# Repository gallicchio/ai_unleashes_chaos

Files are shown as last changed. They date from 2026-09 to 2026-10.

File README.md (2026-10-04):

# AI UNLEASHES CHAOS

[Lorenz Attractor Circuit](https://seti.harvard.edu/unusual_stuff/misc/lorenz.htm) by Paul Horowitz in KiCAD

"Claude, I want you to build a nice little present for Paul Horowitz, which could also live on as an open source project and a kit that people could build. Make a KiCAD 10 project, schematic, and PCB to implement [Paul's Lorenz Attractor Circuit](https://seti.harvard.edu/unusual_stuff/misc/lorenz.htm)."

<!-- GitHub strips <iframe> from READMEs, so a video cannot play in place;
     this is the thumbnail with a play button, linked to YouTube. -->
<p align="center">
  <a href="https://youtu.be/pzk5cd-qo5U" title="Watch on YouTube">
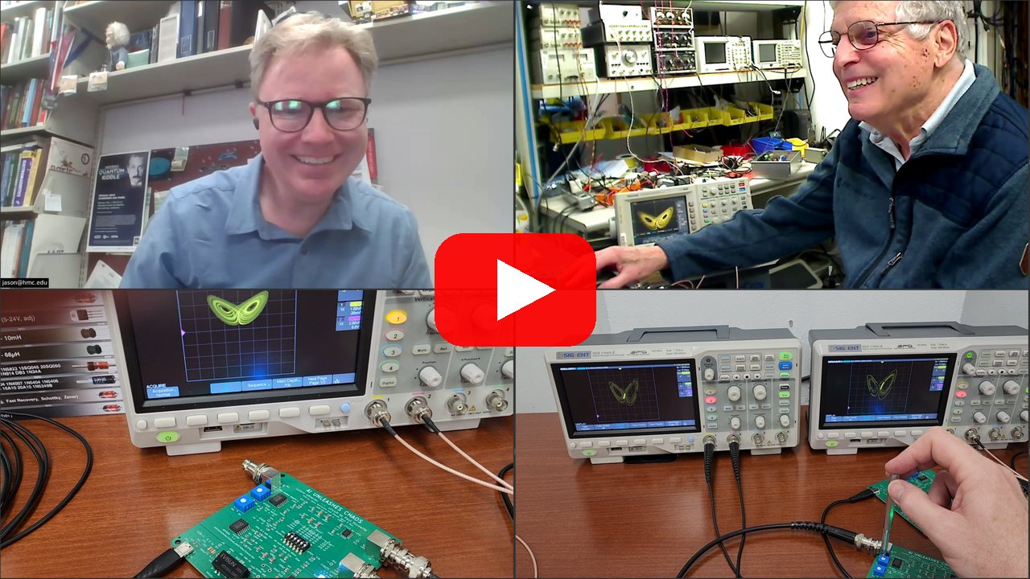
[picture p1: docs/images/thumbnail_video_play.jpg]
Watch the video on YouTube
    
  </a>
  <br>
  <a href="https://youtu.be/pzk5cd-qo5U"><b>&#9654; Watch on YouTube</b></a>
</p>

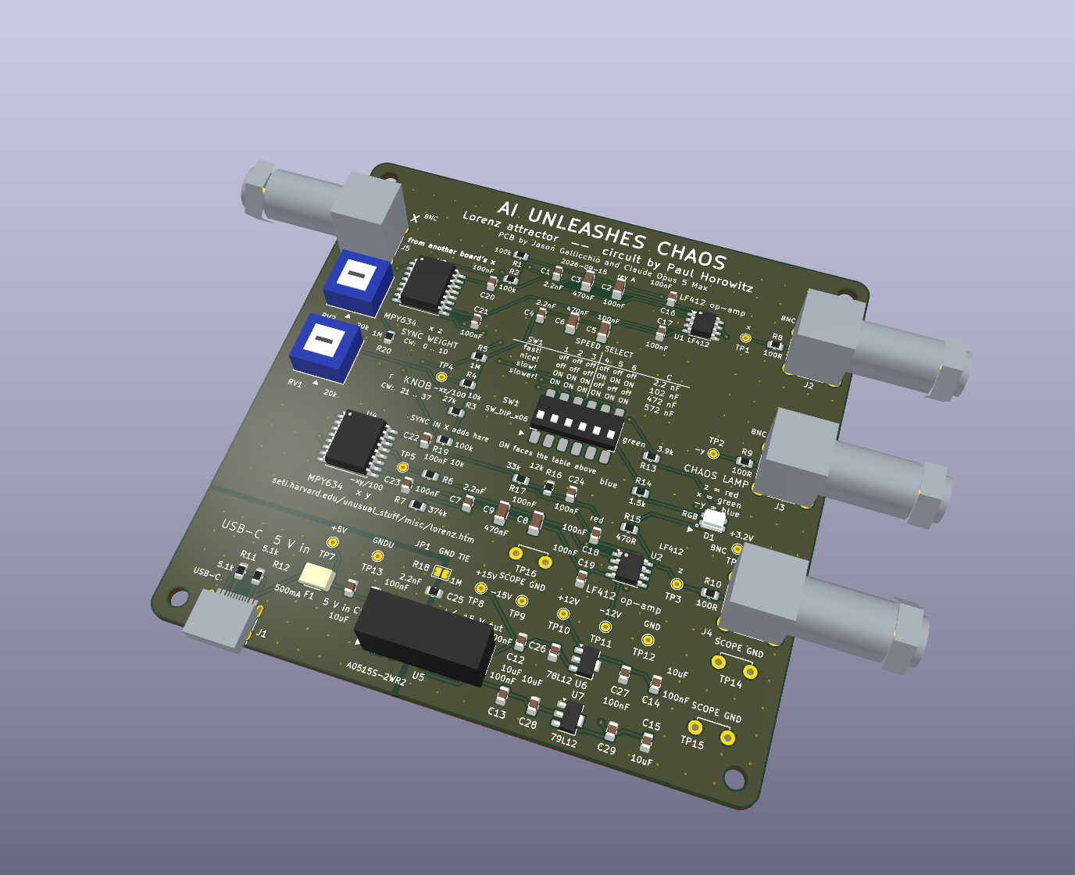
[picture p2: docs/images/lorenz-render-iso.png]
The board


In graduate school I worked with Paul Horowitz, of [Art of Electronics](https://artofelectronics.net/) fame. I even contributed a few bits and pieces to the 3rd edition. (I am thanked in the footnotes, one of which simply says, "Jason, again.") This project started by [asking Claude](CLAUDE_CODE_CHAT.md) the above question. Watch his reaction above. Also watch Paul's [Interview with Ladyada](https://www.youtube.com/watch?v=iCI3B5eT9NA) to get a sense for the guy.

**Only Prompts:**
As an experiment, the entire PCB, along with additions to Paul's original circuit were designed in a few
hours of [prompts to Claude Opus 5 Max](CLAUDE_CODE_CHAT.md). I only typed prompts.
I only used KiCAD to look at the output of Claude's [python scripts](scripts/), which generated everything else.

## What it is

A 100 x 100 mm, two-layer, USB-C-powered analog computer that solves

    dx/dt = s (y - x)          s = 10
    dy/dt = r x - y - x z      r = 21.3 .. 37.0, on a knob
    dz/dt = x y - b z          b = 8/3

in real time, continuously, with three op-amp integrators and two **MPY634**
analog multipliers — Paul's exact parts, in hand-solderable packages, so the
circuit stays literally his. Hang a scope on `x` and `z` in X-Y and the
attractor's "owl's face" appears within a second of power-up.

**Fun additions to Paul's original circuit:**

* **Four speeds on a DIP switch** — `fast!` (τ = 2.2 ms) through `slower!`
  (572 ms), the six sliders reading left to right as a two-digit binary
  number. At `slower!` you can follow the dot around a wing by eye.
* **An r knob.** 21.3 to 37.0 on a single-turn trimmer, which takes you from
  "the trace spirals into one wing and stops" through the bistable window at
  r ≈ 24.1–24.7 and Lorenz's own 28, to a tight fast orbit at 37. Its wiper is
  tied to one end of the track on purpose: grit under a wiper then means
  *maximum resistance*, never an open circuit.
* **A chaos lamp.** One RGB LED whose colour is the state vector. Red
  follows −y, green x and blue z, and two more resistors pull red's and
  blue's thresholds apart so the dies take turns instead of mixing to
  white: it is vivid nine-tenths of the time and visits every hue about
  equally. Rev A's lamp was picked from [660 rendered wirings](docs/lamp/)
  with an LED model the boards then proved wrong — it came out mostly blue —
  so rev B's was chosen again with a corrected model, from 6.7 million
  wirings; [the ten finalists play in real time](docs/lamp2/).
* **A real isolated ground split.** The DC/DC converter's isolation is
  actually used: analog ground and USB ground are separate pours with a 1 mm
  gap, bridged only by 1 M, 2.2 nF and a solder jumper, so no mains-referenced
  loop runs through a signal whose full scale is 2 V.
* **`SYNC IN X`.** A fourth BNC and a weight knob: feed it another board's `x`
  output and the two boards synchronise — chaotic synchronisation on the
  bench. Pull
  the cable and they diverge again from states that agreed to a few
  millivolts. The knob is linear in coupling strength from 0 to 10, with the
  locking threshold at about 70 % of rotation.
**Everything here is generated.** There is no hand-edited schematic or board:
`./make.py` writes the symbols, footprints, 3D models, schematic, placement,
routing, silkscreen, gerbers, BOM and CPL from Python, and then checks them.
147 circuit assertions read the exported netlist back and re-derive the
equations from the resistors that are really attached, and simulate the lamp
the netlist really builds; the QR codes on the
back are decoded out of the gerbers they were plotted into; and a clean clone
rebuilds every deliverable byte-identically.

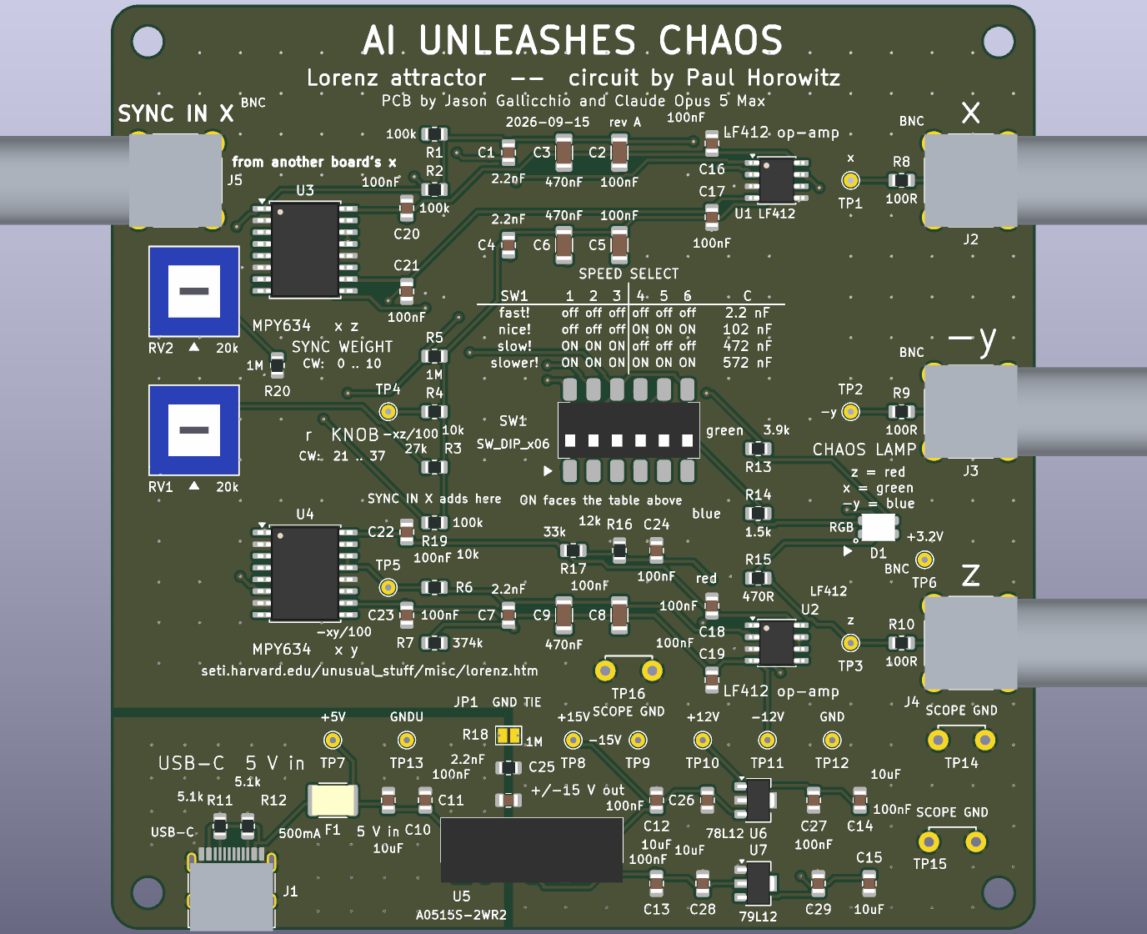
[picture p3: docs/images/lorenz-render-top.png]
Front

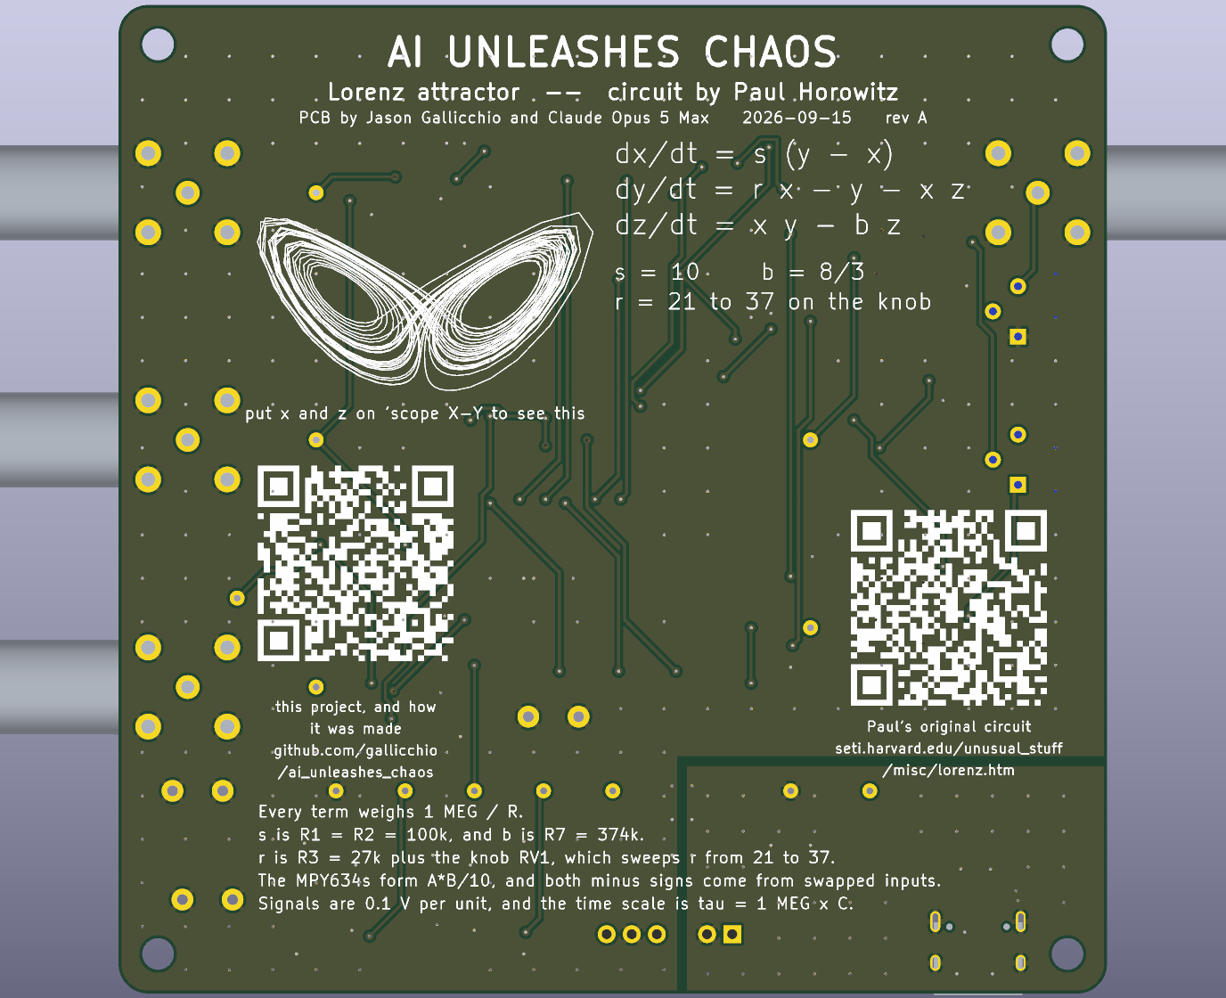
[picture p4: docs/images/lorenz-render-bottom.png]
Back


The back carries the equations, the owl's face drawn from a real integration
of them, and QR codes to Paul's page and to this repository.

## Building it

Needs KiCad 10, and Python 3 with `numpy` and `Pillow`; `pdftoppm`
(poppler-utils) for the preview images.

```bash
git clone https://github.com/gallicchio/ai_unleashes_chaos.git

cd ai_unleashes_chaos

# Nothing to configure if kicad-cli is on your PATH, or if a KiCad 10
# AppImage is in ~/.local/bin, ~/Downloads, ~/Applications, ~/bin or /opt:
# the build finds it and mounts it for as long as it runs.  Otherwise:
export KICAD_APPIMAGE=$HOME/.local/bin/kicad-10.0.6-x86_64.AppImage
# ...or, for an AppImage you have already extracted:
# export KICAD_APPRUN=$HOME/.local/kicad10/AppDir/AppRun

./make.py                # build and check everything  (~40 s)
./make.py --clean        # delete everything it generates
```

Upload `out/lorenz/lorenz-gerbers.zip` and `-bom.csv` to a fab, with
`-cpl_jlc_corrected.csv` for the placements if that fab is JLCPCB and
`-cpl.csv` if it is anyone else — JLCPCB turns six of the parts differently
from KiCad, and the corrected file is the same placements with those angles
applied. Read **[docs/MANUFACTURING.md](docs/MANUFACTURING.md)** first: it
lists what to check in the fab's preview before you pay.

## More

* **[docs/DESIGN_NOTES.md](docs/DESIGN_NOTES.md)** — the circuit, every
  changed value and why, and how the lamp was chosen.
* **[docs/DESIGN_REVIEW.md](docs/DESIGN_REVIEW.md)** — the design reviews,
  including the bugs the checks caught.
* **[CLAUDE_CODE_CHAT.md](CLAUDE_CODE_CHAT.md)** — the entire conversation
  that produced this board, prompt by prompt.

Circuit by Paul Horowitz. Board by Jason Gallicchio and Claude Opus 5 Max.

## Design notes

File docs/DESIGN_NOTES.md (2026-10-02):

# Lorenz Attractor — Design Notes

Reference: Paul Horowitz, <https://seti.harvard.edu/unusual_stuff/misc/lorenz.htm>

## The equations and how the circuit implements them

    dx/dt = s(y - x)          s = 10
    dy/dt = r*x - y - x*z     r = 21.3 .. 37.0, set by the knob (28 at 56 %)
    dz/dt = x*y - b*z         b = 8/3

Every coefficient is `1 MEG / R`.  Time is scaled by `tau0 = 1M * C`.
Circuit voltages represent the dimensionless variables at **0.1 V per unit**
(`V = 0.1 * var`), which is why the multiplier terms carry a factor of 100.

| Integrator | Op-amp | Feedback | Summing inputs | Yields |
|---|---|---|---|---|
| x  | U1A | C_x | R1 100k from `-y`, R2 100k from `x` | dx/dt = 10(y - x) |
| -y | U1B | C_y | R3 27k + RV1 0..20k from `x`, R4 10k from `-xz/100`, R5 1M from `-y` | dy/dt = r x - y - xz |
| z  | U2A | C_z | R6 10k from `-xy/100`, R7 374k from `z` | dz/dt = xy - 2.674 z |

Coefficient check: 1M/100k = **10** = s; 1M/(27k..47k) = **37.0..21.3** = r;
1M/374k = **2.674** = b (8/3 = 2.6667, 0.3 % high); 1M/1M = 1; 1M/10k = 100
cancels the multipliers' /100.

All three are *lossy* integrators — R2, R5 and R7 are local feedback around
their own op-amp, which is what produces the `-x`, `-y` and `-bz` damping terms.

### Multipliers (MPY634, Vout = A*B/10)
* **U3**: X1 = `x`, X2 = GND, Y1 = GND, Y2 = `z`  ->  (x)(-z)/10 = **-xz/100** (normalised)
* **U4**: X1 = `-y`, X2 = GND, Y1 = `x`, Y2 = GND ->  (-y)(x)/10 = **-xy/100** (normalised)

The sign inversions come free by swapping the differential inputs — no extra
op-amps.  Z1 ties to the output, Z2 to ground, SF (pin 3) left open for the
standard 10 V scale factor.

### Signal levels (k = 0.1 V/unit)
`x` = +/-2.0 V, `y` = +/-2.7 V, `z` = 0..4.8 V, multiplier outputs <= 1.0 V.
Comfortable inside +/-12 V rails.

## Changes from Paul's original, and why

1. **USB-C power instead of a bench +/-15 V supply.**
   5 V in -> `A0515S-2WR2` isolated 2 W module -> +/-15 V -> `78L12`/`79L12`
   -> **+/-12 V**.  The module alone is unregulated and rises toward +/-18 V at
   light load, which is uncomfortably close to the MPY634's +/-18 V absolute
   maximum; the two linear regulators pin the rails at +/-12 V and also strip
   the module's switching ripple.  MPY634 is specified from +/-8 V, so +/-12 V
   is well inside its range and leaves >2x headroom on every signal.

2. **100 ohm series resistors on the three BNC outputs.**  Isolates the
   LF412 outputs from coax capacitance (a JFET-input op-amp driving a metre of
   RG-58 will otherwise ring) and survives a shorted output.  Error into a
   1 Mohm scope input is 0.01 %.  They sit *outside* the feedback/summing
   network, so the equations are untouched.

3. **Speed switching.**  No 3-pole 3-position switch is stocked anywhere, so
   the three values are built up in parallel per integrator:
   `C_fast` 2.2 nF C0G is always fitted; a 6-way DIP switch adds 100 nF (bank A,
   poles 1-3) or 470 nF (bank B, poles 4-6) to all three integrators at once.

   Poles 1-3 carry the 470 nF and poles 4-6 the 100 nF, so the six sliders
   read left to right as a two-digit binary number:

   | setting | poles 1-3 (470 nF) | poles 4-6 (100 nF) | C      | Paul's value |
   |---------|--------------------|--------------------|--------|--------------|
   | fast!   | off                | off                | 2.2 nF | 2000 pF      |
   | nice!   | off                | **on**             | 102 nF | 0.1 uF       |
   | slow!   | **on**             | off                | 472 nF | 0.47 uF      |
   | slower! | **on**             | **on**             | 572 nF | —            |

   `slower!` is the fourth speed both banks on give you for nothing: tau =
   572 ms, a fifth slower again than `slow!`.  It is printed on the silkscreen
   table with the other three.  Contact resistance is
   ~100 mohm in series with C; against a 100 kohm..1 Mohm integrating resistor
   that is a 1-ppm effect.

4. **The isolation is used.**  The converter's output common is *not* tied to
   the USB ground.  The board has two grounds: `GND` downstream of the
   converter (op-amps, multipliers, BNC shells, everything a scope touches) and
   `GNDU` upstream of it (the USB connector and its shell, the CC pull-downs,
   the input bulk).  They are separate copper pours with a 1 mm
   gap, and the converter straddles it.

   The reason is specific to this board: its whole purpose is to be watched on
   an oscilloscope, whose ground clip is bonded to mains earth.  Tie the
   grounds and the loop runs scope earth -> BNC shell -> board ground -> USB
   cable -> laptop -> earth, and whatever that loop picks up lands on signals
   whose full scale is 2 V.  Isolated, the scope clip is the only thing that
   decides where analog ground sits.

   Three parts bridge the barrier, all of them already in the BOM:

   | part | value | what it does |
   |---|---|---|
   | R18 | 1 M | drains static, so the analog side cannot float up on charge |
   | C25 | 2.2 nF | 720 ohm at the converter's 100 kHz, 1.2 Gohm at 60 Hz |
   | JP1 | solder jumper, open | bridge it to give the isolation up |

5. **U2B drives the chaos lamp's reference.**  Paul also used only 1.5 of his
   two LF412s; this board spends the spare half on something useful.  A 15k /
   33k divider from +12 V makes **+3.75 V**, U2B buffers it, and that becomes
   the common *anode* of one RGB lamp.  Holding the anode above the signals is
   what lets signals that swing either side of zero drive an LED at all: a die
   conducts when the voltage at its cathode falls a forward drop below the
   anode.

   In rev B each cathode sees a small resistor network rather than one
   resistor:

   | die | fed from | through | what it is for |
   |---|---|---|---|
   | red | -y | R15 = 1.5k | the main feed: 73 % of what the cathode sees |
   | | x | R22 = 8.2k | blends in about a fifth as much x, which shifts where in each orbit red peaks |
   | | +12 V | R23 = 8.2k | lifts red's cathode 1.6 V, so red lights over the +x wing and fades on the -x wing |
   | green | x | R13 = 24k | lights over most of the orbit, brightest on the -x wing; 24k because green is the most efficient die per milliamp |
   | blue | z | R14 = 2.2k | the bottom of every loop, either wing |
   | | -12 V | R24 = 36k | lowers blue's cathode 0.7 V, which moves its threshold up the z swing |

   R23 and R24 are what make rev B saturated: they move red's and blue's
   thresholds independently of the shared anode, so the dies take turns
   instead of all being on at once.  Simulated with the corrected LED model,
   red is lit 75 % of the time (peak 1.8 mA), green 91 % (peak 0.13 mA) and
   blue 41 % (peak 0.7 mA).  Weighted for how bright each colour looks, the
   three peaks come out within a factor of two of each other.  U2B sources 1.9 mA at the
   peak and 0.6 mA on average, and R23 draws at most 1.5 mA from +12 V.

   What you see at `slow!`: on the +x wing the colour runs violet through
   magenta to red, on the -x wing green through cyan to azure, and through
   the crossings blue to orange.  It is vivid -- neither near white nor near
   black -- about 90 % of the time, and its vivid moments fill 11 of the 12
   30-degree hue sectors about equally.  At `fast!` the eye sees only the
   average, a steady violet.

   **Rev A's lamp was different, and duller than predicted.**  It was option
   038 of `docs/lamp/` -- 12k/33k for +3.20 V, z to red through 470 ohm, x to
   green through 3.9k, -y to blue through 1.5k -- chosen with an LED model the
   boards proved wrong: it came out mostly blue with some green.  See "What the
   rev A boards showed" and "The rev B search" below; rev B is candidate 1 of
   that search.

   The part is **MHPA3528CRGBCT** (LCSC C2962095), common anode: pin 1 is the
   anode, pin 2 blue, pin 3 green, pin 4 red, numbered clockwise from the
   bottom left in the top view.  Its common-*cathode* twin MHPC3528CRGBCT is
   the same dies in the same package with pins 1 and 4 swapped, so the two
   are not interchangeable on this board.  D1's footprint, position and
   rotation are exactly rev A's, which rev A's boards proved right.

   The lamp taps the op-amp outputs *before* the 100 ohm series resistors, so
   none of its current flows in the BNC output impedance.

6. **An r knob.**  R3 is split into a fixed 27k and RV1, a Bourns 3386P 20k
   single-turn cermet trimmer, which sweeps `r = 1M / (27k + RV1)` from 21.3
   to 37.0.  That covers the whole interesting range: r = 24.06 where the
   wings stop being an attractor, r = 24.74 where the two fixed points let go,
   Lorenz's 28 at 56 % of rotation, and up to 37 where the orbit tightens and
   speeds up.  About 0.05 in r per degree of screw at r = 28, so a setting can
   be found again by hand.

   RV1 is wired as a rheostat -- terminal 3 and the wiper -- with **terminal 1
   tied to the wiper**.  That short is deliberate: it takes the unused section
   of track out of circuit, and if grit ever lifts the wiper the full 20k
   track still bridges the branch, so r falls to its minimum instead of the
   `r x` term vanishing altogether.  A worn wiper fails open; this wiring does
   not let it.

7. **A synchronisation input, on its own BNC.**  `SYNC IN X` is a fourth BNC
   on the left edge of the board, in line with the x output on the right,
   because another board's x output is what you plug into it.  From there:
   RV2 as a plain voltage divider across the incoming signal, then R19 = 100k
   into the dy/dt summing junction, where it meets the x branch before the
   two of them reach the summing node.  R20 = 1M holds the wiper node at
   ground if the wiper ever lifts.

   It has to be that junction and it has to be x.  The junction inverts, so
   an injected voltage always arrives with a minus sign, and diffusive
   coupling `g(x1 - x2)` is only available where the local term already
   carries a plus -- which is the `+ r x` term of dy/dt and, through R1, the
   `+ s y` term of dx/dt.  dz/dt has no such term: an injected z arrives as
   `-g z1`, which is anti-diffusive, and simulated, the error grows with g
   rather than shrinking.  Sign-correct coupling on z *does* lock, so this is
   not a conditional-Lyapunov obstruction -- it just needs a `-z` output this
   circuit does not make.

   **The weight knob.**  RV2 is a divider, not a rheostat in series with R19,
   and that is the whole trick: the weight is then

       g  =  1M / 100k  x  (fraction turned)  =  0 .. 10

   which is *linear* in the knob, within 5 % -- the wiper's own source
   impedance peaks at a quarter of the 20k track against R19's 100k.  A
   rheostat would have made g go as 1/R and crammed everything interesting
   into the first tenth of the rotation.  At the counter-clockwise stop the
   wiper sits on ground and the branch contributes exactly nothing, which is
   the same thing as unplugging the cable; at the clockwise stop it is the
   g = 10 the board was already sized for.

   Simulated (two boards, b = 1M/374k, 20 mV of initial mismatch, the
   receiver's r knob turned down by g so both solve the same equations):

   | knob | g | what happens |
   |---|---|---|
   | 0 %   | 0    | nothing at all; the two boards ignore each other |
   | 20 %  | 2    | no lock, ever |
   | 50 %  | 5    | still no lock: close approaches, then bursts apart |
   | ~70 % | ~7   | threshold, measured at r = 32 |
   | 80 %  | 8    | locks in about 5 time units -- 2.2 s at `slow!` |
   | 100 % | 10   | locks in about 3 time units -- 1.5 s at `slow!` |

   So the bottom seven tenths of the knob is "influence you can see but
   never enough", and the top three tenths is "locked", which is the range
   the demonstration wants.

   Because the coupling lands on the `r x` term it also adds g to the
   receiving board's own r.  Drive at r = 32 and the receiver's r knob then
   reads 32 down to 22 as the sync knob goes 0 to full -- the two knobs track
   each other one for one across their whole travel, which is why the r knob
   was sized to sweep more than 10.

   Both boards float on purpose, so they also need a ground in common before
   any of this works: a coax from a BNC splitter carries board 1's ground on
   its screen and does both jobs at once, or run a second wire between a
   SCOPE GND loop on each board.  The 20k divider loads an output that drives
   through 100 ohm by 0.5 %, so the scope on the other leg of the splitter
   sees no difference.

## Choosing the chaos lamp

The RGB lamp is the one part of this board that is not Paul's.  It is also the
only part whose value could not be derived from the equations, so it was
chosen by building a model of the lamp and looking at every wiring of it.

### Why it is not obvious

An LED is a threshold device and the three signals swing either side of zero,
so "drive the LED from x" has no obvious meaning.  Four things have to be
decided together, and they interact:

1. **common anode or common cathode** -- which end of the dies the reference
   holds, and therefore whether a die lights when its signal goes *up* or
   *down*;
2. **which signal drives which die** -- six permutations of x, -y, z onto red,
   green, blue;
3. **the reference voltage** -- where the threshold sits inside each signal's
   swing;
4. **the three series resistors** -- which set both the peak brightness and,
   because luminous efficiency is nonlinear in current, the *shape* of each
   die's response.

Get these wrong and the lamp is a two-colour lamp with a third die soldered on
for decoration, or a white blur, or dark.

### The model:  `scripts/lamp_model.py`

Rather than guess, the board's colour is computed from the data sheet:

* **I-V per die**, as an ideal diode with a series resistance, back-solved so
  that each die passes exactly its data-sheet 20 mA at its data-sheet forward
  voltage:  `i_s = 0.020 exp(-(Vf20 - 0.020 Rs) / (n VT))`.
* **Luminous intensity**, `mcd = Iv20 (i / 20 mA)^gamma`, with gamma = 1.05
  for red and 1.15 for green and blue.  *(Corrected after the boards came
  back: this section said gamma came from the data sheet's own
  relative-intensity curve.  It did not.  That curve is a straight line,
  gamma = 1, and it stops at 1 mA.  Worse, gamma > 1 for green and blue is
  the wrong direction for InGaN.  See "What the rev A boards showed".)*
* **Spectrum**, a Gaussian from each die's peak wavelength and FWHM.
* **Colour**, by integrating that spectrum against the **CIE 1931 2-degree
  observer** (the real table, embedded at 5 nm) to get XYZ, then the D65 sRGB
  matrix to get a screen colour.
* **Adaptation**, a luminance compression before the sRGB gamma, because a
  dark-adapted eye looking at a small lamp does the same thing.  Without it
  the picture is a hard on/off and every shade in between is lost.

The model is self-checked, 13 assertions, run by `./make.py` before anything
else: equal-energy white must land on x = y = 1/3; the luminosity function
must peak at 555 nm; four published monochromatic chromaticities must come
back right; each die's computed dominant wavelength must be within 5 nm of the
data sheet's; the I-V must return 20 mA at the quoted Vf; and D65 must map to
neutral sRGB.  A colour model that cannot reproduce those is not worth
pointing at a circuit.

### The search:  `scripts/lamp_gallery.py`

The Lorenz system is integrated for real -- the same RK4 trajectory that draws
the owl on the back of the board -- and the three node voltages are fed into
the model sample by sample.  The result is rendered as a strip of time: left
to right, wrapping at the end of each row, about four minutes of the lamp at
the `slow!` setting in one picture.

**660 wirings** were rendered: 2 lamp parts x 6 permutations x 11 reference
voltages x 5 resistor rules.  Options that came out black, white or one flat
colour were dropped, and the rest thinned by a greedy max-min pass to the
**100 most different from each other**, written to `docs/lamp/` with an index
page to flip through.

### The pick, and what it has in common

Option **038** was chosen by eye from that gallery.  Measuring the nine
favourites against the other ninety-one afterwards showed what the eye had
been doing:

| | the nine | the other 91 |
|---|---|---|
| hue coverage (of a 24-segment wheel) | **0.71** | 0.42 |
| brightness balance (dimmest peak / brightest) | **0.375** | 0.056 |
| mean saturation | **0.269** | 0.347 |
| fraction of the time the lamp is lit | **1.00** | 0.91 |
| fraction of the time the *dimmest* die is lit | **0.19** | 0.00 |

The last row is the whole story: in **47 of the 100**, one of the three dies
never comes on at all.  None of the nine favourites was one of those.  The two
resistor rules that aim for equal *perceived* brightness rather than equal
current are 26 of the 100 options but 7 of the 9 favourites.  Ranked by
`hue coverage x sqrt(balance) x lit`, the nine come in at 1, 4, 5, 7, 11, 16,
22, 25 and 42 out of 100 -- and 038 comes first.

### What that settled, for rev A

* **Common anode**, MHPA3528CRGBCT, held at **+3.20 V** by the spare half of
  U2 -- so each die lights on the way *down*, and the lamp is never dark.
* **z to red through 470 ohm, x to green through 3.9k, -y to blue through
  1.5k.**
* Peak brightnesses of 38.1, 36.3 and 38.9 mcd -- within 8 % of each other,
  which is what makes the colour a mix rather than one die with hints of the
  others.

What the model said you would see: mostly deep blue, with a fast swirl
through the colour wheel every time the trajectory changes wings, and a red
flash at the bottom of each z excursion.  Turning the r knob changes it -- at
the counter-clockwise stop the lamp stops changing colour altogether, because
the attractor has collapsed to a fixed point.

### What the rev A boards showed

The rev A boards were built exactly as option 038 -- netlist, part and orientation all
check out, and a lamp fitted any other way could not show blue and green at
all.  But the lamp is mostly blue with some green, and anything else is rare.
The model was wrong at two links of the chain, and `scripts/lamp_model.py`
now carries both the model rev A was chosen with (`REVA`) and a corrected one
(`MHPA3528`):

| | rev A's model | corrected |
|---|---|---|
| red at 0.1 mA | 1.36 V | 1.64 V |
| green at 0.1 mA | 2.02 V | 2.40 V |
| blue at 0.1 mA | 2.07 V | 2.52 V |
| red light per mA at 1 mA, against 20 mA | 0.86x | 0.71x |
| green, the same | 0.64x | 1.52x |
| blue, the same | 0.64x | 1.28x |

* **Voltage to current.**  Ideality factors of 3.2 and 5 had every die
  conducting 0.3-0.45 V too early.  The corrected curves are typical of the
  two materials at 0.1 mA, and still land each die's 20 mA voltage inside
  the datasheet's min-max column.
* **Current to light.**  InGaN (green, blue) peaks in efficiency at a few
  A/cm^2 -- about a milliamp for a die this size -- and droops above it, so
  at the lamp's currents it is *more* efficient than at 20 mA.  AlGaInP
  (red) is still gaining efficiency at 20 mA and loses it below a few mA.
  The corrected model uses the ABC model for InGaN and SRH-plus-radiative for
  AlGaInP.  Of all the corrections this one matters most: on its own it
  takes red from 10 % of rev A's light to 4 %.
* **Light to brightness.**  A saturated blue looks about 1.7 times brighter
  than its luminance says, red 1.5, green 1.2 (the Helmholtz-Kohlrausch
  effect, Ware and Cowan's formula).  The judge now uses that.
* **Brightness in time.**  The eye averages colour over a few tens of
  milliseconds.  The corrected red flashes last about 20 ms, so they are
  averaged away; the rev A pictures, which drew every 4.7 ms sample as a
  pixel, showed them all.

Together: red went from 9.7 % of rev A's light to 2.7 %, and its warm flashes
from 38 a minute at about 50 ms each to 9 a minute at about 20 ms.  Under
the corrected model rev A's lamp spends its vivid moments 43 % azure, 23 %
blue, 33 % green-to-cyan and 1 % anything else -- which is what the boards
do.

The colour science itself held up: each die's computed dominant wavelength
is within 3 nm of its datasheet.  What also has to change is the goal.  The
rule that chose rev A rewarded all three dies contributing, which is the
recipe for mixtures -- cyan and white -- and not for saturated hues.

### The rev B search

`scripts/lamp_search.py`, `lamp_search_mix.py` and `lamp_search_reva.py`
search again under the corrected model, and `scripts/lamp_gallery2.py`
writes the finalists to `docs/lamp2/index.html`.  Each wiring is judged on:

* **vivid**: the fraction of the time the lamp is neither near black
  (perceived brightness under a sixth of its own bright end) nor near white
  (under three quarters of the way to the most saturated colour the dies
  can make in that hue, a limit reached exactly when no more than two dies
  are lit);
* **hues**: how evenly those vivid moments spread over the twelve 30-degree
  sectors of the OKLab hue circle, as exp(entropy) / 12;
* **score** = vivid x hues, after the eye's 20 ms two-stage filter at
  `slow!`.

About 6.7 million wirings were judged: every rev-A-style wiring
(3.3 million, exhaustively, on E6 resistors, then polished on E12), rev A
plus one resistor (1.7 million, a grid), and dies with thresholds of their
own or blends of two signals (1.8 million, by evolutionary search).  Every
finalist was then re-judged against 24 LEDs drawn from what the datasheet
allows -- brightness bins, forward voltage, and the uncertainty in the
efficiency curves -- at r = 26, 28 and 31, and ranked on the median.
Designs that stand more than 2 mA in an offset resistor or run a die above
5 mA were set aside.

Rev A scores 0.33 on that test.  The best rev B candidates score 0.77-0.78,
and one of them is rev A's own wiring with one more resistor.  See
`docs/lamp2/` for all ten finalists, playing in real time.

Rev B is built with **candidate 1**, the top scorer.  Re-judged against 96
fresh LEDs at five settings of the r knob it scores 0.805 (90 % interval
0.801-0.809), statistically tied with candidate 2 at 0.804 and clear of the
rest.  `check_circuit.py` now reads the lamp back out of the netlist, checks
it is that wiring, and simulates it -- the build fails if the board's own
lamp scores below 0.70.

## Part selection (JLCPCB stock checked 2026-09-15)

| Ref | Part | LCSC | Package | Stock | Unit |
|---|---|---|---|---|---|
| U1,U2 | LF412CDR | C15322 | SOIC-8 | 1037 | $0.91 |
| U3,U4 | MPY634KU/1K | C1523457 | SOIC-16-300mil | 874 | $30.59 |
| U5 | A0515S-2WR2 | C19272710 | SIP-7 THT | 255 | $1.60 |
| U6 | CJ78L12 | C8615 | SOT-89 | 52154 | $0.10 |
| U7 | CJ79L12 | C8626 | SOT-89 | 11413 | $0.12 |
| J1 | TYPE-C-31-M-12 | C165948 | SMD | 230097 | $0.19 |
| J2-J5 | BNC-KYWE-295-W4-N | C41416668 | THT right-angle | 410 | $1.55 |
| SW1 | DSIC06LSGET | C54952 | SMD DIP-6 | 2140 | $0.57 |
| D1 | MHPA3528CRGBCT | C2962095 | PLCC-4 3.5x2.8 | 9796 | $0.07 |
| RV1,RV2 | 3386P-1-203LF | C116287 | 9.5 mm square THT | 767 | $0.45 |

LF412 and MPY634 are Paul's exact parts — both still stocked, both in
hand-solderable wide-body packages, so the circuit stays literally his.

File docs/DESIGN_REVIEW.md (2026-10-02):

# Design review

Written after the board passed everything, going back over it looking for what
is wrong rather than what is finished.  Things I changed are marked **fixed**;
things I decided to live with say why.

## The circuit

**MPY634 is end-of-life at TI.**  The datasheet is stamped OBSOLETE, though the
grey shading shows that applies to the AM/BM/SM grades and not to the KP/KU
commercial parts this board uses.  874 MPY634KU were in stock at JLCPCB on
2026-09-15, which is 437 boards' worth, so this is not a problem today and is
a problem eventually.  The honest successor is the AD633 -- same A*B/10
transfer function, so the resistor values would not change at all -- but every
AD633 variant showed **zero** stock at JLCPCB, which fails the "do not wait for
out-of-stock items" requirement outright.  I chose availability now over
longevity, and documented the swap.

**Running the multipliers at +/-12 V rather than +/-15 V.**  The MPY634's
accuracy is specified at +/-15 V; at +/-12 V it is inside its +/-8 V to +/-18 V
operating range but no longer at its rated operating point.  It does not matter
here -- the largest signal on the board is z at 4.8 V and the largest multiplier
output is about 1 V -- and the alternative is worse: the converter is
unregulated, and at this board's light load its +/-15 V output climbs toward
+/-17 V, which is close enough to the +/-18 V absolute maximum that a different
vendor's module could take the part out.  Regulating down to +/-12 V also
removes the converter's 100 kHz ripple, which the op-amps' PSRR would not.

**The 470 nF "slow" capacitor is X7R, not C0G.**  Nobody makes a 470 nF C0G
part in a package you would put on this board.  X7R has a voltage coefficient,
so at the slow setting the integrator's time constant depends a little on the
signal across it, which is a mild nonlinearity fed straight into a nonlinear
system.  The attractor is structurally stable and this only wobbles the time
scale by a few percent, but it is a real compromise: the "nice!" setting uses a
100 nF **C0G** part precisely because that one can be had, and it is the
setting I would trust for anything quantitative.

**Six switch actuators for three speeds.**  I would rather have fitted one
three-position knob.  No supplier stocks a three-pole three-position switch, and
the three integrators have to change together or the attractor distorts, so the
capacitance is built up in parallel behind two banks of three DIP poles.  The
silkscreen carries the table.  This is the part of the design I like least.

**The regulators cost a quarter of the board's current.**  78L12 and 79L12 draw
about 5 mA each of quiescent current against roughly 25 mA of actual load
(op-amps, multipliers, the lamps and the lamp reference).  That
is the price of clean rails and it fits inside the 2 W converter comfortably;
with the 1 W part it would be tight, which is why the 2 W part is the one in
the BOM.

**Checked and fine:** JFET inputs mean bias current through R5 = 1 M contributes
50 microvolts, not millivolts.  The switch sits between the capacitor and the
op-amp *output*, both low-impedance nodes, so contact resistance and leakage do
nothing.  The circuit self-starts, because at r = 28 the origin is a saddle and
op-amp offset is orders of magnitude more than the push it needs.  The LF412
has 3 MHz of gain-bandwidth against about 700 Hz of circuit bandwidth at the
fastest setting.

## The schematic

**U1 does two rows.**  Paul's sheet reads as three integrators stacked down the
page, and so does this one, but one LF412 carries the x and -y integrators, so
the packages do not line up with the rows.  That is inherent in using Paul's
part; the alternative is three separate packages, which is worse.

**A2 rather than A3.**  Spreading out far enough that no label touches anything
else, with the equations, the parameter table and the attractor all on one
sheet, did not fit on A3.  It prints legibly reduced to A3.

**Labels: one readable name per net, and as many drawn notes as help.**  Paul
draws no labels at all.  This sheet has exactly one KiCad label per net -- `x`,
`-y`, `z`, `xz`, `xy`, `SJ_X`, `SJ_Y`, `SJ_Z` -- so that the netlist, the DRC
report and `check_circuit.py` all talk about the circuit in its own vocabulary
rather than in `Net-(U1A-Pad1)`.  That is a different thing from the *drawn*
annotation: the name `x` also appears beside the bus every time it leaves for a
load, exactly the way Paul does it, because that is a comment and not a
connection.  A KiCad label is a wire; a drawn note is not, and the sheet is
allowed to have plenty of the second kind.

## The PCB

**The BNC footprint is drawn from a vendor drawing, not a part in my hand.**
This is the single biggest risk in the package.  The dimensions come from the
SAMZO drawing's own "PCB LAYOUT" box -- four ground posts on an 8 x 8 mm square,
centre pin in the middle -- and the three listed alternates are all the same
"BNC-KYWE" body, but none of that is the same as offering up a real connector.
`out/lorenz/lorenz-assembly-top.pdf` prints 1:1 for exactly this check.

**The routing wanders.**  A person would have routed this more tidily; the maze
router takes the cheapest path it can find, which is not always the prettiest.
At these frequencies -- the fastest setting puts about 700 Hz through a 1 Mohm
scale of impedances -- trace length and shape are irrelevant, and the ground
plane under every signal matters far more than the route above it, so I left it.

**438 vias, most of them plane stitching.**  More than strictly needed.  They
cost nothing at a standard fab and they are what finally connected the last
island of the front pour, so they stay.  The USB island gets a denser lattice
(3.5 mm rather than 4.5 mm) because it is small enough that a few tracks can
carve it into pieces.

**Thirteen probe pads, and deliberately none on the summing junctions.**  Every
DC rail gets a plated hole with its name beside it -- +5 V, +/-15 V, +/-12 V,
both grounds -- and so do the five interesting signals: the three outputs and
the two multiplier products, `-xz/100` and `-xy/100`.  Three wire loops take a
scope's ground clip.

The summing junctions do not get one, and that is a choice rather than an
oversight.  A summing junction is a virtual earth: its *voltage* is zero by
construction and carries no information, while the quantity the annotation
names -- dx/dt -- exists there only as a current.  Worse, it is the one node on
the board where a scope probe would actually change the answer: 15 pF of probe
capacitance against a 1 Mohm scale of impedances is a 15 microsecond pole
hanging off the integrator's input.  What you can do instead, and what makes
this a good teaching board, is check that each junction really sits at 0 V --
and for that the resistor pads themselves are the right place to put a tip.

**Fixed while reviewing:**

* Four M3 mounting holes.  Three BNCs along one edge means cables lever on the
  board every time they are plugged; it needs standoffs, and there was nowhere
  to put a screw.  D1 and R13 moved to clear the fourth corner.
* The `.gitignore` inherited from the Python template has unanchored `lib/` and
  `parts/` rules.  `hardware/lib/` -- every symbol and footprint this project
  draws itself -- was not in the repository at all.  Anchored them to the root.
* `check_schematic.py` found one note hanging off the left edge of the frame,
  then immediately caught the mounting-hole caption when I dropped it on the
  title block.
* Ground pads were starving the zone's thermal reliefs (an 0805 or SOIC pad is
  too small for two spokes).  Switched to `THT_THERMAL`: solid on SMD, relieved
  on through-hole so the BNCs and the converter stay hand-solderable.

## Four bugs the checks caught that I would not have

Worth recording, because each one produces a board that looks right:

1. **Vias were checked against track clearance, not their own.**  A 0.6 mm via
   needs more room than a 0.3 mm track; the router was dropping them 0.1 mm
   from other nets.
2. **A custom-shaped pad is not centred on its anchor.**  The SOT-89 tab's
   bounding box sits 1.9 mm off its pad position, so the router happily ran the
   -15 V rail straight across U6's ground tab.
3. **A track halo has to include the next track's half width.**  Two 0.3 mm
   tracks were ending up 0.05 mm apart.
4. **A net has to be allowed onto its own copper.**  Clearance does not apply
   between a pad and the track landing on it -- without that rule a 0.3 mm
   USB-C pad, which its neighbours' halos completely cover, is unreachable.

Numbers 1 and 3 are clearance violations DRC would have caught anyway.  Number
2 is a short.  Number 4 just made two nets unroutable.

## Prompt 2: what changed, and what I decided against

**The isolation is now used.**  The A0515S-2WR2 really is isolated -- 1 kV, no
DC path between input and output -- and the board was throwing that away by
tying COM to the USB ground.  It no longer does.  GND (everything downstream of
the converter: both op-amps, both multipliers, the BNC shells) and GNDU (the
USB connector, its shell, the CC pull-downs, the input bulk, the +5 V lamp) are
two separate copper pours with a 1 mm gap, and U5 straddles the gap with its
own 5.08 mm barrier over it.

Why this is worth doing on *this* board in particular: its entire purpose is to
be looked at on an oscilloscope, and an oscilloscope ground clip is bonded to
mains earth.  With the grounds tied, the loop runs scope earth -> BNC shell ->
board ground -> USB cable -> laptop or charger -> back to earth, and whatever
current that loop carries appears as an offset and a 50/60 Hz wobble on signals
whose full scale is 2 V.  Isolate, and the scope clip is the *only* thing that
decides where analog ground sits.

The barrier is not left completely open: R21 = 1 M drains static so the analog
side cannot float up on charge, and C25 = 2.2 nF gives the converter's ~100 kHz
common-mode current a low-impedance way home without doing anything at all at
60 Hz (1.2 Gohm there).  Both were already in the BOM, so the whole
arrangement costs two 0805s.  JP1 is an open solder jumper: bridge it and the
two grounds are hard-tied again, which is the right thing if you ever want to
drive the board from a supply that shares a ground with your signal source.

The argument against, which I do not find convincing here: a floating section
is a section nobody has defined the potential of, and if you touch it while it
is charged you get a small spark.  At +/-12 V into a 1 M bleeder there is
nothing to discharge.

**The chaos lamp, and how the negative-going problem is solved.**
*(Superseded at prompt 4, which flipped the lamp to a common anode at +3.2 V
and rewired the colours; see the prompt 4 section at the foot of this file.
The argument below is unchanged -- only the sign of it is.)*  One
common-cathode RGB LED, red from x, green from -y, blue from z, with the
*cathode* held at -1.5 V by the half of U2 that Paul never needed.  That single
trick is what makes the negative excursions usable: each colour now lights only
when its own signal rises above -1.5 V plus that colour's forward drop, which
works out at x > +0.25 V, y < -1.1 V and z > +1.1 V.

Red therefore marks the +x wing and green the -x wing, so the lamp alternates
red and green as the trajectory switches wings -- which *is* the chaos -- while
blue brightens with z and drops out at the bottom of each excursion.  In
"slow!" (tau = 472 ms) that happens on a timescale you can watch; in "nice!" it
is a flicker; in "fast!" it averages into a colour.

The nonlinearity Paul worried about is real and, for this purpose, a feature:
an LED with a series resistor is a soft threshold, and a threshold is exactly
what turns a continuous variable into "which wing am I on".  A proportional
current drive would give a smooth fade and lose the switching.  The three
resistors are sized for roughly equal *perceived* brightness from the
datasheet's luminous intensities -- 1.5 k for red, 6.8 k for green (green is
about five times brighter per milliamp and sits where the eye is most
sensitive) and 4.7 k for blue -- so the colour you see is a fair mix rather
than green with hints.  Peak current is 2.2 mA for all three together, which
U2B sinks without noticing.

`check_circuit.py` recomputes the reference, every threshold, every peak
current and the worst-case reverse voltage on each junction from the resistors
that are actually fitted, so none of those numbers can drift away from the
board.

**Three rail lamps instead of one "rails OK".**  The old single green LED hung
off +12 V and claimed to mean "rails OK".  It did not: it said nothing about
-12 V and nothing about the USB input, so it could sit there looking healthy
with half the board dead.  Now there is one lamp per rail -- yellow on +5 V
(on the USB side of the barrier, where it belongs), green on +12 V, white on
-12 V -- each with its own name on the silkscreen next to it.  Three different
colours, all three JLCPCB Basic parts, so a dark one names itself without
anybody reading the legend.  Not red: red reads as "fault" when here it would
mean the rail is up, and red, green and blue are already spoken for by the
chaos lamp.

**The four-layer board is gone.**  The measurement that decided it: on the
routed two-layer board, tracks cover **1.2 % of the back copper** and 2.6 % of
the front.  The back is therefore already 98.8 % of an unbroken ground plane,
and a dedicated plane layer recovers that last one per cent.  Against that,
four layers costs roughly four times the bare-board price, doubles the number
of gerber sets somebody can pick the wrong one of, and -- now that the ground
is split for isolation -- the split would have to be drawn on four layers
instead of two.  The fastest thing on the board is a 100 kHz switching
converter and the signals are DC to about 700 Hz.  It bought nothing worth
having, so it is out; `route.py` and `gen_pcb.py` still take a layer count, and
the history is in git.

**QR codes drawn from scratch.**  Nothing in KiCad draws one and the build must
work from a bare clone, so `scripts/qrcode_gen.py` is a QR encoder: byte mode,
versions 1-6, level L or M, Reed-Solomon over GF(256), all eight masks scored.
Two things made this worth the trouble rather than dangerous:

* It is checked three ways.  Its Reed-Solomon, data placement and format
  information match the `qrcode` package module for module; its mask penalty
  scoring matches segno's on 200 random matrices; and the 32 published format
  words come out of its BCH.  Both reference libraries were installed only to
  check against and are not build dependencies.
* The finished board is decoded back.  `check_outputs.py` reads the rectangles
  out of `lorenz.kicad_pcb`, samples them into a matrix and runs the decoder,
  which verifies the BCH, every Reed-Solomon block's syndromes, and the
  payload.  A QR code is the one thing on this board that can be completely
  wrong while still looking right.

Two details that would each have shipped a broken code.  The modules have to
*touch*: a decoder finds the symbol by the 1:1:3:1:1 run lengths across a
finder pattern, and any gap at all breaks that -- I measured it, a 10 % gap is
already fatal.  And the code has to be mirrored in board coordinates, exactly
like back-layer text, or it reads correctly only through the board; I settled
that by plotting a back-layer legend beside it and seeing which way round the
legend read.

**The switch table.**  Rebuilt on both the sheet and the silkscreen.  On the
board it now sits directly over the switch, with each `off`/`ON` cell centred
on the slider it refers to, a silkscreen bar between the two banks of three,
the speed naming the row, and the capacitance and time constant in their own
columns on the right.  The middle capacitor bank moved 4 mm further from its
row to make the band above the switch wide enough -- that asymmetry is there
for the legend, and it is the right trade.

**Cross-probing.**  It was not working because the footprints carried no link
back to their symbols.  Each footprint now stores the symbol's UUID as its
sheet path, plus `sheetname` and `sheetfile`, and the project file carries the
root sheet in its `sheets` list.  Clicking a part in one editor now highlights
it in the other.

**A fifth bug, found by the reproducibility check.**  Splitting the ground
made the build stop being byte-reproducible: four consecutive builds of an
unchanged design produced four different boards.  The router and the placement
were both deterministic; the zone *filler* was not.  Two zones of equal
priority on one layer are filled in whichever order the filler's threads reach
them, and the two orders differ in the last nanometre of every arc -- about
0.01 % of the copper area, scattered as thousands of sub-micron slivers.
Giving GNDU a higher priority than GND ranks them, and eight consecutive fills
then give one answer instead of four.  The outlines do not overlap, so the
ranking changes nothing about the board.

Worth recording because of how it would have shown up: not as a wrong board,
but as a `git diff` of four thousand lines every time anybody rebuilt, which is
exactly the noise that hides a real change.

**Still not right, and I know it:**

* The routing still wanders.  The maze router takes the cheapest path, not the
  prettiest one, and a person would have done better.
* The board is dense.  100 x 100 mm holds 84 footprints, sixteen of which are
  probe pads, and the front silkscreen is close to full.  Anything else would
  need a bigger board.
* `ON` on a DIP switch is marked on the package, and I have not held one.  The
  silkscreen says so rather than guessing a direction.

# Prompt 3: the full review

Worked through item by item.  Where a check could be made to run every build
rather than once, it was; those are named.

## Four bugs, in order of how badly they would have hurt

**1. DRC was not reading this project's design rules at all.**  `pcbnew` writes
a `.kicad_pro` next to any board it saves, with a default set of rules, and
`make.py` only regenerated the real one at the very end -- after DRC.  So every
"DRC: 0 violations" this project has ever printed was measured against KiCad's
defaults, not against the rules in `gen_project.py`.  Regenerating the project
file immediately before DRC turned up **203 violations** that had been there
all along.  The zone filler had the same problem from the other side: it works
from the *board's* settings, and a board made by `CreateEmptyBoard()` carries
defaults, so the pour was backing off 0.25 mm from holes while the rule asked
for 0.3.  Both are fixed; `apply_rules()` now sets them on the board before
anything is filled.

This is the worst kind of bug: a check that reports success while checking
nothing.  Everything below was found only because it started working.

**2. Every via violated the annular-ring rule.**  0.6 mm outside diameter on a
0.3 mm drill is 0.15 mm of annulus, against a rule asking for 0.25.  Vias are
now 0.8/0.3 -- 0.25 mm -- and the rule sits at 0.20, because the binding item
turned out to be the four shell tabs of KiCad's own USB-C footprint, which are
0.20.  0.20 is still well above the 0.13-0.15 mm the three fabs quote; the
board's own vias and pads are all 0.25 or better.

**3. Stitching vias were necking the pour beside through-hole pads.**  A via
placed 1.5 mm from a 2.2 mm ground pad leaves a 0.08 mm isthmus of copper
between them -- legal for clearance, since they are the same net, and caught
only by the minimum-connection-width check.  It is also pointless: a
through-hole pad already connects every layer, so it *is* a stitching via.
The router now refuses to place one within 0.35 mm of a drilled pad and skips
the per-pad via for through-hole pads entirely.

**4. Both multipliers had no designator on the silkscreen.**  The legend
placer avoided pads and other legends but not the package body, so `U3` and
`U4` were printed neatly underneath the chips.  It now treats every
footprint's courtyard as occupied, which is the rule that should always have
applied: silk under a part is silk nobody reads.

## Packages, rotations and pin assignments

Checked mechanically: 82 footprints, none flipped, all on `F.Cu`, every
rotation 0 or 90 degrees, no mirrored text on the front.  (Two *symbols* are
mirrored on the sheet -- U2B and the lamp, because the lamp is fed from the
right -- which has no effect on the board.)

`scripts/check_pinout.py` now runs in every build.  It writes out each IC's pin
table from the datasheet named in the code, compares it with the symbol this
project actually uses, and -- where KiCad ships the same part -- compares it
again with KiCad's library, drawn by other people from the same document:

| part | datasheet | second source |
|---|---|---|
| MPY634 SOIC-16 | TI SBFS017A, "PIN CONFIGURATIONS", 'KU' column | `Analog:MPY634KU` |
| LF412 SOIC-8 | TI SLOS091 | `Amplifier_Operational:LM2904` |
| CJ78L12 SOT-89 | Changjiang outline: 1 OUT, 2 GND, 3 IN | `Regulator_Linear:MC78L05_SOT89` |
| CJ79L12 SOT-89 | Changjiang outline: 1 GND, 2 IN, 3 OUT | `Regulator_Linear:L79L05_SOT89` |
| A0515S-2WR2 | YLPTEC pin table, dual-output column | -- |
| MHPC3528CRGBCT | MEIHUA LPDS-0001482 Rev.1 p.2 | -- |

Two of these are worth calling out.  The SOT-89 tab is pin 2, which is *ground*
on the 78L12 and the **input** on the 79L12 -- so U7's tab sits at -15 V, not
at ground, and a footprint drawn for the positive part would have shorted it.
And the A0515S's pins are 1, 2, 4, 5, 6 with no pin 3; the gap is the module's
own isolation barrier, and this board puts the plane split through it.

## Power, traced from the connector

    J1 VBUS x4 -> F1 500 mA PTC -> +5V -> C10 10uF + C11 100nF -> U5 pin 1
    J1 GND x4 + shell ------------------------------------------> U5 pin 2
    U5 pin 6 +15V -> C12 + C26 -> U6 pin 3 -> U6 pin 1 +12V -> C27 + C14
    U5 pin 4 -15V -> C13 + C28 -> U7 pin 2 -> U7 pin 3 -12V -> C29 + C15
    U5 pin 5 COM  -> GND
    +12V -> U1.8  U2.8  U3.16  U4.16     each with its own 100 nF
    -12V -> U1.4  U2.4  U3.10  U4.10     each with its own 100 nF

| rail | load | headroom |
|---|---|---|
| +12 V | 20.0 mA | 78L12 rated 100 mA |
| -12 V | 19.5 mA | 79L12 rated 100 mA |
| +15 V | 25.0 mA | module rated 67 mA; minimum load 7 mA, so 3.5x over it |
| -15 V | 24.5 mA | as above |
| USB 5 V | 186 mA at 80 % efficiency | 500 mA PTC |

Regulator dissipation is (15 - 12) x 25 mA = 75 mW each in a SOT-89, which is
a seventh of what the package will take.  The converter delivers 743 mW of its
2 W.  Nothing here is close to a limit, and the one number that could have
been -- the module's **minimum** load of 7 mA per rail, below which its output
climbs -- is met 3.5 times over, which is why the rails sit near 15 V and the
regulators keep their dropout margin.

**Decoupling** was the one place the review actually changed the circuit.  The
78L12 and 79L12 datasheets are characterised with 0.33 uF in and 0.1 uF out,
"located as close as possible", and the 10 uF bulk capacitors were 15 mm away.
Four 100 nF parts, C26 to C29, now sit at the regulators' own pins.

## Impedances, and what drives what

| source | impedance | load | error |
|---|---|---|---|
| LF412 output | ~0.01 ohm closed loop | 100 ohm to a 1 Mohm scope | 0.01 % |
| LF412 output | " | summing resistors 10k..1M into a virtual earth | none |
| LF412 output | " | MPY634 X/Y input, 10 Mohm | none |
| MPY634 output | 1 ohm, +/-10 mA | 10k summing resistor | none |
| U2B output | ~0.01 ohm | three LEDs, 2.2 mA peak | none |
| 4.7k/33k divider | 4.1k Thevenin | LF412 JFET input, 50 pA | 0.2 uV |

The one thing to say out loud: the BNC outputs are meant for a **1 Mohm**
scope input.  Into a 50 ohm termination the 100 ohm series resistor divides the
signal by three.  That is the right trade for a circuit whose output is a slow
voltage and whose op-amp does not want a metre of coax hanging directly off it.

## Input ranges against the datasheets

| part | limit | worst case here |
|---|---|---|
| MPY634 X, Y, Z inputs | +/-10 V linear, +/-Vs absolute | 2.6 V |
| MPY634 output | about +/-9 V at +/-12 V rails | 1.2 V |
| LF412 common mode | about +/-8 V at +/-12 V rails | 0 V, and -1.5 V at U2B |
| LED reverse | 5 V | 1.2 V, computed per colour from the netlist |
| converter input | 4.5 - 5.5 V | 5 V USB |
| 78L12 / 79L12 input | 35 V max, ~14.2 V min for 12 V out | 15 - 15.5 V |
| C0G 2.2 nF, 50 V | 50 V | 5 V |

JFET-input op-amps invert their output if the common mode goes below the
negative limit; both inverting inputs are virtual earths at 0 V and U2B's
non-inverting input is at -1.5 V, so nothing goes near it.

## Configuration pins

`SF` on both multipliers is left open, which selects the 10 V scale factor --
the one the whole resistor network is sized for; a resistor to -Vs there would
change it to 3 V and multiply every product by 3.3.  Both multipliers' six NC
pins are unconnected.  On the USB-C receptacle, CC1 and CC2 get **one 5.1k
each, not a shared one**, which is what tells a source to turn 5 V on; D+, D-,
SBU1 and SBU2 are unconnected; all four VBUS and all four GND pins are tied.
The DIP switch has no configuration pins.  `check_circuit.py` asserts all of
this from the netlist.

## The split ground, re-examined

Still the right call, and now checked rather than asserted.  `gen_pcb.py`
refuses to build if any net has pads on both sides of the gap, apart from the
converter and the three bridge parts, and refuses if any track or via strays
across.  The consequences that matter:

* The only analog-side connection to anything mains-referenced is the scope's
  own ground clip, which is the point.
* No return current crosses the split, because no net does.
* The converter's common-mode current has a 2.2 nF path home (720 ohm at
  100 kHz) that does not run through the analog ground plane.
* With nothing plugged in, the analog side sits within a millivolt of USB
  ground through R18 = 1 M rather than floating on accumulated charge.

**Converter noise, with numbers.**  The module's output ripple is of order
100 mVpp at about 100 kHz.  The linear regulators give perhaps 25 dB there and
the op-amps' own supply rejection another 30 dB, which puts roughly 200 uV of
switching residue at an output whose full scale is 2 V.  That is -80 dB, and
it is a hundred times *below* the MPY634's own output feedthrough of around
30 mV.  An RC between the converter and the regulators would buy another 36 dB
for two resistors; it is not worth the dropout margin it costs, because the
multiplier would still be the limit.  Physically the switcher, its input
capacitors and its 6 mm switching loop are all inside the island in the
bottom-left corner, behind a 1 mm gap, as far from the multipliers as the board
allows.

## What I would bet on if these came back not working

In order:

1. **Part rotation in assembly.**  The CPL says which way each part is turned,
   but the fab's library has its own idea of zero degrees, and for polarised
   parts -- D1, the two regulators, the USB-C receptacle, the DIP switch --
   a disagreement fits the part backwards.  This is the one failure I cannot
   check from here, and it is the most common first-article failure there is.
   `docs/MANUFACTURING.md` now carries a table of every polarised part and
   which way it faces, to check against the fab's own rendering before paying.
2. **The BNC footprint**, still drawn from SAMZO's drawing rather than from a
   connector in my hand.  It is through-hole: if it is wrong it will not fit,
   which is at least loud.  `lorenz-assembly-top.pdf` prints 1:1.
3. **A substituted MPY634.**  It is the one part on the board with no real
   second source, and an "equivalent" would not be.
4. Everything else -- values, nets, equations, ranges, decoupling -- is either
   proved from the netlist on every build or checked against a datasheet here.

# Prompt 4: a knob, a second board, and the lamp as it is actually built

## The lamp, settled

Option 038 of the hundred renderings, chosen by the person the board is for.
**MHPA3528CRGBCT**, common *anode*, held at **+3.20 V** by U2B from a 12k/33k
divider off +12 V; **z -> red through 470 ohm, x -> green through 3.9 k, -y ->
blue through 1.5 k**.  Every die now lights on the way *down*: it conducts when
its own signal falls a forward drop below +3.2 V.

| die | from | conducts below | peak | lit |
|---|---|---|---|---|
| red | z | +1.45 V | 2.5 mA, 38.1 mcd | 28 % of the time |
| green | x | +0.60 V | 0.7 mA, 36.3 mcd | 87 % |
| blue | -y | +0.60 V | 2.2 mA, 38.9 mcd | 84 % |

Three peaks within 8 % of one another, so the colour is a mix rather than one
die with hints of the others; the lamp is never fully dark; and U2B sources
3.7 mA at the peak.  Worst-case reverse on any junction is 2.8 V of the 5 V
rating, at the top of z with the knob fully clockwise.

The part matters: MHPC3528CRGBCT is the same dies in the same package with
pins 1 and 4 swapped, and fitting it here would put the red die's cathode on
the anode rail.  `check_pinout.py` transcribes the polarity drawing from the
data sheet (LPDS-0001481 rev 1 p.2) and compares it against the drawn symbol.

## The knob

R3 splits into 27 k fixed plus **RV1**, a Bourns 3386P 20 k single-turn cermet
trimmer, giving `r = 1M/(27k + RV1)` from **21.3 to 37.0**.

The two questions worth answering before fitting a potentiometer to a circuit
whose author dislikes them:

*Is it controllable?*  310 degrees of mechanical travel for 15.8 in r.  The
slope is steepest at the clockwise stop and even there it is 0.088 in r per
degree; at r = 28 it is 0.05.  Seventeen degrees of screw moves r by one.

*Is there anything at the end of it?*  At the counter-clockwise stop the
attractor is gone -- the trace spirals into a fixed point and the lamp stops
changing colour, which is the most visible thing on this board.  27 % of the
way round the wings become an attractor again; 33 % the fixed points lose
stability; 56 % is Lorenz's 28; and from there to the stop the red flashes
thin from two in five to one in seventeen as the orbit tightens.

*What happens when the wiper wears?*  Terminal 1 is tied to the wiper, so the
section in circuit is wiper-to-3 and the unused section is shorted out.  A
speck of grit that lifts the wiper leaves the whole 20 k track bridging
terminal 1 to terminal 3: r goes to its minimum and the attractor collapses,
which is a symptom you can see and recover from, rather than an open circuit
that deletes the `r x` term.  `check_circuit.py` asserts the tie.

The wiper carries no current that matters: it is in series with 27 k into a
virtual earth, so a wiper resistance that ages from 0.1 ohm to 1 kohm changes
r by 0.05 %.

## The synchronisation input

R19, 100 k from a pad marked SYNC IN into the dy/dt summing junction, with
R20 = 1 M holding the pad at ground when nothing is connected.

The junction inverts, so an injected voltage always arrives negative, and
diffusive coupling `g(u1 - u2)` is only available where the local term already
carries a plus.  In these three equations that is `+r x` in dy/dt and `+s y`
in dx/dt -- and no term at all in dz/dt.

Simulated, two boards at b = 1M/374k with 20 mV of initial mismatch, RK4 over
60 time units:

| channel | locks | threshold | what else must change |
|---|---|---|---|
| x into `+r x` | yes | g ~ 7 | nothing: turn the receiver's knob down by g |
| -y into `+s y` | yes | g ~ 4 | R1 -> 1M/(10-g), and g < 10 always |
| z | no | -- | impossible: the sign is wrong and there is no -z |

x gets the pad because the knob absorbs the offset the coupling adds to r.
At g = 1M/100k = 10 the error falls below a millivolt in 5 time units: 2.4 s
at `slow!`.  Drive at r = 32, receive at r = 22.

z is worth stating carefully.  It is *not* a conditional-Lyapunov obstruction:
sign-correct diffusive coupling `+g(z1 - z2)` synchronises in simulation at
quite modest g.  What blocks it here is that the inverting junction turns an
injected z1 into `-g z1`, which is anti-diffusive -- the error grows with g --
and producing `+g z1` would need a -z output this circuit does not have.

## Pin 1, and the rotation problem

Every part that can be fitted turned -- U1 through U7, D1, SW1, RV1 -- carries
a filled triangle on the front silkscreen, outside its outline, pointing at
pin 1.  `add_pin1_marks()` reads the real pad position and the real courtyard
from the placed footprint and picks the edge pad 1 is nearest, so the mark
cannot disagree with the footprint; a mark with nowhere to go is a build
failure, not a silent omission.

## The USB-C setback, which was wrong

The HRO receptacle's mating face is 3.65 mm in front of its footprint origin.
The origin was 6 mm from the board edge, so the opening sat 2.35 mm inside the
laminate -- far enough that a cable with a large moulded body would foul the
edge before the plug seated.  J1 moved to y = 95.85: the body is half a
millimetre inside the edge, and its printed outline lands exactly on the
0.15 mm silk-to-edge rule, which is as far out as the silkscreen allows
without being clipped.

## Rotations, corrected

For a KiCad chip footprint **rot = 0 is horizontal** and rot = 90 is vertical;
this project had it backwards, and had described vertical parts as horizontal.
Series resistors are now rot = 0 and lie along the signal flow -- R1-R7 into
the summing junctions, R8/R9/R10 into the BNCs, R13-R15 into the lamp, F1 in
the +5 V line -- and shunts are rot = 90 and stand across it.  Every one now
matches the way it is drawn on the schematic.

# Prompt 5: the sync input grows up, and two marks become one

## Pin-1 marks, trimmed back

Prompt 4 put a filled triangle beside pin 1 of every part that can be fitted
turned.  Four of them already had a perfectly good mark of their own -- KiCad
prints a pin-1 dot on its SOIC footprints and a notched corner on the SOT-89s
-- so the board ended up carrying two marks per part, which is two marks to
reconcile instead of one to read.  `PIN1_MARKS` is now **D1, SW1, RV1 and
RV2**: the lamp and the DIP switch carry only a 0.2 mm dot inside their own
courtyards, which is there for anyone reusing the footprint but is not legible
on a board, and the trimmers have a square pad 1 and a chamfered corner, which
are shape cues rather than marks.

## The DIP switch, and which side pin 1 is on

On the KingTek DSIC06LSGET drawing the switch positions 1..6 are printed along
one long side of the body and "ON" along the other, so **pin 1 is on the side
away from the ON legend** -- which is where the triangle points.  KiCad's own
generic DIP-switch footprints agree: pads 1..6 on one side, an `on` marker on
the far side.

The reassuring part is what happens if the assembler gets it wrong.  Each pole
connects pin k to pin 13-k, and a 180 degree rotation maps k to 13-k, so every
pole still pairs with itself: a switch fitted backwards is **electrically
identical**.  What it costs is the labelling -- slider 1 ends up where slider 6
should be, so the two banks swap and the printed table reads backwards.  The
board now prints "ON faces the table above" under the switch so that is
visible at a glance.

## The switch, read as a binary number

Poles 1-3 now carry the 470 nF and poles 4-6 the 100 nF, so the six sliders
read left to right as a two-digit binary number:

| setting | poles 1-3 | poles 4-6 | C | tau |
|---|---|---|---|---|
| fast! | off | off | 2.2 nF | 2.2 ms |
| nice! | off | ON  | 102 nF | 102 ms |
| slow! | ON  | off | 472 nF | 472 ms |
| slower! | ON  | ON  | 572 nF | 572 ms |

The capacitors swapped positions on the board to match, so each one still sits
over the pole it belongs to and no two branches cross.  "glacial!" was too
dramatic for a fifth again slower than "slow!"; it is "slower!" now.

## SYNC IN X

A fourth BNC on the left edge, in line with the x output on the right, because
another board's x output is what goes in it.  Then a weight knob, then the
100k into the dy/dt summing junction.

**The knob is a divider, not a rheostat.**  A rheostat in series with R19
would have made the weight go as 1/R: with a 20k pot and 100k fixed, g would
run 10 down to 1.7 with everything interesting -- the locking threshold, which sits
between g = 7 and g = 7.5 -- inside the first tenth of the rotation.  As a divider across the
incoming signal the weight is *linear*:

    g  =  1M / 100k  x  (fraction turned)  =  0 .. 10

within 5 %, because the wiper's own source impedance peaks at a quarter of the
20k track against R19's 100k.  The threshold lands at about 70 % of rotation, so the
bottom seven tenths is "influence, but never enough" and the top three tenths
locks, in about 2 seconds at `slow!`.

It also reaches **zero**, which is what the prompt asked for by a different
route: the user asked for a fixed resistor in series so the weight could not
go all the way to zero, but the danger a rheostat has at zero is infinite
gain, not zero gain.  A divider at zero simply grounds R19's input, which is
exactly what an unplugged cable does.

The failure mode is safe for the same reason.  RV1's wiper is tied to
terminal 1 because an open wiper there would delete the r x term; RV2's wiper
has R20 = 1M to ground, so an open wiper there leaves the sync branch at 0 V.
Different stakes, different wiring.

## Drawing the sum so it reads as a sum

The old drawing brought the sync branch into the summing rail alongside the
-y and x z branches, which said "here is a fourth term" when what is meant is
"here is a perturbation on the x term".  Row 2's branches now run -y, x z, x
down the sheet, and **the x branch and the sync branch join on their own short
rail at x = 157.48 before that rail continues to the summing junction**.  The
board says the same thing: R19 is the next resistor down the column from R3,
with "SYNC IN X adds here" printed beside it, and the signal chain runs jack,
knob, resistor, straight across into the column.

## The left edge is the input edge

Making room meant moving the two multipliers 9 mm right and putting the jack,
both trimmers and the sync resistors down the edge they vacated.  The back
side had to move with it: the three drilled parts down that edge punch through
the equations block, so the equations dropped from 2.4 mm to 2.0 mm and the
constants split over two lines, and neither now reaches past x = 14.

# Prompt 13: rev B, and proving nothing else moved

Rev B changes the lamp to candidate 1 of `docs/lamp2` and trims J1's
silkscreen clear of the edge.  Everything else was meant to stay exactly as
rev A, which came back from JLCPCB working, so the review was mostly a
comparison against rev A's own files.

## What was compared, and what came out

* **Netlist.**  With the lamp's parts taken out, all 204 remaining pins
  connect exactly as in rev A.  The lamp now attaches to +12 V, -12 V, x, -y
  and z through R13-R15 and R22-R24, and to nothing else.
* **Parts.**  Three new resistors (R22, R23, R24), new values on R13-R16 and
  a new name on TP6, all JLCPCB Basic parts; nothing removed.
* **Placement.**  Only the lamp's resistors and C18 moved, C18 by 2 mm to
  clear the lamp's bottom row.  D1's footprint, position and rotation are
  rev A's, which its boards proved JLCPCB fits correctly.
* **Routing.**  The router re-routed the nets the lamp touches.  Of the
  rest, every net is identical to rev A except /SJ_Y, which takes a route
  1.2 mm lower over its last 20 mm into U1 pin 6: same layer, same
  neighbourhood, 0.2 mm longer.
* **Fab files.**  Board outline and non-plated holes byte-identical;
  every plated component hole the same; 8 fewer vias.  BOM and CPL differ
  only in the lamp's lines and C18.
* **The lamp itself.**  `check_circuit.py` now reads the lamp back out of the
  netlist, checks it is the chosen wiring resistor by resistor, and
  simulates it with the corrected LED model: 0.82 at `slow!`, where rev A
  scores 0.33.  Die peaks at most 1.8 mA, no die reverse-biased by more
  than 0.2 V, U2B sourcing at most 1.9 mA.

## Two old faults found on the way

* **The schematic checker could not see a clash on a rotated part.**  KiCad
  draws a field on a 90-degree symbol with its justification reversed.  The
  checker read the justification literally, so the first rev B drawing
  printed six resistors' names on top of their values and passed.  It now
  models the reversal; rev A's sheet still passes under it.
* **Rev A's assembler notes gave D1's pin order the wrong way round:**
  "anticlockwise" where the pads run clockwise.  JLCPCB placed rev A from the
  pin-1 triangle, so no harm came of it, but rev B's notes are corrected.

And one fault of Response 12's: its LED model made the build's colour
self-test import scipy, which the README does not ask anyone to install.
The eye filter is now plain numpy, checked against the recursion it
implements, and the build needs only what it needed before.

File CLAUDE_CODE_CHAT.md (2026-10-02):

# Chat with Claude Opus 5 Max about the AI UNLEASHES CHAOS Circuit and PCB

Lorenz Attractor Circuit by Paul Horowitz in KiCAD

Every prompt is verbatim; every response is what Claude wrote at the time.
Each response opens with the board and schematic **as they stood when that
response was written**, pulled back out of the git history -- because what
the next prompt asks for only makes sense against what was on the screen
when it was typed.  The board as it stands now is in [README.md](README.md).

## Prompt 1

In graduate school I worked with Paul Horowitz, of [Art of Electronics](https://artofelectronics.net/) fame. I even contributed a few bits and pieces to the 3rd edition. (I am thanked in the footnotes, one of which simply says, "Jason, again.) I want you to build a nice little present for Paul, which could also live on as an open source project and a kit that people could build.

Make a KiCAD 10 project, schematic, and PCB to implement [Paul's Lorenz Attractor Circuit](https://seti.harvard.edu/unusual_stuff/misc/lorenz.htm).
* It should take power in through a simple USB-C connector. This means that you'll either need to make a negative voltage or change the circuit to power the op amps from only +5V. 
* You may need to make other changes to the circuit. Do it in a way that maintains is simple elegance and educational value.
* Its outputs ()"x", "-y", and "z") should each come out on a BNC connector.
* It would be good to be able to switch the capacitor "C" to the three different values shown: "slow!", "nice!", and "fast!". However, if this explodes the complexity, just pick "nice!".
* Feel free to use modern components if necessary, but try to keep packages as large as is reasonable. SMT is ok, but I want people to be able to hand solder and rework as much as possible (0805 R's and C's, for example).  I want you to take it all the way to gerbers, a BOM, and a CPL file that I can simply upload to a place like JLCPCB, NextPCB Rev 0, or CircuitHub.
* Select components that these places have plenty of in stock, such that that I can order in only one step. I do not want to consign any parts. I do not want to wait for out of stock items.
* Make 2-layer and also a 4-layer version. Do all of the placement and routing yourself.
* You should have a shell script or python file that just "makes" everything on the command line: the schematic, PCB, manufacturing files, and a document with a cost estimate and other manufacturing instructions for me. Your scripts should run as many checks as necessary to ensure that I can just upload the files, "click go", and have working boards show up at Paul's house.
* Make the design rule checks at least as strict as the cheap option's design rules at JLCPCB, NextPCB Rev 0, and CircuitHub.
* Lay out the schematic and the PCB as Paul does in his hand-drawn schematic. The schematic should be a single page. The PCB should fit within the fab and assembly house's discounted small size, but otherwise should be legible and logically arranged.
* The schematic should be in the beautiful "Art of Electronics style" --- the circuit is drawn, and things are labeled in such a way as to immediately answer typical questions that might arise in a reader's mind:
 - I don't want to see labels that disappear and magically reappear elsewhere (except maybe power and ground).
 - If a note belongs with a node or IC, write it right next to the node, not somewhere off to the side.
 - No labels should overlap components or other labels. You can spread things out a bit on the page to allow this to happen, but keep everything within the borders of the page. Really check that this is the case.
* The PCB's silkscreen should make it clear what the inputs and outputs are. 
 - Nothing on the silkscreen should overlap other silkscreen or components. Really check this. Make it beautiful.
 - The silkscreen should have the following on it: "AI Unleashes Chaos", "Circuit by Paul Horowitz", "PCB by Jason Gallicchio and Claude", today's date, and "rev A" in case we need to re-spin.
 - Component values and IC names should also be on the silkscreen (in addition to the reference designators) for educational purposes.
 - Write the equations and "suggested parameters" on the silkscreen. Check that the circuit actually implements them.
 - Include a little drawing of the "owl's face" on the PCB like Paul does in his schematic.
* Do a self-critical design review of the circuit, the way the schematic is drawn, the way the PCB is laid out, and the component and manufacturing selections. Make any changes. Iterate until satisfied.
* I will open the schematic and PCB in KiCAD and give you feedback after you've worked on it for many hours.

Record your response below in this document. Do this regularly, and check things into git as you go.

## Response 1

*The board and schematic as they stood when this was written — four layers, three rail lamps, and the owl on the back.  The schematic links to its PDF.*

| front | | back |
|---|---|---|
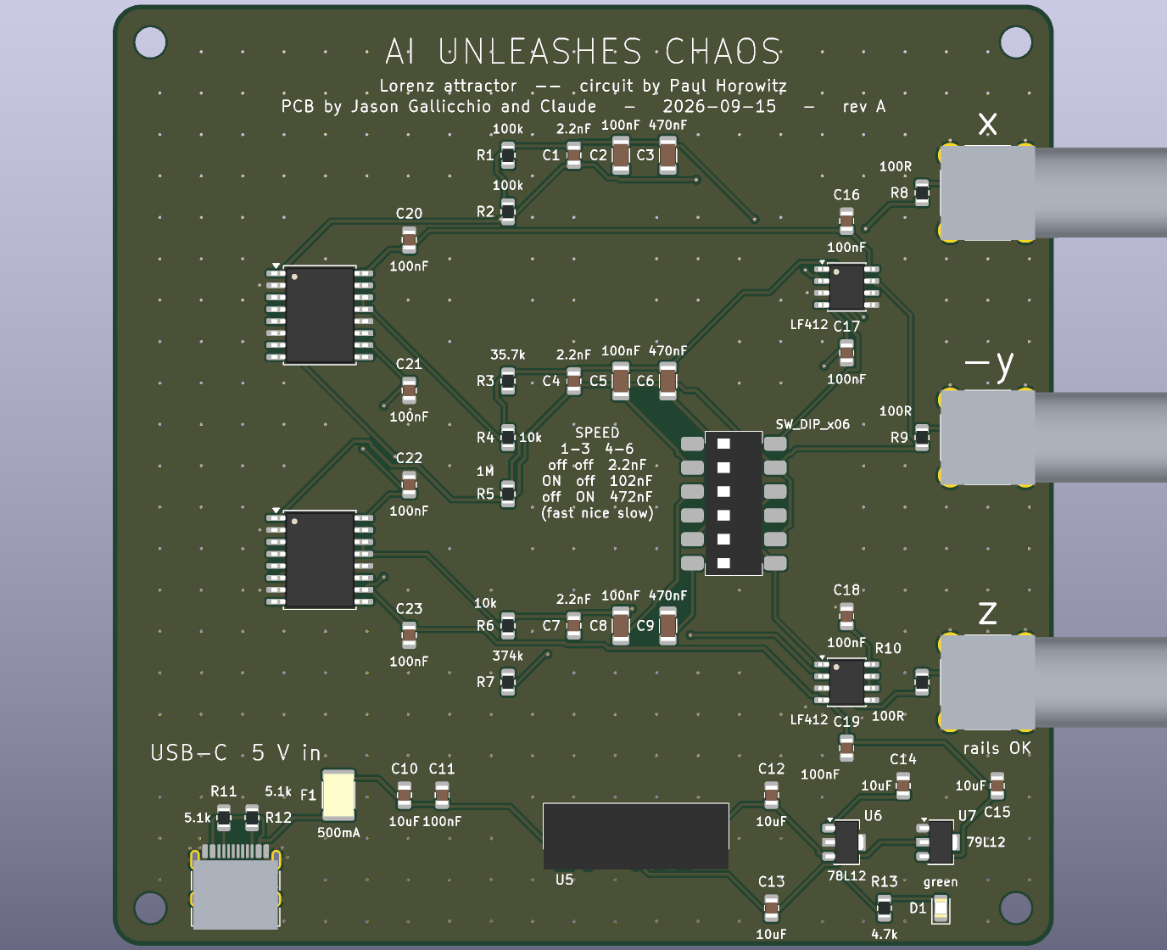
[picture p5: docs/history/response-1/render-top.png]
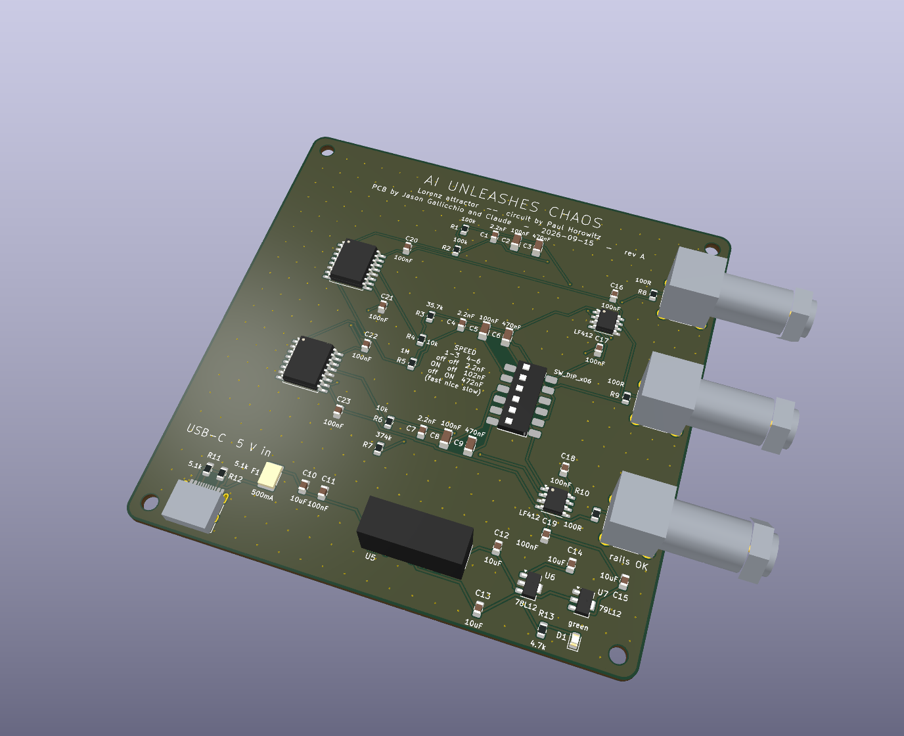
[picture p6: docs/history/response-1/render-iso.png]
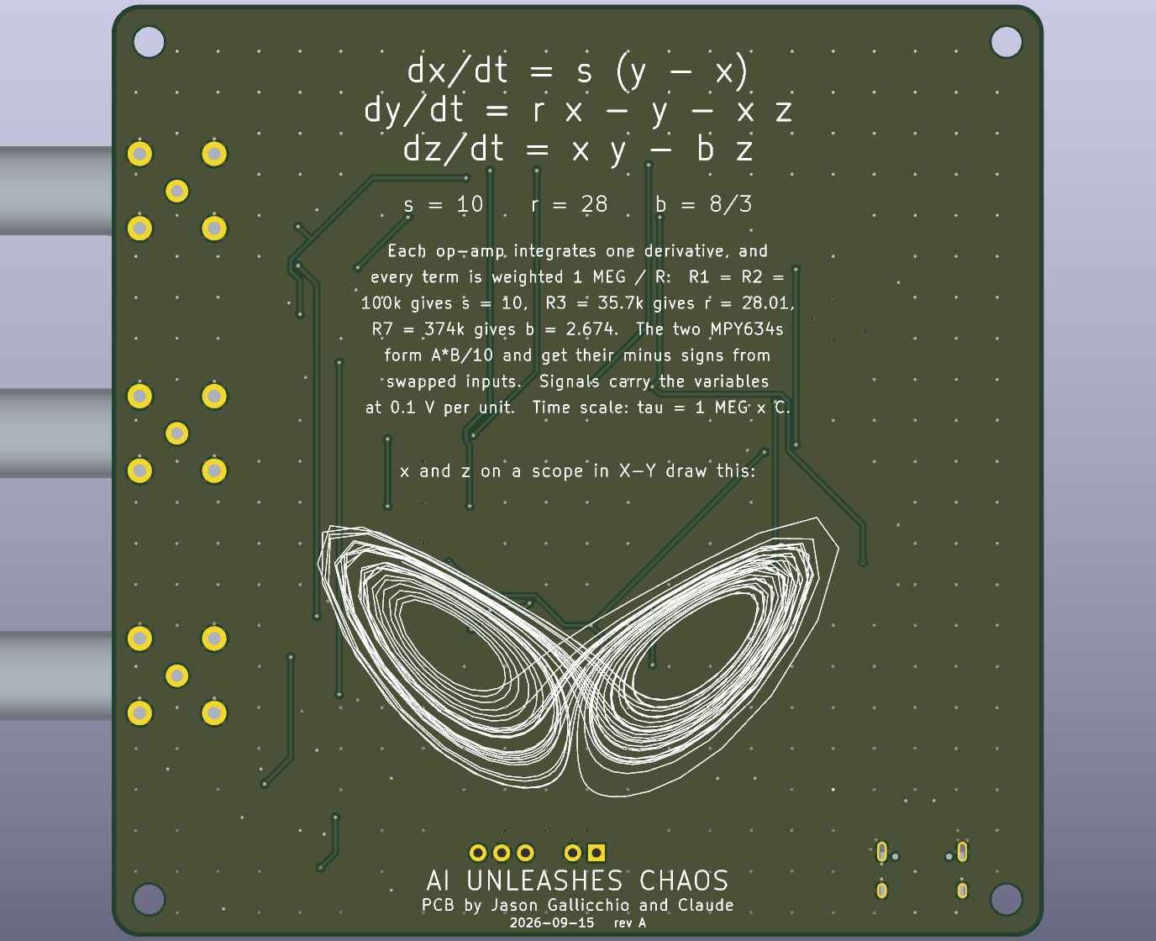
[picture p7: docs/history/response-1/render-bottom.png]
|  |  |  |

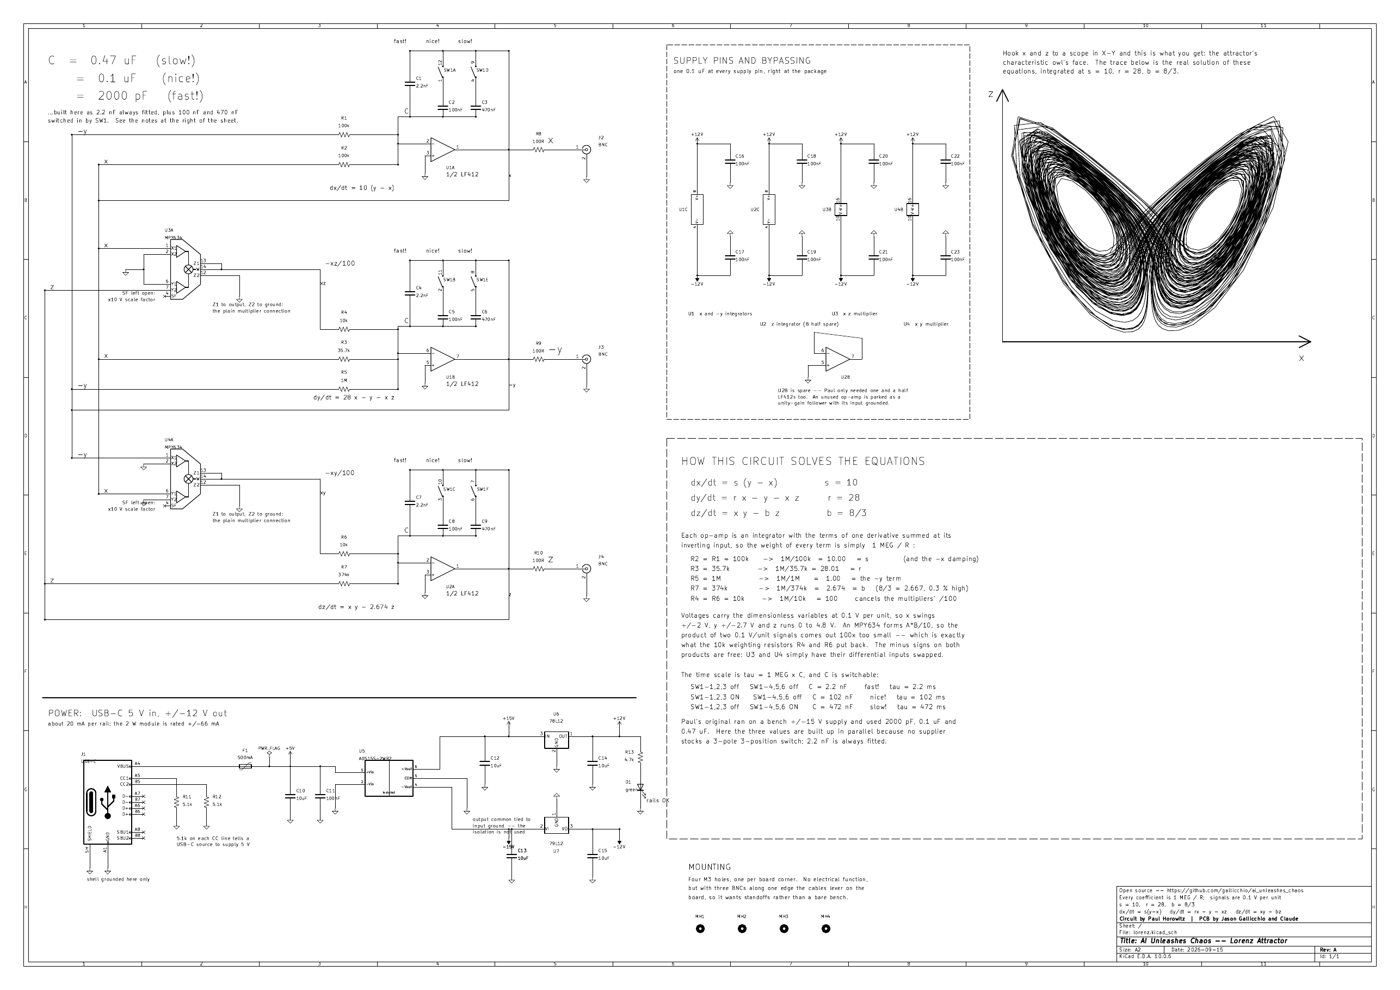
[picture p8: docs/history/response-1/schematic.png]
schematic


*(This section is the reply as it was written. Response 2 below changed some of
it — most visibly, there is no longer a four-layer board.)*

Built. `./make.py` regenerates everything from scratch in about 40 seconds and
refuses to finish unless every check passes. Current state:

| check | result |
|---|---|
| ERC | 0 violations |
| DRC + schematic parity, 2-layer | 0 violations |
| DRC + schematic parity, 4-layer | 0 violations |
| circuit checker (reads the netlist, not the drawing) | 75 checks pass |
| schematic layout (205 text items) | no overlaps, nothing outside the frame |
| fab package | all checks pass |

Open `hardware/lorenz.kicad_pro`. The 4-layer variant is `lorenz-4layer.kicad_pro`
and shares the schematic.

### What it is

Your circuit, unchanged: three lossy integrators built from **LF412s** and two
**MPY634s**, with the resistor values exactly as you drew them — 100k, 100k,
35.7k, 10k, 1M, 10k, 374k. The sign inversions still come free from swapping the
multipliers' differential inputs. `scripts/check_circuit.py` walks the exported
netlist, works out what each integrator actually computes from the resistors
really attached to it, and recovers **s = 10, r = 28.01, b = 2.6738** — 8/3 plus
0.27%, which is the 374k. It also checks the virtual earths, the multiplier
hookup, the matched capacitors, the outputs and every supply pin.

Both of your parts are still stocked at JLCPCB: LF412CDR (1037) and MPY634KU
(874). Being able to keep them is why the schematic looks like yours.

### The three things that had to change

**USB-C power.** 5 V in → `A0515S-2WR2` isolated module → ±15 V → 78L12/79L12 →
**±12 V**. The module alone is unregulated and climbs toward ±17 V at this
board's light load, which is too close to the MPY634's ±18 V absolute maximum
to trust across vendors; the regulators pin the rails and strip the converter's
100 kHz ripple. MPY634 is specified from ±8 V, and the largest signal on the
board is z at 4.8 V, so ±12 V is not tight.

**Speed switching.** No supplier stocks a 3-pole 3-position switch, and the three
integrators have to change together. So 2.2 nF C0G is always fitted and a 6-way
DIP switch adds 100 nF (poles 1–3) or 470 nF (poles 4–6) to all three at once:
2.2 nF fast, 102 nF nice, 472 nF slow. The table is on the silkscreen next to
the switch. This is the part of the design I like least — see the review.

**100 Ω in series with each BNC.** A JFET-input op-amp driving a metre of RG-58
will ring. They sit outside the summing network, so the equations are untouched,
and the error into a 1 MΩ scope input is 0.01%.

### What to look at when you open it

- **Schematic** (A2, one page): three integrator rows the way you stack them,
  multipliers on the left, your `C = 0.47 µF (slow!)…` note in the top-left
  corner, and the owl's face top-right — that trace is the real solution,
  integrated by `scripts/lorenz_curve.py`, not clip art. Supply pins and
  bypassing are grouped in their own dashed box, which is the job your "IC
  Pinouts (DIP)" box was doing.
- **PCB**: 100 × 100 mm, inside the discounted size everywhere. Front silkscreen
  is legends, port labels and the speed table; **turn it over** — the back
  carries the equations, your suggested parameters and a large owl.
- **`docs/DESIGN_REVIEW.md`** — what I think is wrong with it, including four
  router bugs the checks caught that each produce a board that *looks* right.
- **`docs/MANUFACTURING.md`** — what to upload, what to select, what it costs.

### Cost

Parts are **$71.69/board**, of which $61.17 is the pair of MPY634s. Two boards
fully assembled, two layers, including through-hole assembly and DHL: about
**$231**, so roughly $115 each. Five is about $74 each. Four layers adds $23 to
the order. `docs/MANUFACTURING.md` breaks it down and is regenerated from the
same parts table the BOM comes from, so it cannot drift.
*(Response 2 added twenty more components — three rail lamps, the chaos lamp
and its drive, the barrier parts — for **$0.17** a board. The current number is
in `docs/MANUFACTURING.md`.)*

### Biggest risk

The BNC footprint is drawn from SAMZO's drawing, not from a connector in my
hand. `out/lorenz/lorenz-assembly-top.pdf` prints 1:1 — please check it against
a real BNC-KYWE before ordering. Everything else on the board is a stock KiCad
footprint or dimensioned from a datasheet I read.

### Pictures

`./make.py` now writes these into `docs/images/` every build, so they cannot
drift from the design.

The back carries the equations, your suggested parameters and the attractor
itself — the trace is the real solution, integrated by `scripts/lorenz_curve.py`:

(NOTE that these links point to the current revision, not what resulted 
only from Prompt 1, which is why I included those as images at the start of each response.)

* [The schematic](docs/images/schematic.png)
* [front silkscreen](docs/images/lorenz-silk-top.png)
* [back silkscreen](docs/images/lorenz-silk-bottom.png)
* [front copper](docs/images/lorenz-top.png)
* [back copper](docs/images/lorenz-bottom.png)

*(Response 1 also built a four-layer board and pictured its two inner planes.
Response 2 dropped it — see below for the measurement that decided it.)*

Every one of these is byte-reproducible except `lorenz-render-iso.png`: KiCad's
renderer jitters a rotated camera, so that one image differs slightly from build
to build even though the board has not changed. Everything a fab reads —
gerbers, drill files, BOM, CPL — is reproducible, with timestamps pinned to the
board date.

Each board also gets a `.step` model (not tracked; it churns) and a
`-stats.txt` in its `out/` folder,
and PDFs of the schematic and both assembly drawings — the top one prints 1:1
for checking footprints against real parts.

### Answering `next_prompt.md`

**Do the schematics differ between 2-layer and 4-layer? Why are there two?**

They do not differ — `lorenz-4layer.kicad_sch` is a byte-for-byte copy that
`make.py` writes from `lorenz.kicad_sch` on every build, so the two cannot
drift apart. It is purely a KiCad requirement: a project is one `.kicad_pro`,
one `.kicad_sch` and one `.kicad_pcb` sharing a basename, and
`kicad-cli pcb drc --schematic-parity` finds the schematic by that basename. No
basename, no parity check — and the parity check is what guarantees the board
you send to the fab really is the circuit that was verified. I kept the copy
tracked rather than generated-only so that either project opens straight from a
clone without running anything first.

The only real differences between the two boards are the stackup and what is
poured on it: two layers puts ground on both sides, four puts signals outside,
a solid ground plane on In1 and a +12 V plane on In2. Same placement, same
schematic, same BOM, same pick-and-place.

## Prompt 2

Build process:

* On a different computer (my laptop), when I run make.py after setting `KICAD_APPRUN`, I get the following, which may indicate that not everything in this git repo is self contained. This should be reproducible by someone who just clones it off of github and types `./make.py`.
```
$ ./make.py 
KiCad 10.0.6

=== self-tests ======================================================
Cannot locate KiCad shared data (symbols/footprints).

BUILD FAILED: selftest_rotation.py failed
```
* Add a `make.py --clean` to remove everything that is generated by make.py. In addition to being good practice, this is useful so that people can know what is generated and what needs to live in git.

Schematics:

* I made a datasheets directory and download some datasheets there. You should make sure they are all downloaded: all parts and connectors and anything else that would be useful. I can get you any that you need. Do not check this into git for copyright reasons.
* Do the schematics differ at all between 2-layer and 4? If not, why are there two different schematics? Is this just a KiCAD requirement? When I have both the schematic and PCB open, I can't seem to click on one to highlight that spot in the other. Do they need to get linked in some way for that to work?
* Two web pages URLs along with QR codes for them should go on the back of the PCB:
 - <https://seti.harvard.edu/unusual_stuff/misc/lorenz.htm>
 - <https://github.com/gallicchio/ai_unleashes_chaos>
* The little table that explains the switch settings could be more clear
* You might have misinterpreted my request which came up in your "One label per signal net" section of your DESIGN_REVIEW.md document. I meant one human-readable comment-type label. The internal KiCAD labels can be whatever they need to be for the best error checking.
* There should be places to attach the ground clips of oscilloscope leads and marked (labeled) test points (places to probe) for all of the DC voltages and the other interesting places to probe in the circuit that you marked in the schematic, like "dx/dt = 10 (y - x)", "-xz/100", and "dy/dt = 28 x - y - x z".
* There should be at least 3 "rails OK" LEDs, one for USB and one for each of the regulated rails. They can be different colors so that one can know at a glance which one is not working. Or they could be all dim white LEDs if you do the following:
* Does it make sense to put LEDs on the x, -y, and z outputs? Or an RGB LED, where each color is driven by one of the outputs to make a chaotic color in "slow" mode? The advantage is that there would be something to look at even if you didn't plug in the BNCs to a scope. A resistor and LED would have a non-linear response, but I'm not sure if anything would be gained by making a proper proportional current drive, and I'm not sure how I'd deal with negative-going signals.
* I'm not familiar with the A0515S-2WR2. If it's truly isolated, as the schematic symbol suggests, would it be a good idea or a bad idea to keep the USB ground separate from what eventually becomes the oscilloscope ground to avoid ground loops? Or would that introduce more problems than it solves? You do acknowledge that "the isolation is not used," whose text you should keep on the schematic if you decide to continue not isolating it.

PCB:

* Does the 4-layer  board buy you anything useful here? Maybe with my pedagogical silkscreen requests, the board size is already going to be large and identical in size to the 2 layer. Is the 4-layer worth it? If it's not worth it, just drop it from the project.
* Should "rails OK" be right next to the LED? Does it really only light if both rails are, in fact, ok?
* The 3D model is missing some parts, especially the DIP switch and the A0515S device that makes +-15 V.
* The PCB should also include the text "Circuit by Paul Horowitz" and the web page, just like the schematic does, not only "PCB by Jason Gallicchio and Claude". Please, that's what he'll see first!
* The table that explains the switch settings could be more clear. At a minimum, the text should be rotated so that the words "off" and "ON" in each column should actually be under the 3 switches that they refer to. Make a silkscreen bar that is drawn coming perpendicular to the DIP switches, in between the columns. Doing this carefully should also solve my second problem with this, table, which is that the label "1-3" is above both columns of the off's and ON's, whereas "4-6" is above the capacitor values... and "fast", "nice", "slow" should be associated with rows of the table.
* The text "MountingHole" and its reference designator does not need to be on the silkscreen.
* The PCB layers in docs/images/ are mostly whitespace. Why aren't these images only as big as the PCB outline?

Misc:

* As part of the build process, generate PDFs and PNGs and 3D renders of the schematic and PCBs and include them here, as you've started to do.
* Continue calling this "rev A" until I actually pay to fabricate a board.
* As you are working, I might be updating next_prompt.md, but don't look at it until I put its content here and tell you to look at it.

## Response 2

*The board and schematic as they stood when this was written — two layers, the isolated ground split, the chaos lamp and the QR codes.  The schematic links to its PDF.*

| front | | back |
|---|---|---|
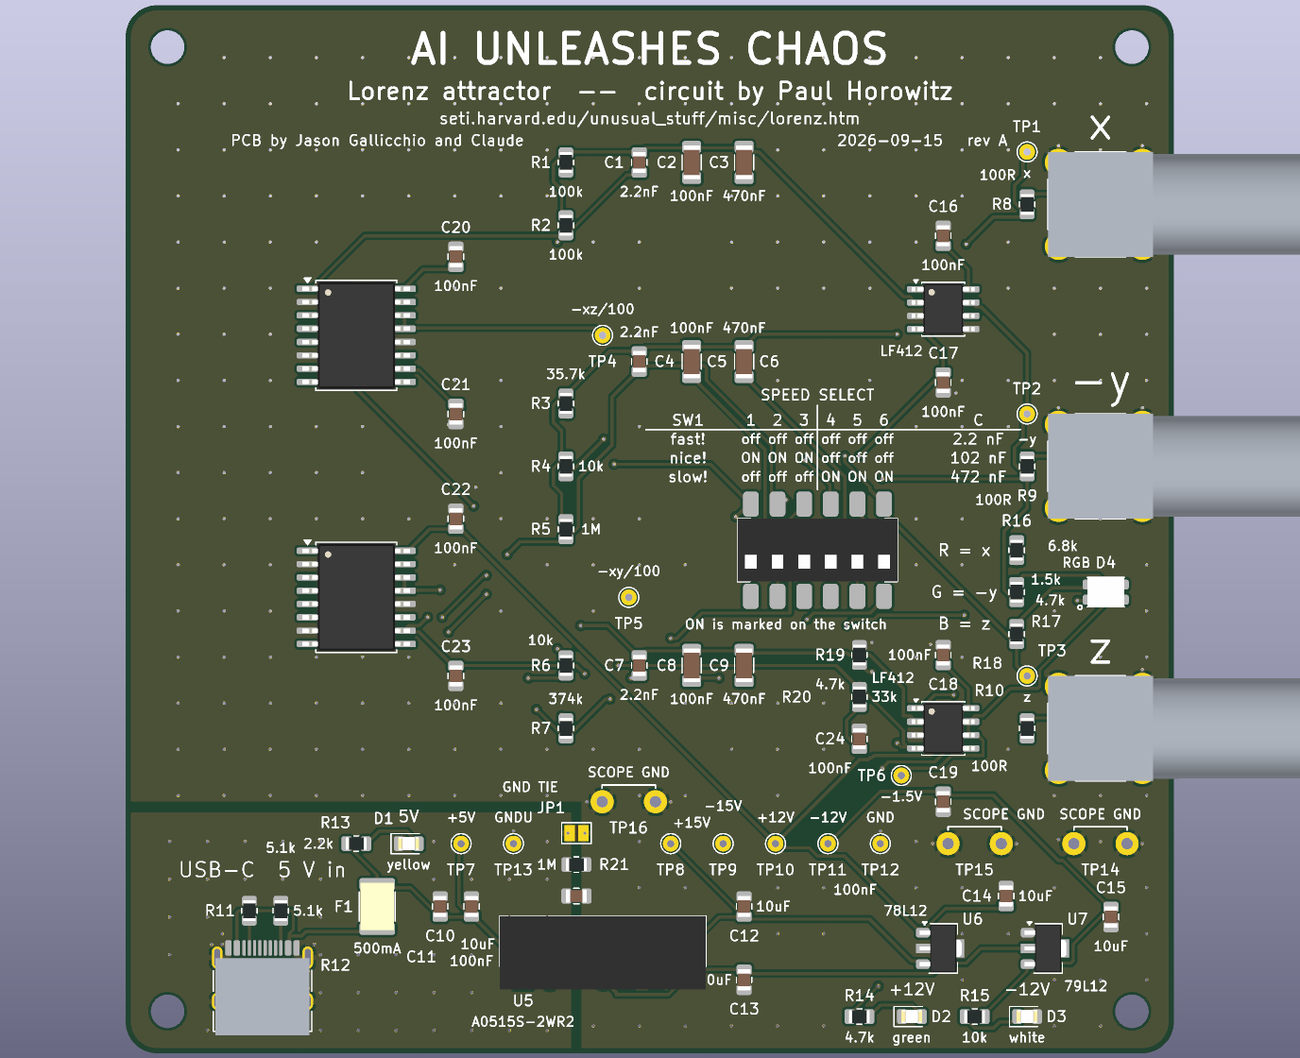
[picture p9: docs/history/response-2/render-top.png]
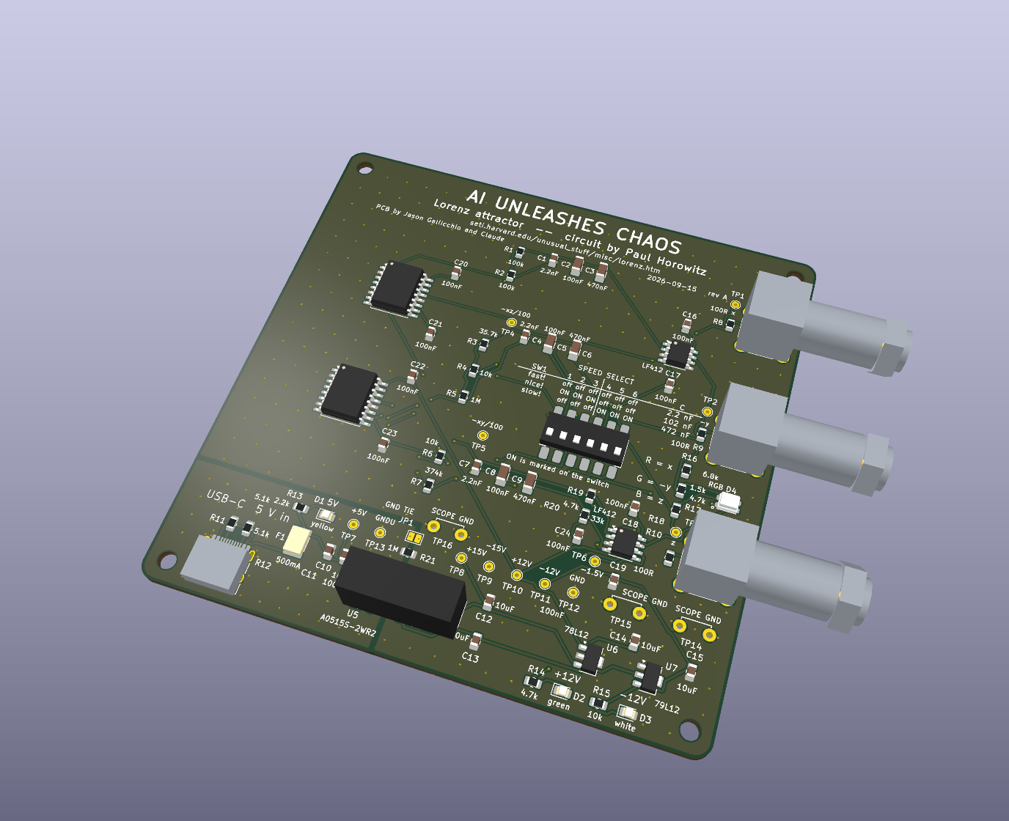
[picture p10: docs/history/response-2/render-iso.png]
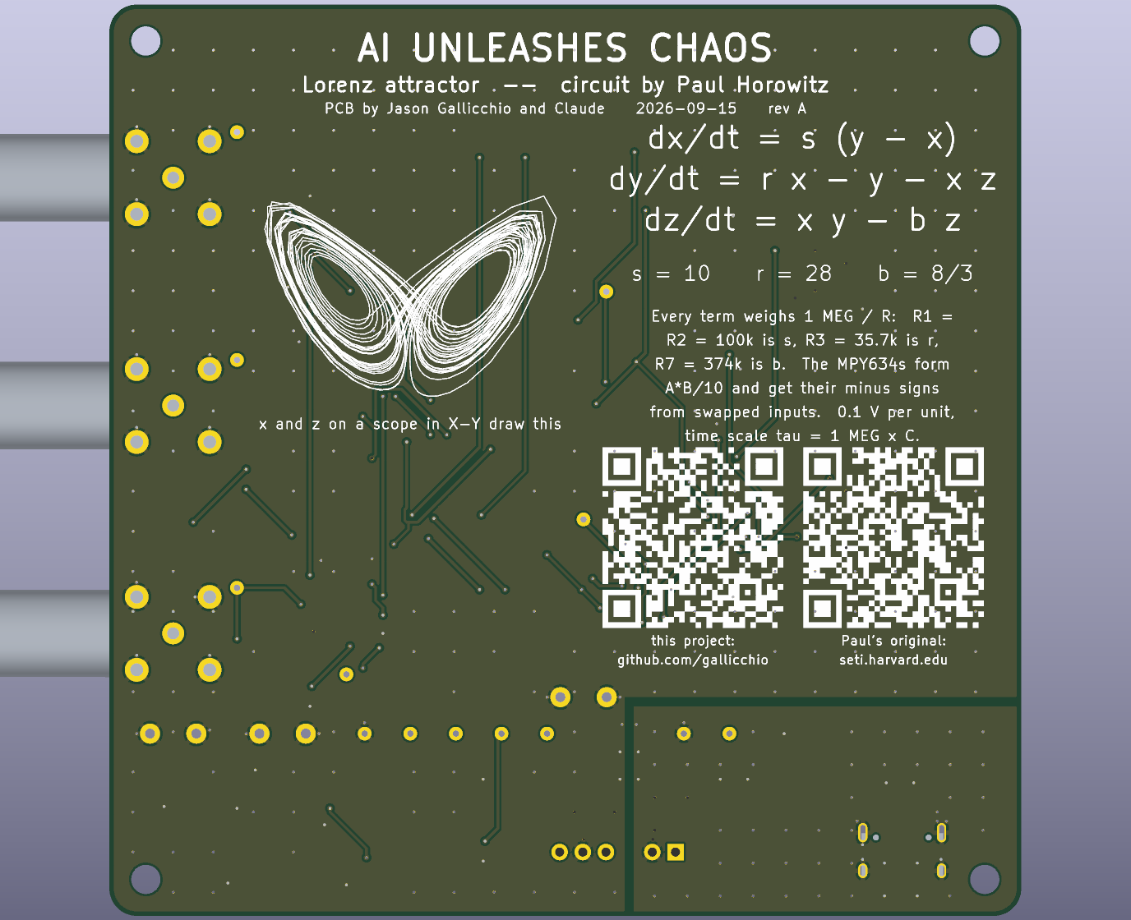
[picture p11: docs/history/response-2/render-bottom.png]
|  |  |  |

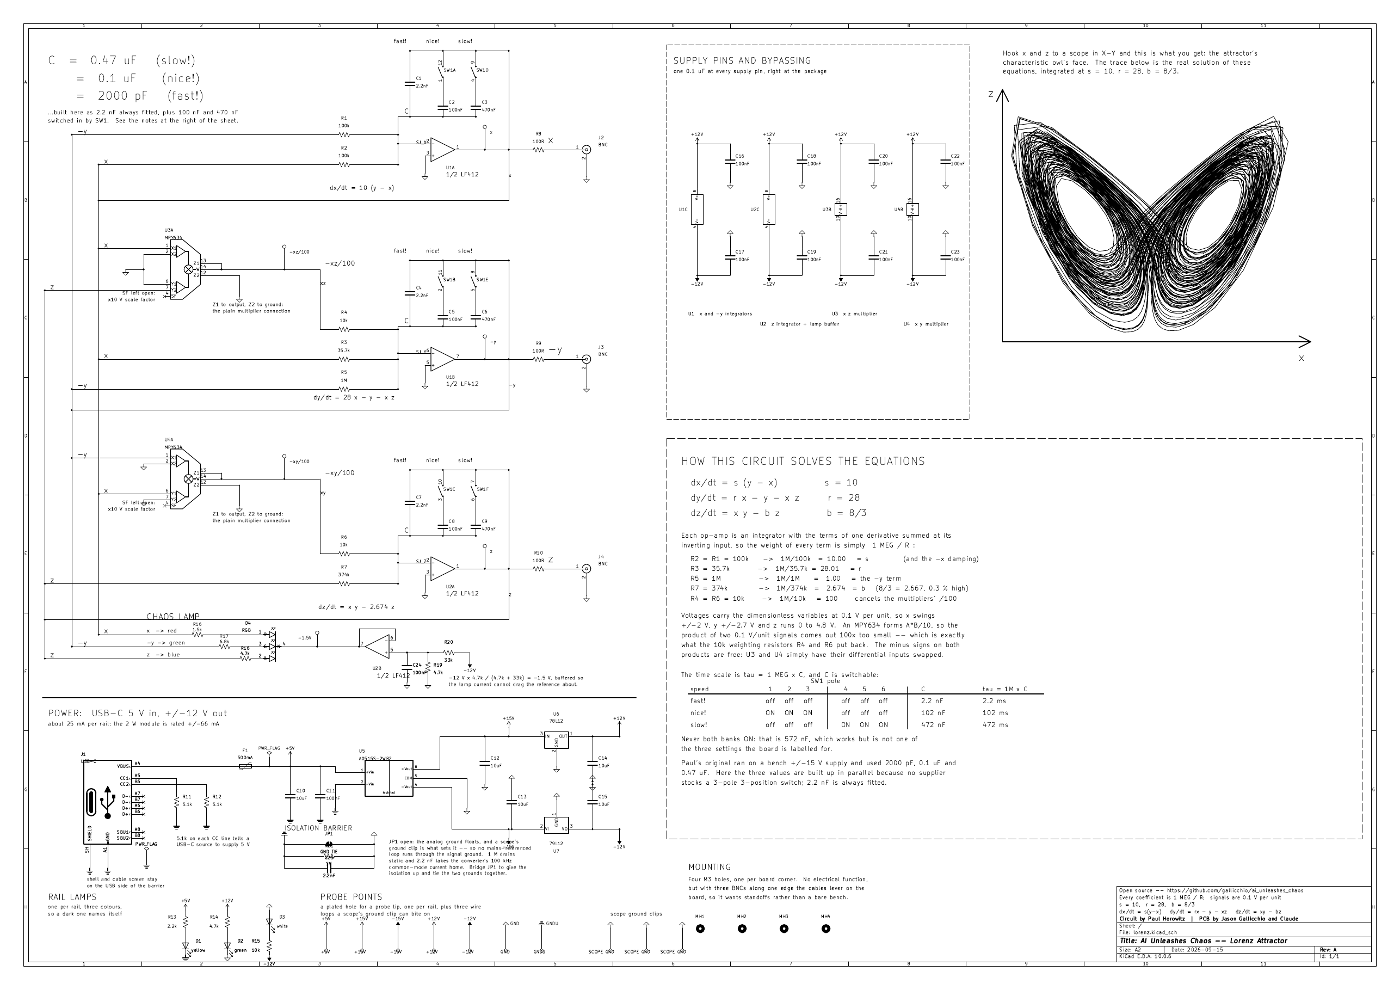
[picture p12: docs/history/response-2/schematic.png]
schematic


*(As written. Response 3 changed two things here: the three rail lamps are
gone, because the chaos lamp cannot light unless every rail is up, and the
lamp is now fed from each integrator's output node rather than from the return
lanes.)*

Everything below is built by `./make.py`, which now ends with **BUILD OK** only
if ERC, DRC with schematic parity, 116 circuit checks, the schematic layout
check, the fab-package checks and — new — a QR decoder all pass.

### The isolation: yes, use it

The A0515S-2WR2 really is isolated — 1 kV, no DC path — and the board was
throwing that away. It doesn't now. There are two grounds:

* **GND**, everything downstream of the converter: both op-amps, both
  multipliers, the BNC shells, the chaos lamp, every probe pad but one.
* **GNDU**, everything upstream: the USB-C connector *and its shell*, the CC
  pull-downs, the input bulk capacitors, the +5 V lamp.

They are two separate copper pours with a 1 mm gap, and U5 sits across the gap
with its own 5.08 mm barrier over it. You can see the island in the
[front copper](docs/images/lorenz-top.png), bottom left.

This is worth doing on *this* board specifically. Its whole purpose is to be
watched on a scope, and a scope ground clip is bonded to mains earth. Tie the
grounds and the loop runs scope earth → BNC shell → board ground → USB cable →
laptop → earth; whatever that loop carries lands on signals whose full scale is
2 V. Isolated, the scope clip is the only thing deciding where analog ground
sits — which is exactly what you want when you are looking at 100 mV of chaos.

It is not left completely adrift, because that would trade one problem for
another. Across the barrier: **R21 = 1 M** drains static, **C25 = 2.2 nF**
gives the converter's ~100 kHz common-mode current a way home (720 Ω there,
1.2 GΩ at 60 Hz), and **JP1** is an open solder jumper marked `GND TIE` —
bridge it and the two grounds are hard-tied again. Both R and C values were
already in the BOM, so the whole thing costs two 0805s and no new order codes.

The "the isolation is not used" note is gone from the sheet, replaced by a
labelled `ISOLATION BARRIER` block that says what JP1 does.

### The chaos lamp, and the negative-going problem

Yes to the RGB LED, and the answer to *"I'm not sure how I'd deal with
negative-going signals"* turns out to be the nicest part of the design: put
the **common cathode below ground** and let each colour threshold itself.

U2B — the half of U2 Paul never needed, previously parked as a grounded
follower — buffers −1.50 V from a 4.7k/33k divider and holds the lamp's
cathode there. Then:

| colour | driven by | lights when | peak current |
|---|---|---|---|
| red | x through 1.5k | x > +0.25 V — the **+x wing** | 1.16 mA |
| green | −y through 6.8k | y < −1.10 V — the **−x wing** | 0.23 mA |
| blue | z through 4.7k | z > +1.10 V, brightness tracking z | 0.79 mA |

So red and green **alternate as the trajectory switches wings** — which is the
chaos itself, visible without a scope — while blue brightens with z and drops
out at the bottom of each excursion. In `slow!` (τ = 472 ms) that happens at a
few hertz; in `nice!` it is a flicker; in `fast!` it averages into a colour.

On the nonlinearity you raised: a resistor and an LED is a soft threshold, and
here that is a *feature*, not a defect. A proportional current drive would give
a smooth fade and lose the wing-switching, which is the thing worth seeing.
What did need care was perceived brightness — green is about five times
brighter per milliamp than red and sits where the eye is most sensitive — so
the three resistors are sized from the datasheet's luminous intensities rather
than for equal current.

The lamp taps the op-amp outputs *before* the 100 Ω series resistors, so none
of its current flows in the BNC output impedance. Total peak draw is 2.2 mA,
which U2B sinks without noticing. `check_circuit.py` recomputes the reference,
all three thresholds, all three peak currents and the worst-case reverse
voltage on each junction from the resistors actually fitted, so those numbers
cannot drift away from the board.

### Three rail lamps, and what "rails OK" was hiding

You were right to ask. The old single green LED hung off +12 V and said
`rails OK`, which was a lie: it knew nothing about −12 V and nothing about the
USB input, so it could sit there looking healthy with half the board dead.

Now there is one lamp per rail, each with its own name on the silkscreen right
beside it:

| lamp | rail | colour | current |
|---|---|---|---|
| D1 | +5 V (USB side of the barrier) | yellow | 1.27 mA |
| D2 | +12 V | green | 2.09 mA |
| D3 | −12 V | white | 0.98 mA |

Three different colours as you suggested, and all three are JLCPCB **Basic**
parts, so the extra colours cost nothing in setup fees. Not red: red reads as
"fault" when here it would mean the rail is *up*, and red/green/blue are
already spoken for by the chaos lamp. D3 runs ground → LED → resistor → −12 V,
so it lights only if the negative rail is genuinely there.

### Probe pads and scope grounds

Thirteen plated holes, each with what it probes written next to it on the
silkscreen (the name is the symbol's value, so the legend cannot disagree with
the netlist):

* **rails:** +5 V, +15 V, −15 V, +12 V, −12 V, GND, GNDU
* **signals:** x, −y, z, −xz/100, −xy/100, and −1.5 V (the lamp reference)

Three **SCOPE GND** anchors: two 1.1 mm holes on 5.08 mm centres. Push a loop
of wire — a resistor lead offcut does — through and solder it, and an alligator
clip has a post to bite. They cost two drill hits each and nothing else. One is
beside the BNC column, one beside the probe row, one in the middle of the
board.

**One deliberate omission.** You listed `dx/dt = 10 (y - x)` among the
interesting places to probe. There is no pad on the summing junctions, and
that is a decision rather than an oversight: a summing junction is a virtual
earth, so its *voltage* is zero by construction and carries no information —
dx/dt exists there only as a **current**. It is also the one node on the board
where a probe changes the answer: 15 pF against a 1 MΩ scale of impedances is a
15 µs pole hanging off the integrator's input. What *is* worth doing is
checking that each junction really sits at 0 V, and for that the summing
resistor pads are the right place to put a tip. The multiplier outputs, which
are real voltages carrying −xz/100 and −xy/100, do get pads.

### The four-layer board: dropped, and here is the number

On the routed two-layer board, tracks cover **1.2 % of the back copper** and
2.6 % of the front. The back is therefore already 98.8 % of an unbroken ground
plane. A dedicated plane layer recovers that last one per cent — against
roughly four times the bare-board price, a second gerber set for somebody to
pick the wrong one of, and (now) an isolation split that would have to be drawn
on four layers instead of two. The fastest thing on this board is a 100 kHz
switching converter and the signals are DC to about 700 Hz.

So it is gone. `route.py` and `gen_pcb.py` still take a layer count and the
four-layer code paths are in git history; nothing in the shipped package
mentions it.

That also answers the older question about two schematics: there is now one
schematic, one board, one project. The duplicate only ever existed because
KiCad binds a project to `<name>.kicad_pro` / `.kicad_sch` / `.kicad_pcb` by
basename, and `kicad-cli pcb drc --schematic-parity` finds the schematic that
way.

### Cross-probing: fixed

It wasn't working because nothing on the board said which symbol each footprint
came from. Each footprint now carries the symbol's UUID as its sheet path plus
`sheetname`/`sheetfile`, and `lorenz.kicad_pro` carries the root sheet in its
`sheets` list. Click a part in either editor and it highlights in the other.
(`make.py` regenerates the project file as its *last* step, because saving a
board through `pcbnew` rewrites `.kicad_pro` and drops that entry.)

### QR codes

Both URLs are on the back, as codes and as text. Nothing in KiCad draws a QR
code and the build has to work from a bare clone, so `scripts/qrcode_gen.py` is
a QR encoder written for this: byte mode, versions 1–6, error correction L or
M, Reed–Solomon over GF(256), all eight masks scored. Both codes are version 4
at level M — 33 × 33 modules, 0.6 mm each, so 19.8 mm square.

Writing your own encoder for something a phone camera has to read is a good way
to ship a beautiful, unreadable rectangle, so it is checked three ways:

1. `python3 scripts/qrcode_gen.py` self-tests: the 32 published format words
   come out of its BCH, 36 symbols round-trip through a decoder written
   alongside it (which verifies every Reed–Solomon block's syndromes), and the
   finder patterns are checked module by module.
2. Against two independent implementations. Its data placement, Reed–Solomon
   and format information match the `qrcode` package **module for module**; its
   mask penalty scoring matches `segno`'s on 200 random matrices. Both were
   installed only as oracles and are not build dependencies. (The two libraries
   disagree with *each other* on mask choice — `qrcode` implements the
   pre-2015 rule 3 and `segno` scores a format region it hasn't written yet —
   so the self-test checks what is actually normative.)
3. `check_outputs.py` reads the rectangles back out of `lorenz.kicad_pcb`,
   samples them into a matrix and decodes it. That check is part of every build.

Two details that would each have shipped a broken code. The modules have to
**touch** — a decoder locates the symbol by the 1:1:3:1:1 run lengths across a
finder pattern, and I measured that even a 10 % gap is fatal — so each run of
dark modules in a row is drawn as one filled rectangle. And the code has to be
**mirrored in board coordinates**, exactly like back-layer text, or it reads
correctly only through the board; I settled that by plotting a mirrored legend
beside it and seeing which way round the legend read. As a final check, OpenCV
read both codes straight out of the plotted `B.Silkscreen` PDF.

### The switch table

Rebuilt in both places.

On the **board** it sits directly over the switch: each `off`/`ON` cell is
centred on the slider it refers to, there is a silkscreen bar between the two
banks of three, the speed names the row, and the capacitance and time constant
are in their own columns on the right with their own header. Getting the six
cells over the six sliders is what fixed the "`1-3` is above both columns"
problem you spotted — the columns *are* the sliders now.

```
                     SPEED SELECT
     SW1    1    2    3  |  4    5    6      C
    -----------------------------------------------
    fast!  off  off  off | off  off  off   2.2 nF
    nice!  ON   ON   ON  | off  off  off   102 nF
    slow!  off  off  off | ON   ON   ON    472 nF
              [ the six sliders ]
           ON is marked on the switch
```

That band had to be made: the middle capacitor bank moved 4 mm further from its
row so the legend has somewhere to go that lines up with the sliders. On the
**schematic** it is now a drawn table with ruled columns rather than three
sentences, plus a line saying what happens if you turn both banks on.

`ON` is printed on the switch body itself, and I have not held one, so the
silkscreen says that rather than guessing which way the sliders push.

### Paul's name and his page, on the front

Front silkscreen, top of the board, in this order and these sizes:

```
             AI UNLEASHES CHAOS                       2.8 mm
    Lorenz attractor  --  circuit by Paul Horowitz    1.6 mm
     seti.harvard.edu/unusual_stuff/misc/lorenz.htm   1.1 mm
 PCB by Jason Gallicchio and Claude   2026-09-15  rev A
```

The back carries the same title block, the equations, the attractor and both QR
codes.

### Labels

Understood — one human-readable *comment* per signal, and the internal KiCad
labels can be whatever gives the best error checking. So the sheet now names
the three summing junctions `SJ_X`, `SJ_Y`, `SJ_Z` (they had auto-generated
names before, which made every check message unreadable), while the drawn `x`
still appears beside the bus every time it leaves for a load, the way Paul does
it. A KiCad label is a connection; a drawn note is not.

### Datasheets

`python3 scripts/get_datasheets.py` pulls one PDF per LCSC code in
`scripts/parts.py` — 30 order codes, connectors included — plus Paul's page, into
`datasheets/`. It skips anything already there, including files you downloaded
by hand under a different name. The directory is in `.gitignore`: not checked
in, for copyright.

### Other items

* **The 3D model was missing parts.** The DIP switch, the A0515S module and now
  the RGB lamp all have hand-written VRML stand-ins in
  `hardware/lib/lorenz.3dshapes/`. The reason they were missing at all is worth
  recording: `gen_models.py` existed but `make.py` never called it, so a fresh
  clone had no models. It is wired in now, and `check_outputs.py` fails the
  build if any footprint names a model that is not on disk. (Mounting holes,
  probe pads and the solder jumper are allowed to have none — nothing is
  fitted there.)
* **`MountingHole` on the silkscreen** — gone, along with its reference
  designator. The hole is self-explanatory.
* **The layer images were mostly whitespace.** They now crop to the ink rather
  than to an assumed corner, which also fixed a bug I had not noticed: the
  back-silkscreen image was **completely blank**, because a mirrored plot lands
  on the other side of the page and the old fixed crop was looking at the wrong
  corner.
* **`make.py --clean`** removes everything the build generates and prints what
  it removed, so the list doubles as the answer to "what is generated and what
  has to live in git". It leaves KiCad's own `.kicad_prl` alone if KiCad has
  the project open.
* **Still rev A**, and it stays rev A until you pay a fab.
* I have not looked at `next_prompt.md`.

### What the build does now

```
$ ./make.py
=== self-tests ======================== rotation mapping vs KiCad's netlister
=== symbol and footprint libraries ==== 6 symbols, 5 footprints, 6 3D models
=== schematic ========================= ERC 0, 116 circuit checks, 316 text
                                        items with no overlaps
=== PCB: lorenz (2 layers) ============ 84 footprints, 581 tracks, 438 vias,
                                        4 zones, DRC 0 with parity
=== manufacturing outputs ============= gerbers, drill, BOM, CPL, PDFs, PNGs,
                                        3D renders, STEP; both QR codes decoded
=== documentation ===================== docs/MANUFACTURING.md
=== project files ===================== .kicad_pro last, so cross-probing works
```
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

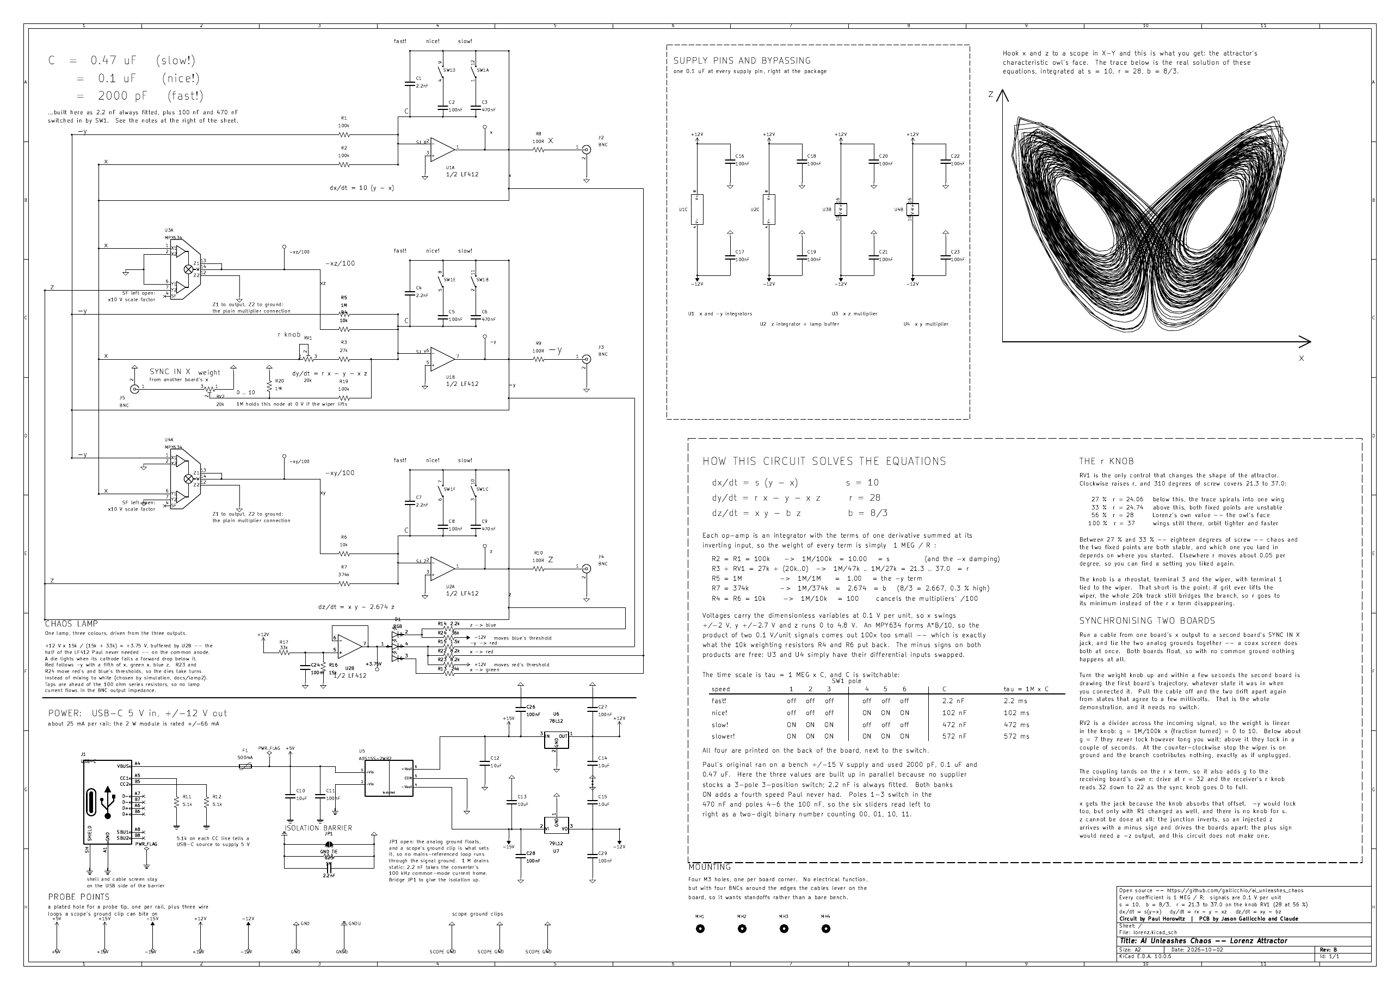
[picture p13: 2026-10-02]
docs/history/response-13/schematic.png

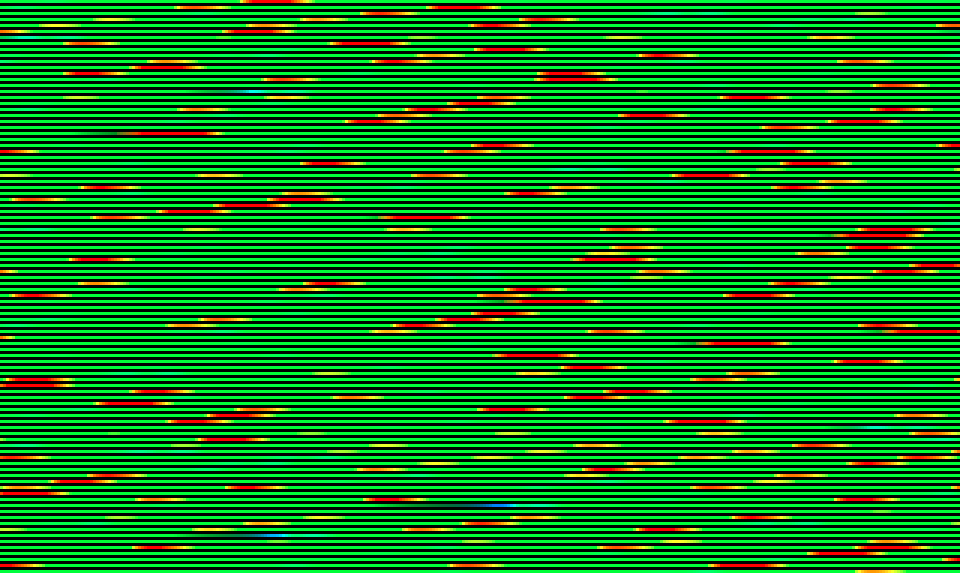
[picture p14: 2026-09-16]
docs/lamp/opt-074.png

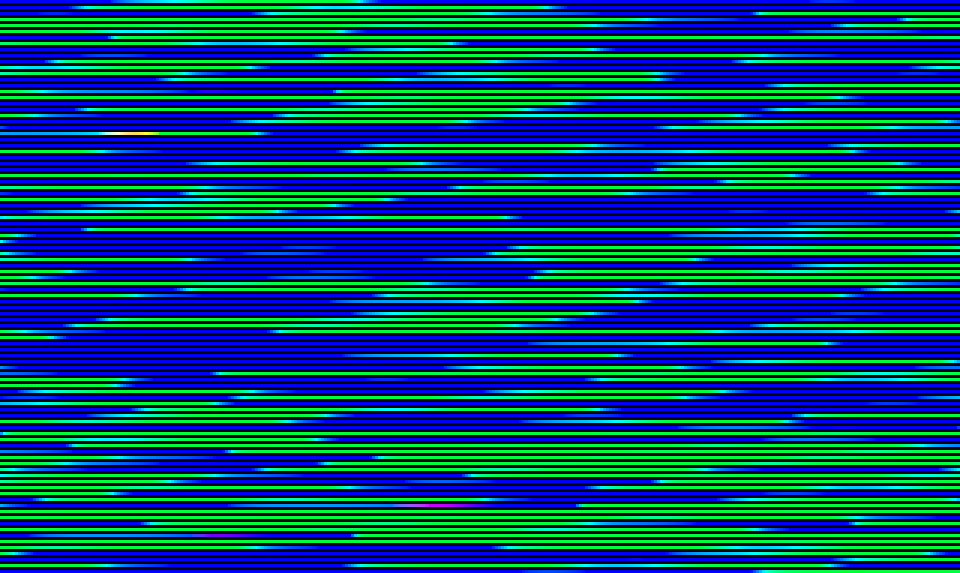
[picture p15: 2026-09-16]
docs/lamp/opt-034.png

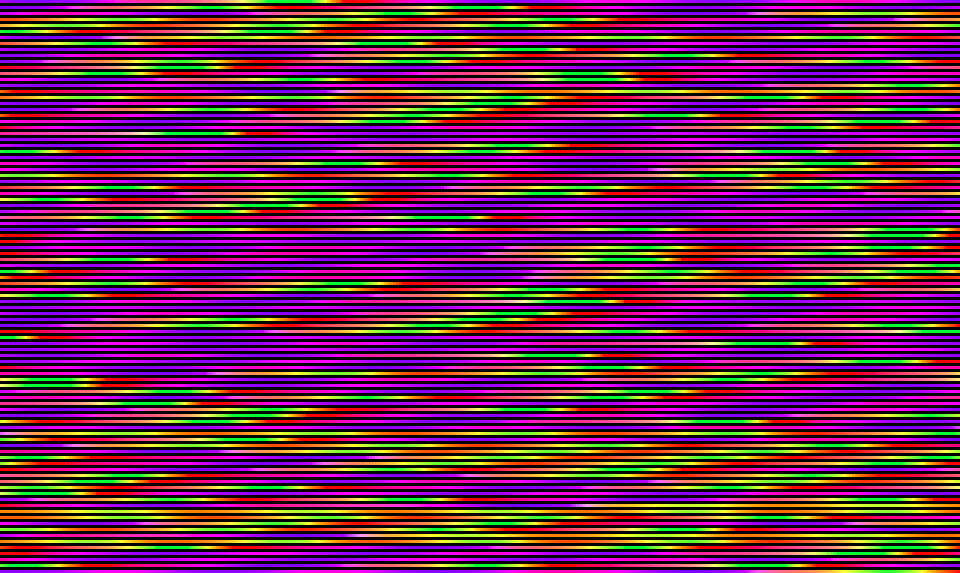
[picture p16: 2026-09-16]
docs/lamp/bestof/opt-085.png

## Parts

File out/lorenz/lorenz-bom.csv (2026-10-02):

Comment | Designator | Footprint | LCSC Part #
100nF | C2,C5,C8 | C_1206_3216Metric | C170182
470nF | C3,C6,C9 | C_1206_3216Metric | C277483
2.2nF | C1,C4,C7,C25 | C_0805_2012Metric | C28260
10uF | C10,C12,C13,C14,C15 | C_0805_2012Metric | C15850
100nF | C11,C16,C17,C18,C19,C20,C21,C22,C23,C24,C26,C27,C28,C29 | C_0805_2012Metric | C49678
RGB | D1 | LED_RGB_PLCC4_3.5x2.8mm | C2962095
500mA | F1 | PTC_1812_4532Metric | C17313
USB-C | J1 | USB_C_Receptacle_HRO_TYPE-C-31-M-12 | C165948
BNC | J2,J3,J4,J5 | BNC_KYWE_RightAngle | C41416668
27k | R3 | R_0805_2012Metric | C17593
374k | R7 | R_0805_2012Metric | C2933427
24k | R13 | R_0805_2012Metric | C17575
2.2k | R14 | R_0805_2012Metric | C17520
1.5k | R15 | R_0805_2012Metric | C4310
15k | R16 | R_0805_2012Metric | C17475
33k | R17 | R_0805_2012Metric | C17633
36k | R24 | R_0805_2012Metric | C4360
10k | R4,R6 | R_0805_2012Metric | C17414
5.1k | R11,R12 | R_0805_2012Metric | C27834
8.2k | R22,R23 | R_0805_2012Metric | C17828
20k | RV1,RV2 | Potentiometer_Bourns_3386P_Vertical | C116287
100k | R1,R2,R19 | R_0805_2012Metric | C149504
100R | R8,R9,R10 | R_0805_2012Metric | C17408
1M | R5,R18,R20 | R_0805_2012Metric | C17514
SW_DIP_x06 | SW1 | SW_DIP_SPSTx06_KingTek_DSIC06_P2.54mm | C54952
A0515S-2WR2 | U5 | DCDC_SIP_A05xxS_1W_2W | C19272710
78L12 | U6 | SOT-89-3 | C8615
79L12 | U7 | SOT-89-3 | C8626
LF412 | U1,U2 | SOIC-8_3.9x4.9mm_P1.27mm | C15322
MPY634 | U3,U4 | SOIC-16W_7.5x10.3mm_P1.27mm | C1523457

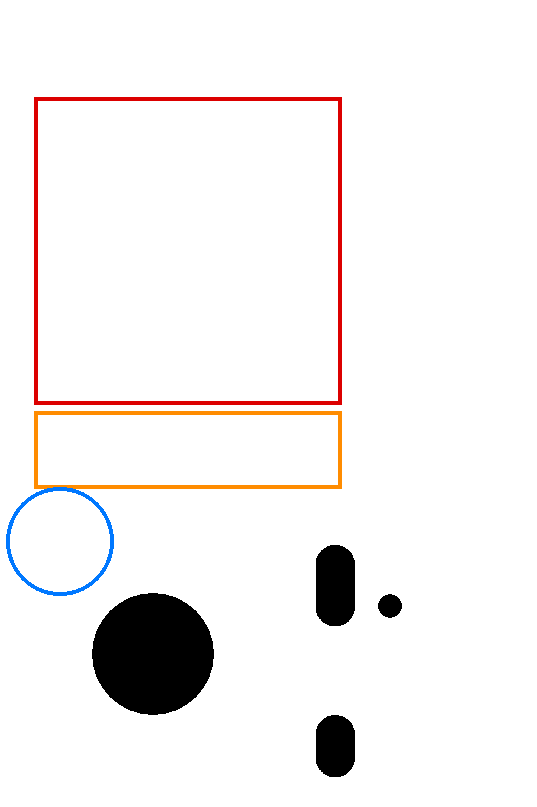
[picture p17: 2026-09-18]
docs/history/response-11/order-code-back.png

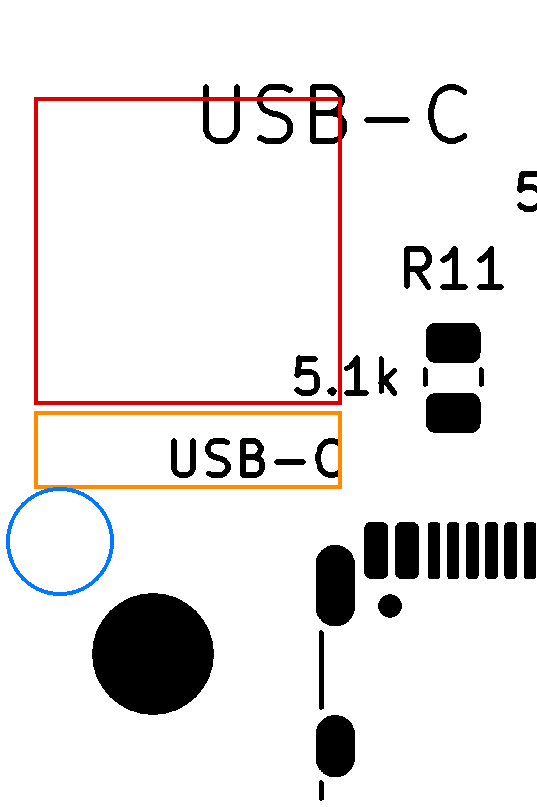
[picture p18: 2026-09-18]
docs/history/response-11/order-code-front.png

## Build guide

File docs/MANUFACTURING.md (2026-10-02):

# Manufacturing

One board, two layers, 100 x 100 mm.  It passes ERC, DRC (with
schematic parity), the circuit checker and the fab-package checks with
zero violations, and `./make.py` rebuilds and rechecks everything from
scratch in about forty seconds.

The copper is split: the USB input has its own ground plane in the
bottom-left corner, isolated from the analog ground by the converter and
bridged only by R18, C25 and JP1.  Do not scratch across the 1 mm gap.

## What to upload

| file | where it goes |
|---|---|
| `out/lorenz/lorenz-gerbers.zip` | the *Add gerber file* box |
| `out/lorenz/lorenz-bom.csv` | the BOM box (JLCPCB column layout) |
| `out/lorenz/lorenz-cpl_jlc_corrected.csv` | the CPL / pick-and-place box, at JLCPCB |
| `out/lorenz/lorenz-cpl.csv` | the CPL / pick-and-place box, anywhere else |

## Board options to pick

| option | value | why |
|---|---|---|
| Layers | 2 | what the gerber set contains |
| Dimensions | 100 x 100 mm | the discounted size at all three houses |
| Thickness | 1.6 mm | the BNC flanges and the USB-C shell expect it |
| Surface finish | HASL or ENIG | either; ENIG is flatter for the 0.5 mm-pitch USB-C |
| Copper weight | 1 oz | the design rules assume it |
| Via covering | Tented | the ground stitching is dense; open vias would ruin the silkscreen |
| Assembly side | Top | every placed part is on the front |
| Parts source | JLCPCB (no consignment) | every line has an LCSC code |

## Cost

The board has **192 SMT joints** and **35 through-hole joints** on
30 BOM lines (16 JLCPCB Basic, 14 Extended).
Parts alone are **$74.32 per board**, of which
$61.17 is the pair of MPY634 multipliers.

**2 boards, two layers, fully assembled including through-hole**

| line | cost |
|---|---|
| bare PCBs | $2.00 |
| parts ($74.32 x 2) | $148.63 |
| assembly: setup $8.00 + stencil $1.50 + 384 SMT joints + 14 extended parts + 70 THT joints | $73.15 |
| shipping (DHL, worldwide) | $22.00 |
| **total** | **$245.79**  ($122.89 each) |

**5 boards, two layers, fully assembled including through-hole**

| line | cost |
|---|---|
| bare PCBs | $2.00 |
| parts ($74.32 x 5) | $371.58 |
| assembly: setup $8.00 + stencil $1.50 + 960 SMT joints + 14 extended parts + 175 THT joints | $105.63 |
| shipping (DHL, worldwide) | $22.00 |
| **total** | **$501.22**  ($100.24 each) |

**10 boards, two layers, fully assembled including through-hole**

| line | cost |
|---|---|
| bare PCBs | $4.00 |
| parts ($74.32 x 10) | $743.17 |
| assembly: setup $8.00 + stencil $1.50 + 1920 SMT joints + 14 extended parts + 350 THT joints | $159.76 |
| shipping (DHL, worldwide) | $22.00 |
| **total** | **$928.93**  ($92.89 each) |

Four layers would cost about $524.22 for five ($104.84 each) -- the only change is the bare-board price --
and buys almost nothing here: tracks cover 1.2 % of the back copper, so
the pour on the two-layer board is already 98.8 % of an unbroken ground
plane.  That is why this project ships one board.

Two boards is the sensible order: one for Paul and one to keep.

## Uploading to JLCPCB

| upload | file |
|---|---|
| gerbers | `lorenz-gerbers.zip` |
| BOM | `lorenz-bom.csv` |
| placements | **`lorenz-cpl_jlc_corrected.csv`** |
| paste into the order notes | `lorenz-assembly-notes.txt` |

Use the *corrected* placement file for JLCPCB, and the plain
`lorenz-cpl.csv` for anyone else.  JLCPCB places from its own model of
each part, and for some parts that model is turned differently from
KiCad's footprint, so a file that is right everywhere else is wrong by
a fixed angle there.  The angle belongs to the part number, not to the
package: it is a property of JLC's drawing of that one LCSC part.

| parts | LCSC | turned by |
|---|---|---|
| U1, U2 | C15322 | 270 deg counter-clockwise |
| U3, U4 | C1523457 | 270 deg counter-clockwise |
| SW1 | C54952 | 270 deg counter-clockwise |
| U6 | C8615 | 180 deg counter-clockwise |
| U7 | C8626 | 180 deg counter-clockwise |
| J2, J3, J4, J5 | C41416668 | 90 deg counter-clockwise |

Everything else -- every resistor, every capacitor -- is symmetric or
already agrees, and is left alone.  `check_outputs.py` proves the two
files differ in nothing but those angles.

### What the preview gets wrong, and why it does not matter

JLCPCB draws each part from its own model, and that model has its own
idea of where the middle of the part is.  For some of ours it does not
agree with the middle of the body, so the preview draws the part beside
its pads however the placement file is written.  There is nothing in a
CPL that can say *use your origin, not mine* -- the only lever is the
coordinate itself, and moving that to flatter a preview would put a
wrong number in the file for everybody else.

Three of the parts that look wrong there cannot go in wrong at all:

| part | holes | fits at |
|---|---|---|
| U5, the DC/DC module | 5, with a gap where pin 3 would be | one orientation |
| RV1, RV2, the trimmers | 3 in an L | one orientation |

A hole pattern that does not map onto itself under a quarter turn is
its own key: there is exactly one way the part goes into the board, and
an operator putting legs through holes cannot do anything else with it.
`check_outputs.py` re-derives that from the board file on every build,
so it stays true rather than merely having been true once.

The BNCs are *not* keyed -- four symmetric ground posts and a centre
pin -- which is why their 90 degree correction is in the table above,
and why the barrel pointing off the board edge is worth a glance.

J1, the USB-C receptacle, sits at the board edge deliberately: its body
is flush with the edge so a cable with a moulded body can seat.  A 3D
preview showing it overhang the edge is showing it correctly.

### Still unverified

One rotation cannot be seen in their preview, because JLCPCB has no
drawing of the part to turn:

* **C2962095** -- D1, the RGB lamp -- JLCPCB has no drawing of this part, so it appears as an unknown-part checkerboard and its rotation cannot be read off the preview at all.

It is left uncorrected, and rev A proved that right: its boards came
back from JLCPCB with D1 fitted correctly from exactly this file, the
same footprint at the same place and angle as on this board.  It still
gets its own paragraph below and its own line in the assembler's
notes, because their preview will still show a checkerboard.

## Check these before you pay

The one thing that cannot be checked from here is how the assembler
turns each part.  Your CPL says which way; their library has its own
idea of zero degrees, and where the two disagree a polarised part goes
in backwards.  JLCPCB renders every part on the board before you
confirm the order.  Compare that rendering with this table and with
`lorenz-assembly-top.pdf`, which prints 1:1.

The lamp, the DIP switch and the two trimmers carry a filled triangle
on the front silkscreen, printed just outside the outline and pointing
at pin 1.  It is drawn from the real pad, so it is right by
construction; use it as the reference when you compare the rendering.
The SOICs and the two SOT-89s are not marked that way because KiCad's
own footprints already print a pin-1 dot or a notched corner on them,
and two marks beside each other are two marks to reconcile.

| part | what to look for | should be |
|---|---|---|
| D1 | the RGB lamp's pin 1, the common anode | bottom left, the corner the triangle points at |
| RV1 | the r trimmer, terminal 1 | the lower pad, the one the triangle points at; the screw is on top |
| RV2 | the sync weight trimmer, terminal 1 | same part, same way up, directly above RV1 |
| J5 | SYNC IN X | barrel pointing off the left edge, in line with the x output on the right |
| U6 | 78L12, SOT-89 | pin 1 (OUT) on the left, tab to ground |
| U7 | 79L12, SOT-89 | pin 1 (GND) on the left; its tab is at -15 V, not ground |
| U1, U2 | LF412 SOIC-8 | pin 1 dot at the top left |
| U3, U4 | MPY634 SOIC-16W | pin 1 dot at the top left |
| J1 | USB-C receptacle | opening facing off the board edge |
| SW1 | 6-way DIP switch | slider 1 at the left, the part's own "ON" printing facing the "ON ->" arrow on the board |
| U5 | the converter, hand-fitted | pin 1 is the square pad, at the left, marked on the silkscreen |
| F1 | PTC fuse | not polarised |

The four BNCs and the converter are through-hole and can be checked
by eye after assembly: the converter's own printed face carries its pin
numbers.

## The through-hole parts

8 parts are through-hole: **J1, J2, J3, J4, J5, RV1, RV2, U5** -- the four BNC jacks, the two trimmers, the DC/DC module and the USB-C shell tabs.
They are included in the BOM and the CPL, so a fab that offers
through-hole assembly will fit them.  If you would rather not pay for
that, deselect them at checkout and solder them yourself: they are the
four largest, easiest joints on the board and take about ten minutes.
Everything else is 0805, 1206, SOIC or SOT-89 and is hand-workable too.

## Check these orientations in the fab's preview

Rotation in a CPL is the one thing a fab's importer cannot verify for
you: a part whose LCSC drawing points a different way than the KiCad
footprint will be fitted turned.  The symmetric parts (every resistor
and capacitor) cannot go wrong.  These can:

| part | what to look for |
|---|---|
| D1 | pin 1, the common anode, at the bottom left -- the die order is red, green, blue anticlockwise from it |
| RV1, RV2 | terminal 1 at the bottom, terminal 3 at the top, wiper to the right |
| J5 | barrel off the left edge, the mirror image of J2, J3 and J4 |
| U1, U2 | pin 1 dot at the top-left, toward C16 / C18 |
| U3, U4 | pin 1 dot at the top-left |
| U5 | pin 1 (+Vin) at the left, printed face up |
| U6, U7 | tab toward the board centre; U6 tab is ground, U7 tab is -15 V |
| SW1 | slider 1 at the left; pin 1 is on the side *away* from the part's "ON" legend, which is where the board's triangle points |
| J1 | opening facing off the bottom edge |

## Parts, stock and alternates

Stock was last checked on 2026-10-02, the date on the silkscreen, at LCSC for every part held in the thousands or fewer; the
plentiful passives were checked when rev A was frozen.  JLCPCB's own
assembly stock is what counts, and their BOM upload shows it per line.

| ref | value | LCSC | JLC | unit | stock then | notes |
|---|---|---|---|---|---|---|
| C1,C4,C7,C25 | 2.2nF | C28260 | basic | $0.0280 | 179,637 | C0G/NP0 50V |
| C10,C12,C13,C14,C15 | 10uF | C15850 | basic | $0.0840 | 6,702,077 | X5R 25V, 0805 - bulk |
| C11,C16,C17,C18,C19,C20,C21,C22,C23,C24,C26,C27,C28,C29 | 100nF | C49678 | basic | $0.0190 | 18,183,154 | X7R 50V, 0805 - bypass |
| C2,C5,C8 | 100nF | C170182 | extended | $0.1870 | 193,311 | C0G/NP0 50V, 1206 |
| C3,C6,C9 | 470nF | C277483 | extended | $0.0320 | 190,079 | X7R 50V, 1206 |
| D1 | RGB | C2962095 | extended | $0.0650 | 9,720 | Common-anode RGB lamp, PLCC-4: red from -y (and x), green from x, blue from z |
| F1 | 500mA | C17313 | extended | $0.0680 | 142,624 | Resettable PTC on the USB input |
| J1 | USB-C | C165948 | extended | $0.1860 | 230,097 | USB-C receptacle, power only (16 pin) |
| J2,J3,J4,J5 | BNC | C41416668 | extended | $1.5490 | 628 | 50 ohm BNC jack, right angle, 4 ground posts on 8x8 mm |
| R1,R2,R19 | 100k | C149504 | basic | $0.0060 | 4,893,299 |  |
| R11,R12 | 5.1k | C27834 | basic | $0.0060 | 3,917,491 |  |
| R13 | 24k | C17575 | basic | $0.0021 | 326,300 |  |
| R14 | 2.2k | C17520 | basic | $0.0021 | 2,963,000 |  |
| R15 | 1.5k | C4310 | basic | $0.0015 | 585,325 |  |
| R16 | 15k | C17475 | basic | $0.0021 | 481,800 |  |
| R17 | 33k | C17633 | basic | $0.0028 | 570,100 |  |
| R22,R23 | 8.2k | C17828 | basic | $0.0021 | 105,200 |  |
| R24 | 36k | C4360 | basic | $0.0029 | 137,500 |  |
| R3 | 27k | C17593 | basic | $0.0013 | 238,446 |  |
| R4,R6 | 10k | C17414 | basic | $0.0040 | 53,835,303 |  |
| R5,R18,R20 | 1M | C17514 | basic | $0.0050 | 2,688,974 |  |
| R7 | 374k | C2933427 | extended | $0.0040 | 18,582 |  |
| R8,R9,R10 | 100R | C17408 | basic | $0.0040 | 10,085,527 |  |
| RV1,RV2 | 20k | C116287 | extended | $0.4458 | 648 | 20k single-turn cermet trimmer, 9.5 mm square, top adjust.  Two are fitted: RV1 sets r, as a rheostat with terminal 1 tied to the wiper so grit means maximum resistance and never an open; RV2 sets the sync weight, as a plain divider across the incoming signal so the weight is linear in the knob and reaches zero |
| SW1 | SW_DIP_x06 | C54952 | extended | $0.5710 | 1,805 | 6-way SMD DIP switch, 2.54 mm pitch - integrator speed select |
| U1,U2 | LF412 | C15322 | extended | $0.9060 | 7,873 | Dual JFET-input op-amp (Paul's original part) |
| U3,U4 | MPY634 | C1523457 | extended | $30.5860 | 848 | Four-quadrant analog multiplier, W=(X1-X2)(Y1-Y2)/10 (Paul's part) |
| U5 | A0515S-2WR2 | C19272710 | extended | $1.5950 | 196 | Isolated 5V -> +/-15V 2W DC/DC module |
| U6 | 78L12 | C8615 | extended | $0.0990 | 52,154 | +12 V linear regulator (SOT-89: 1=OUT 2=GND 3=IN) |
| U7 | 79L12 | C8626 | extended | $0.1180 | 11,413 | -12 V linear regulator (SOT-89: 1=GND 2=IN 3=OUT) |

### If something is out of stock

**LF412CDR** (C15322)
  - TL072CDT / C6961 (JLCPCB Basic, $0.16) - same pinout, slightly higher bias current

**MPY634KU/1K** (C1523457)
  - AD633ARZ / C431243 - identical transfer function but SOIC-8, needs a different footprint; zero stock at JLCPCB 2026-09-15

**BNC-KYWE-295-W4-N** (C41416668)
  - HL2-BNC-KYWE / C48606310 (180 in stock)
  - MLD-BNC-KYWE-L29.5 / C52766468 (67 in stock)

**A0515S-2WR2** (C19272710)
  - A0515S-2WR2L / C20622616 (233 in stock)
  - A0515S-1WR3 / C5369388 (920 in stock, 1W) - same footprint and pinout; 1W is enough for this board's ~20 mA/rail but leaves less margin

**MHPA3528CRGBCT** (C2962095)
  - MHPC3528CRGBCT / C2962096 is the same part with a common *cathode*: same footprint, same dies, but pins 1 and 4 swap roles, so the board would have to change with it

**3386P-1-203LF** (C116287)
  - 3386P-1-103LF / C116281 (10k, 1700 in stock) with R3 raised to 33k gives r = 23 to 30 -- a narrower sweep that never leaves the chaotic region

The thinnest line is the BNC-KYWE-295-W4-N: 628 in stock and 4 per board, so about 157 boards' worth; next is the A0515S-2WR2 at about 196.
All three listed BNC alternates are the same 'BNC-KYWE' body -- a
10 x 10 mm flange, four ground posts on an 8 x 8 mm square and a
centre pin -- so the footprint takes any of them, but measure the
drawing before you substitute.

## Bringing the board up

1. Plug in USB-C.  The chaos lamp should light within a second: it
   hangs on +12 V through U2B and on all three integrator outputs, so
   it only comes on once the whole board works.  A new DIP switch
   usually arrives all off, which is *fast!*: there the lamp can only
   show its average colour, a steady violet.
2. Measure the rails at C14 and C15: +12.0 V and -12.0 V, a few tens of
   millivolts of ripple at most.  The board draws about 20 mA a rail.
3. Set SW1 to *nice!* -- switches 4, 5 and 6 on, 1, 2 and 3 off.
4. Scope on x and z, X-Y mode, about 1 V/div on both.  The owl's face
   should appear within a second or so of power-up; the circuit starts
   itself, because the origin is an unstable fixed point and op-amp
   offset is more than enough to push it off.
5. `-y` is inverted on purpose, exactly as on Paul's original sheet.
6. Try *fast!* (all switches off), *slow!* (1, 2, 3 only) and
   *slower!* (all six on).  Poles 1-3 switch in the 470 nF and poles
   4-6 the 100 nF, so the six sliders read left to right as a
   two-digit binary number: 00, 01, 10, 11.
7. To watch the lamp, use *slow!* or *slower!*.  It visits every hue
   about equally: on one wing violet through magenta to red, on the
   other green through cyan to azure, the colour travelling about twice
   round the wheel a second.  At *nice!* the eye blurs most of that.
8. Turn RV1 clockwise to raise r and anticlockwise to lower it.  About
   a third of the way round from the anticlockwise stop the attractor
   collapses into one wing and the lamp settles on a colour; back the
   other way and it starts wandering again.

If nothing moves, the first thing to check is that both MPY634s are
powered: pin 16 at +12 V and pin 10 at -12 V.

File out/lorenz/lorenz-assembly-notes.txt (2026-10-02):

AI UNLEASHES CHAOS -- notes for the assembler
=============================================

PLACEMENTS
  Use lorenz-cpl_jlc_corrected.csv for JLCPCB.  It is lorenz-cpl.csv with
  JLCPCB's own per-part rotations applied; use the plain file anywhere else.

D1 -- MHPA3528CRGBCT, common-anode RGB LED, PLCC-4.
  Your placement preview may have no drawing for this part.  Pin 1 is the
  ANODE.  On the board it is the corner the filled silkscreen triangle points
  at, at the bottom left of the part in lorenz-assembly-top.pdf, which prints
  1:1.  Clockwise from there, seen from above: 1 anode, 2 blue (top left),
  3 green (top right), 4 red (bottom right).
  If that is not enough to place it with confidence, leave D1 off and we will
  hand-solder it; nothing else on the board depends on it.

U5, RV1, RV2 -- through-hole, and keyed by their own hole patterns.  Each of
  them fits the board in exactly one orientation, so however the preview
  draws them they cannot be fitted turned.
    U5   pin 1 is the left-hand hole of the row of five; the row has a gap
         where pin 3 would be, which is what keys it.
    RV1  terminal 1 is the hole the silkscreen triangle points at.  The
    RV2  adjusting screw is on top.

J2, J3, J4, J5 -- BNC jacks.  The barrel points OFF the board edge: J2, J3 and
  J4 off the right-hand edge, J5 off the left-hand edge.

J1 -- USB-C receptacle.  It sits at the board edge on purpose, with its body
  flush so that a cable with a moulded body can seat.  If a 3D preview shows
  it overhanging the edge, that is correct.

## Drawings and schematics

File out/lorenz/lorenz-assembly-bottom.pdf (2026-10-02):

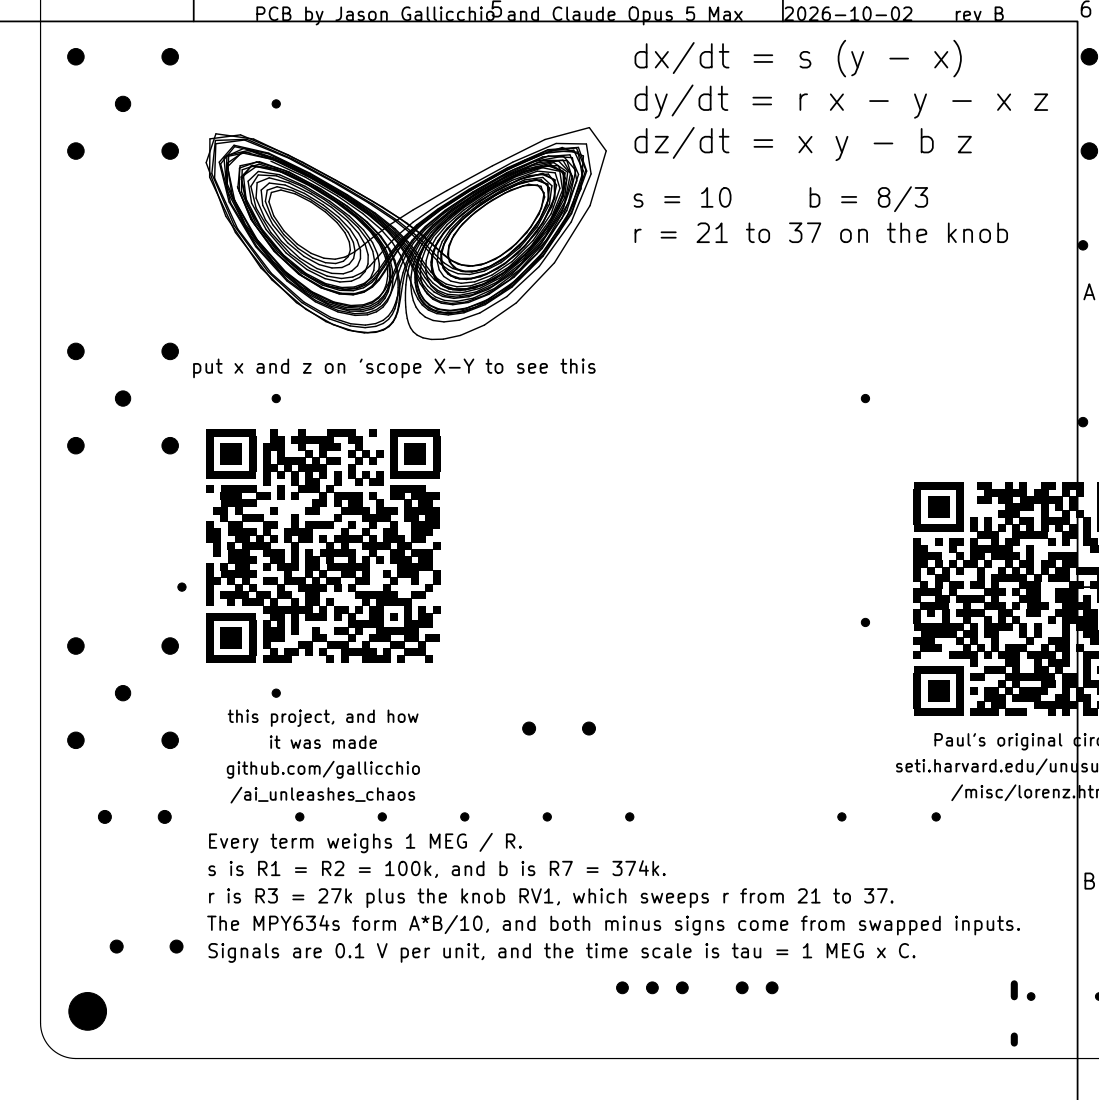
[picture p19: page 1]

dy/dt = r x - y - x z dz/dt = x y - b z AI UNLEASHES CHAOS

Lorenz attractor -- circuit by Paul Horowitz

r = 21 to 37 on the knob

this project, and how

Paul's original circuit seti.harvard.edu/unusual_stuff /misc/lorenz.htm

Every term weighs 1 MEG / R. s is R1 = R2 = 100k, and b is R7 = 374k. r is R3 = 27k plus the knob RV1, which sweeps r from 21 to 37. The MPY634s form A*B/10, and both minus signs come from swapped inputs.

Size: A4 | Rev:
KiCad E.D.A. 10.0.6 | Id: 1/1

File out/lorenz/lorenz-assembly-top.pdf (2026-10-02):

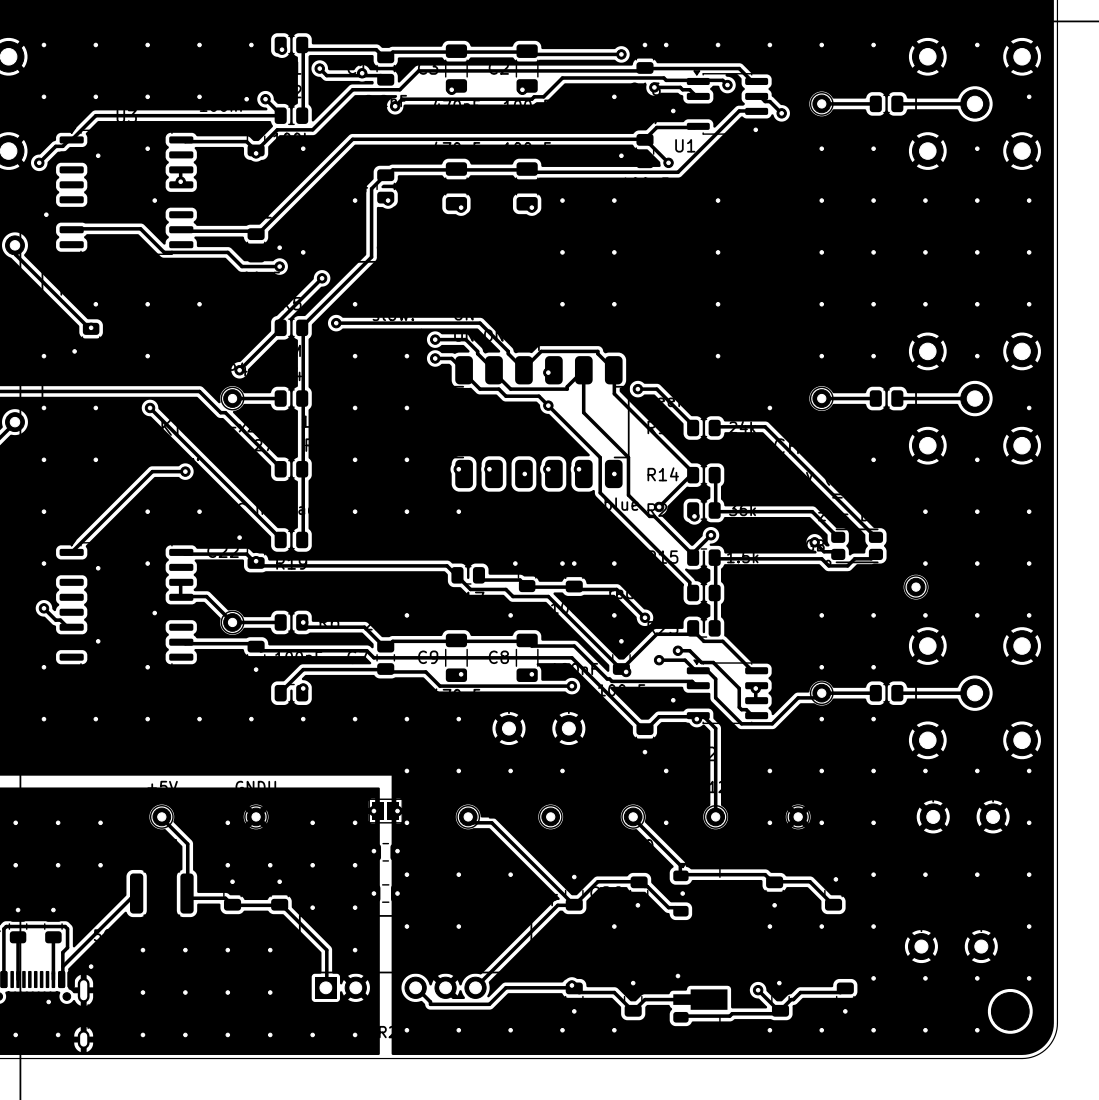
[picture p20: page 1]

seti.harvard.edu/unusual_stuff/misc/lorenz.htm

Size: A4 | Rev:
KiCad E.D.A. 10.0.6 | Id: 1/1

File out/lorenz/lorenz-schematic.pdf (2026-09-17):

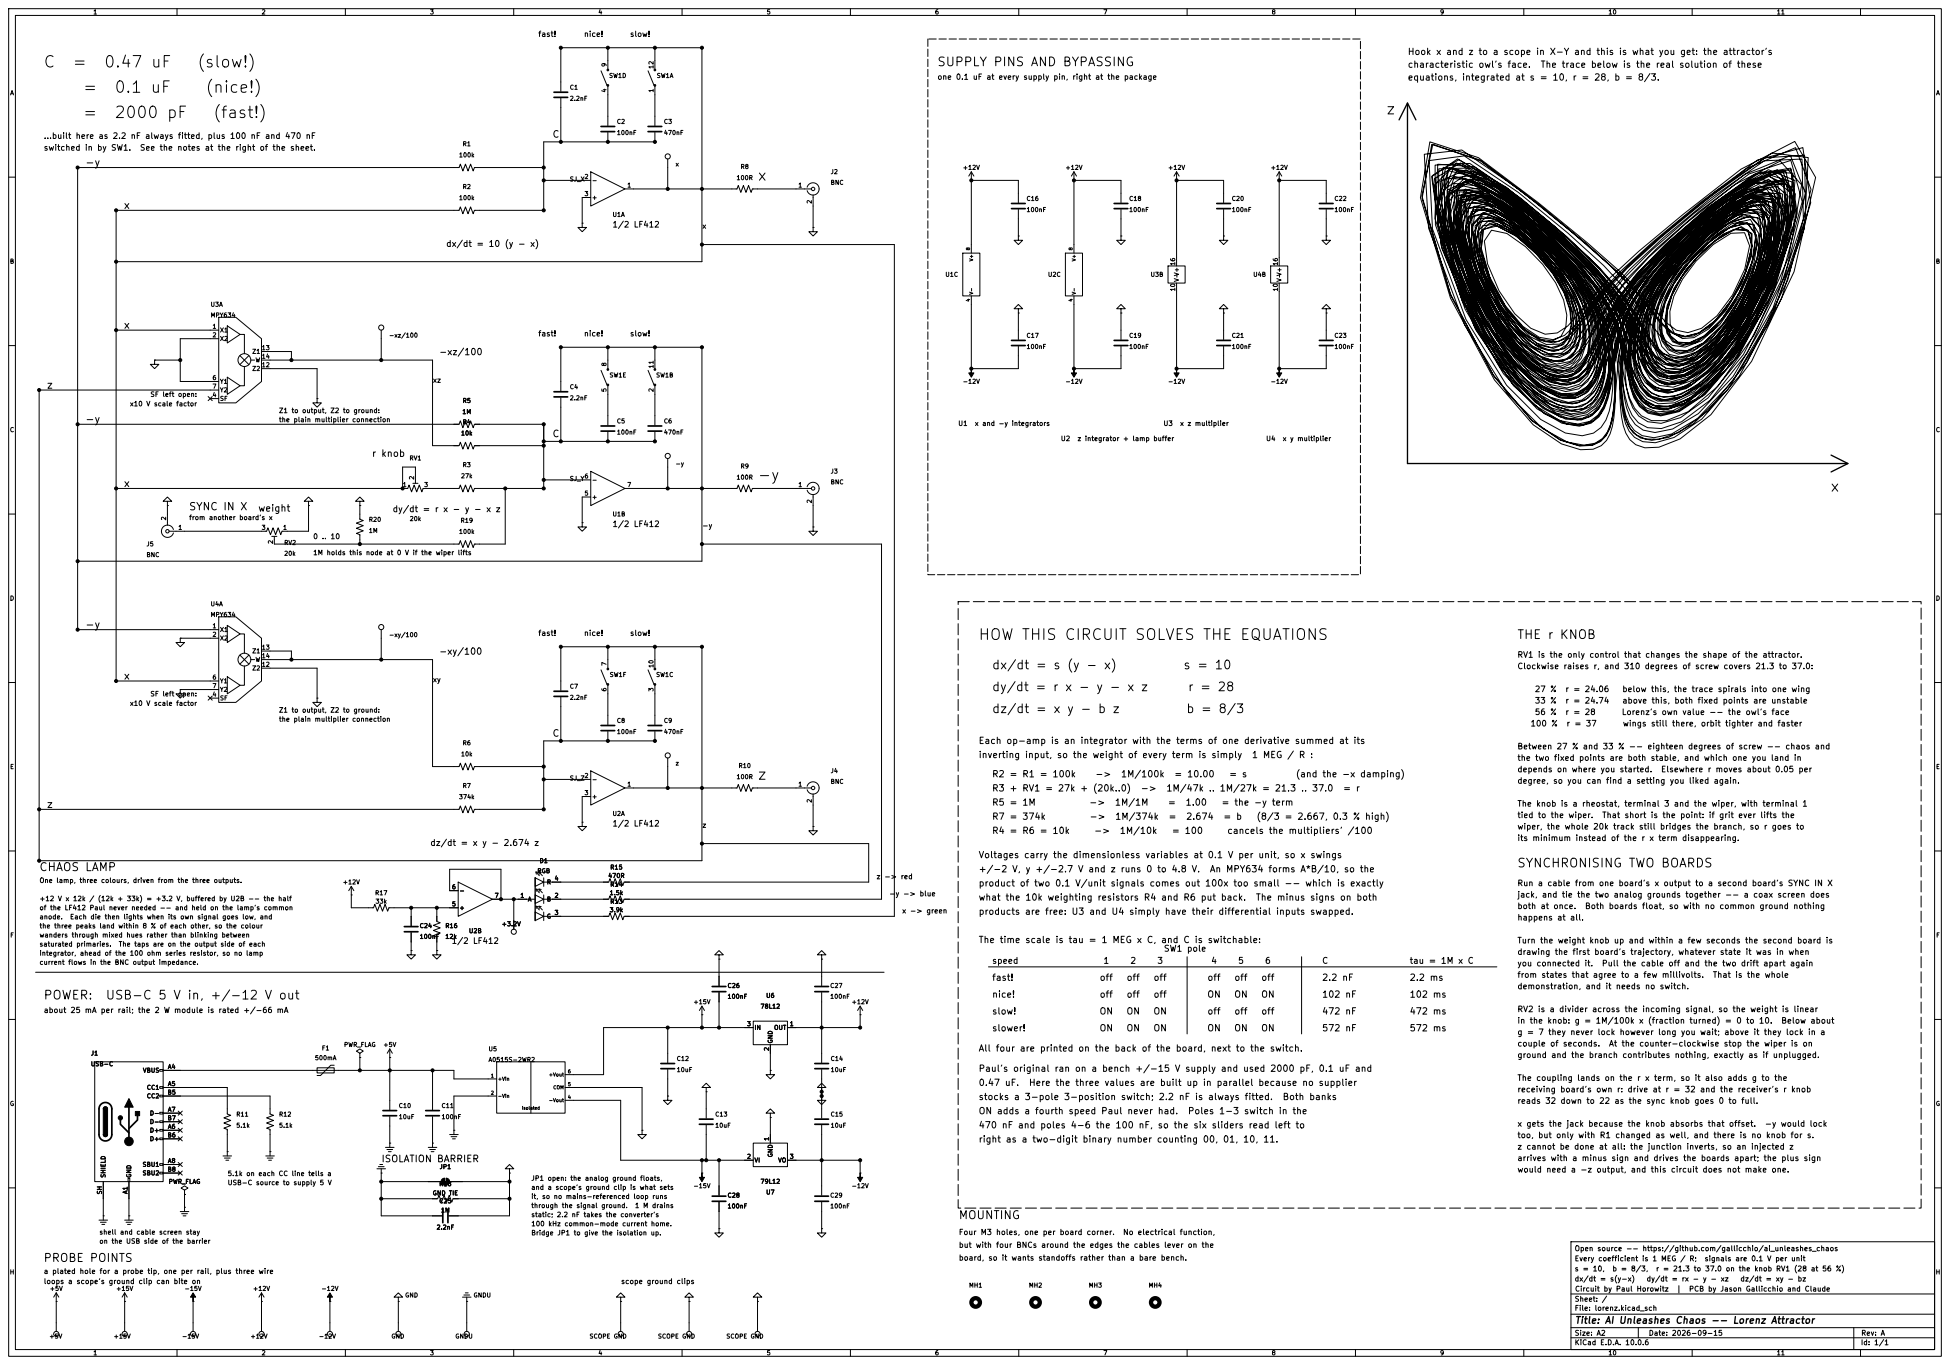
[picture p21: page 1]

SUPPLY PINS AND BYPASSING

Hook x and z to a scope in X-Y and this is what you get: the attractor's
characteristic owl's face. The trace below is the real solution of these
equations, integrated at s = 10, r = 28, b = 8/3.

one 0.1 uF at every supply pin, right at the package

...built here as 2.2 nF always fitted, plus 100 nF and 470 nF
switched in by SW1. See the notes at the right of the sheet.

SF left open: SYNC IN X
x10 V scale factor

the plain multiplier connection Z1 to output, Z2 to ground:

1M holds this node at 0 V if the wiper lifts z

HOW THIS CIRCUIT SOLVES THE EQUATIONS

RV1 is the only control that changes the shape of the attractor.
Clockwise raises r, and 310 degrees of screw covers 21.3 to 37.0:

Each op-amp is an integrator with the terms of one derivative summed at its

Between 27 % and 33 % -- eighteen degrees of screw -- chaos and
the two fixed points are both stable, and which one you land in
depends on where you started. Elsewhere r moves about 0.05 per
degree, so you can find a setting you liked again.

R3 + RV1 = 27k + (20k..0) -> 1M/47k .. 1M/27k = 21.3 .. 37.0 = r what the 10k weighting resistors R4 and R6 put back. The minus signs on both

The knob is a rheostat, terminal 3 and the wiper, with terminal 1
tied to the wiper. That short is the point: if grit ever lifts the
wiper, the whole 20k track still bridges the branch, so r goes to
its minimum instead of the r x term disappearing.
SYNCHRONISING TWO BOARDS

Voltages carry the dimensionless variables at 0.1 V per unit, so x swings
+/-2 V, y +/-2.7 V and z runs 0 to 4.8 V. An MPY634 forms A*B/10, so the
product of two 0.1 V/unit signals comes out 100x too small -- which is exactly

would need a -z output, and this circuit does not make one. Run a cable from one board's x output to a second board's SYNC IN X
jack, and tie the two analog grounds together -- a coax screen does
both at once. Both boards float, so with no common ground nothing
happens at all.

of the LF412 Paul never needed -- and held on the lamp's common

products are free: U3 and U4 simply have their differential inputs swapped.

wanders through mixed hues rather than blinking between

The time scale is tau = 1 MEG x C, and C is switchable:

Turn the weight knob up and within a few seconds the second board is
drawing the first board's trajectory, whatever state it was in when
you connected it. Pull the cable off and the two drift apart again
from states that agree to a few millivolts. That is the whole
demonstration, and it needs no switch.

integrator, ahead of the 100 ohm series resistor, so no lamp
current flows in the BNC output impedance.

off
g = 7 they never lock however long you wait; above it they lock in a ON

POWER: USB-C 5 V in, +/-12 V out

about 25 mA per rail; the 2 W module is rated +/-66 mA

RV2 is a divider across the incoming signal, so the weight is linear
in the knob: g = 1M/100k x (fraction turned) = 0 to 10. Below about

All four are printed on the back of the board, next to the switch.

couple of seconds. At the counter-clockwise stop the wiper is on
too, but only with R1 changed as well, and there is no knob for s. ground and the branch contributes nothing, exactly as if unplugged.

Paul's original ran on a bench +/-15 V supply and used 2000 pF, 0.1 uF and

The coupling lands on the r x term, so it also adds g to the
receiving board's own r: drive at r = 32 and the receiver's r knob
reads 32 down to 22 as the sync knob goes 0 to full.

stocks a 3-pole 3-position switch; 2.2 nF is always fitted. Both banks
ON adds a fourth speed Paul never had. Poles 1-3 switch in the
470 nF and poles 4-6 the 100 nF, so the six sliders read left to
right as a two-digit binary number counting 00, 01, 10, 11.

x gets the jack because the knob absorbs that offset. -y would lock

5.1k on each CC line tells a
USB-C source to supply 5 V

JP1 open: the analog ground floats,

it, so no mains-referenced loop runs
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

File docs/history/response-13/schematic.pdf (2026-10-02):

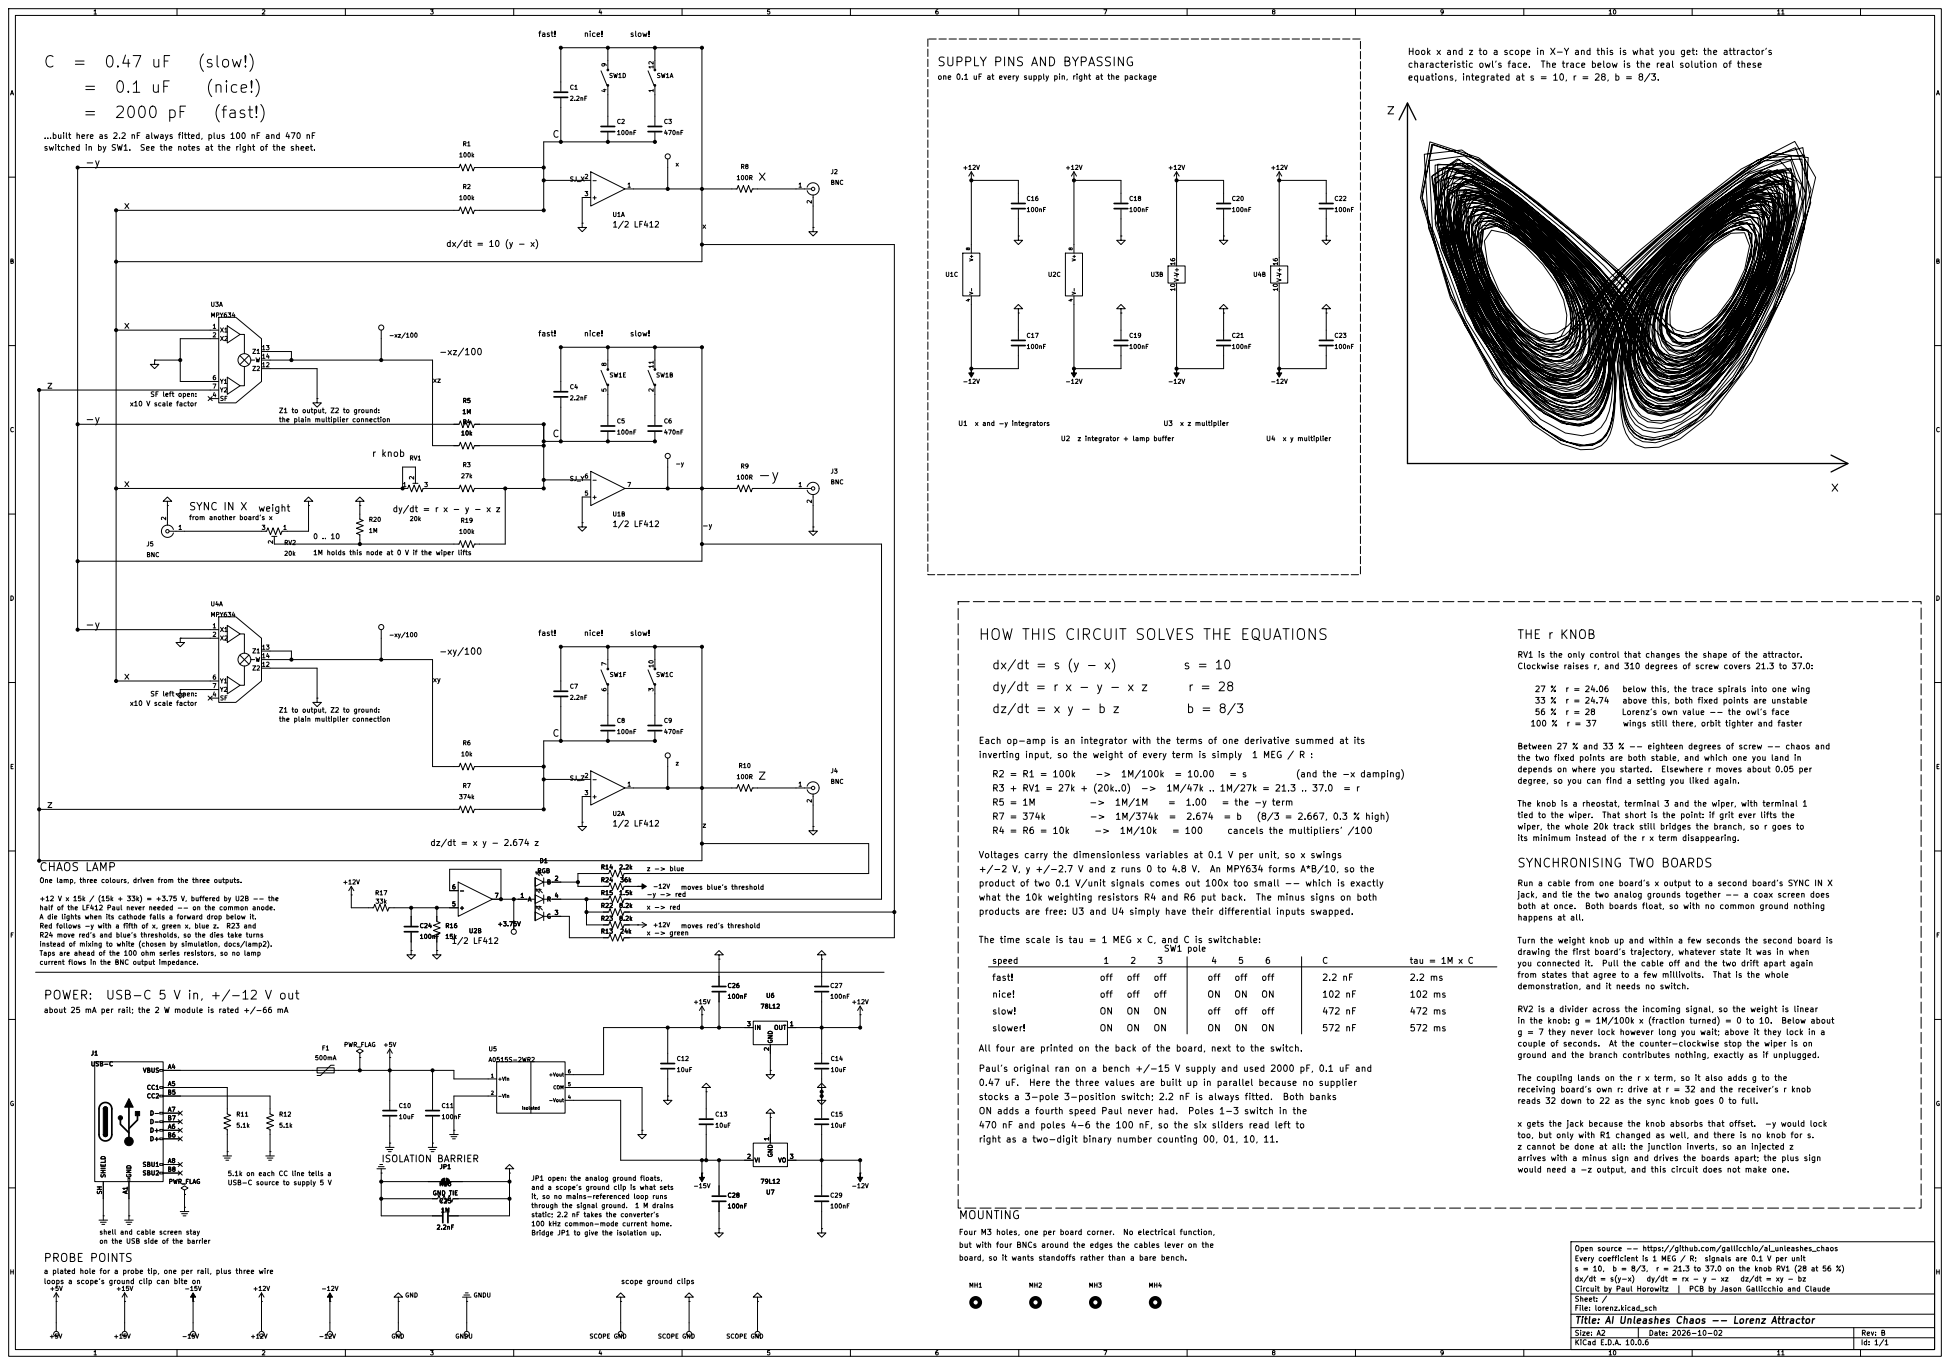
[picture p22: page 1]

SUPPLY PINS AND BYPASSING

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

one 0.1 uF at every supply pin, right at the package

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

Z1 to output, Z2 to ground: the plain multiplier connection

U2 z integrator + lamp buffer U3 x z multiplier

x10 V scale factor SYNC IN X

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

Each op-amp is an integrator with the terms of one derivative summed at its

inverting input, so the weight of every term is simply 1 MEG / R : moves blue's threshold

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

One lamp, three colours, driven from the three outputs.
half of the LF412 Paul never needed -- on the common anode. R24 move red's and blue's thresholds, so the dies take turns
A die lights when its cathode falls a forward drop below it. Red follows -y with a fifth of x, green x, blue z. R23 and

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

products are free: U3 and U4 simply have their differential inputs swapped.

The time scale is tau = 1 MEG x C, and C is switchable:

too, but only with R1 changed as well, and there is no knob for s. Turn the weight knob up and within a few seconds the second board is
drawing the first board's trajectory, whatever state it was in when
you connected it. Pull the cable off and the two drift apart again
from states that agree to a few millivolts. That is the whole
demonstration, and it needs no switch.

RV2 is a divider across the incoming signal, so the weight is linear current flows in the BNC output impedance.
off shell and cable screen stay a plated hole for a probe tip, one per rail, plus three wire
z cannot be done at all: the junction inverts, so an injected z POWER: USB-C 5 V in, +/-12 V out

in the knob: g = 1M/100k x (fraction turned) = 0 to 10. Below about

All four are printed on the back of the board, next to the switch.

couple of seconds. At the counter-clockwise stop the wiper is on

Paul's original ran on a bench +/-15 V supply and used 2000 pF, 0.1 uF and
0.47 uF. Here the three values are built up in parallel because no supplier
stocks a 3-pole 3-position switch; 2.2 nF is always fitted. Both banks
ON adds a fourth speed Paul never had. Poles 1-3 switch in the
470 nF and poles 4-6 the 100 nF, so the six sliders read left to

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

x gets the jack because the knob absorbs that offset. -y would lock

arrives with a minus sign and drives the boards apart; the plus sign

JP1 open: the analog ground floats,
through the signal ground. 1 M drains 100 kHz common-mode current home. and a scope's ground clip is what sets
it, so no mains-referenced loop runs

Bridge JP1 to give the isolation up. static; 2.2 nF takes the converter's

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

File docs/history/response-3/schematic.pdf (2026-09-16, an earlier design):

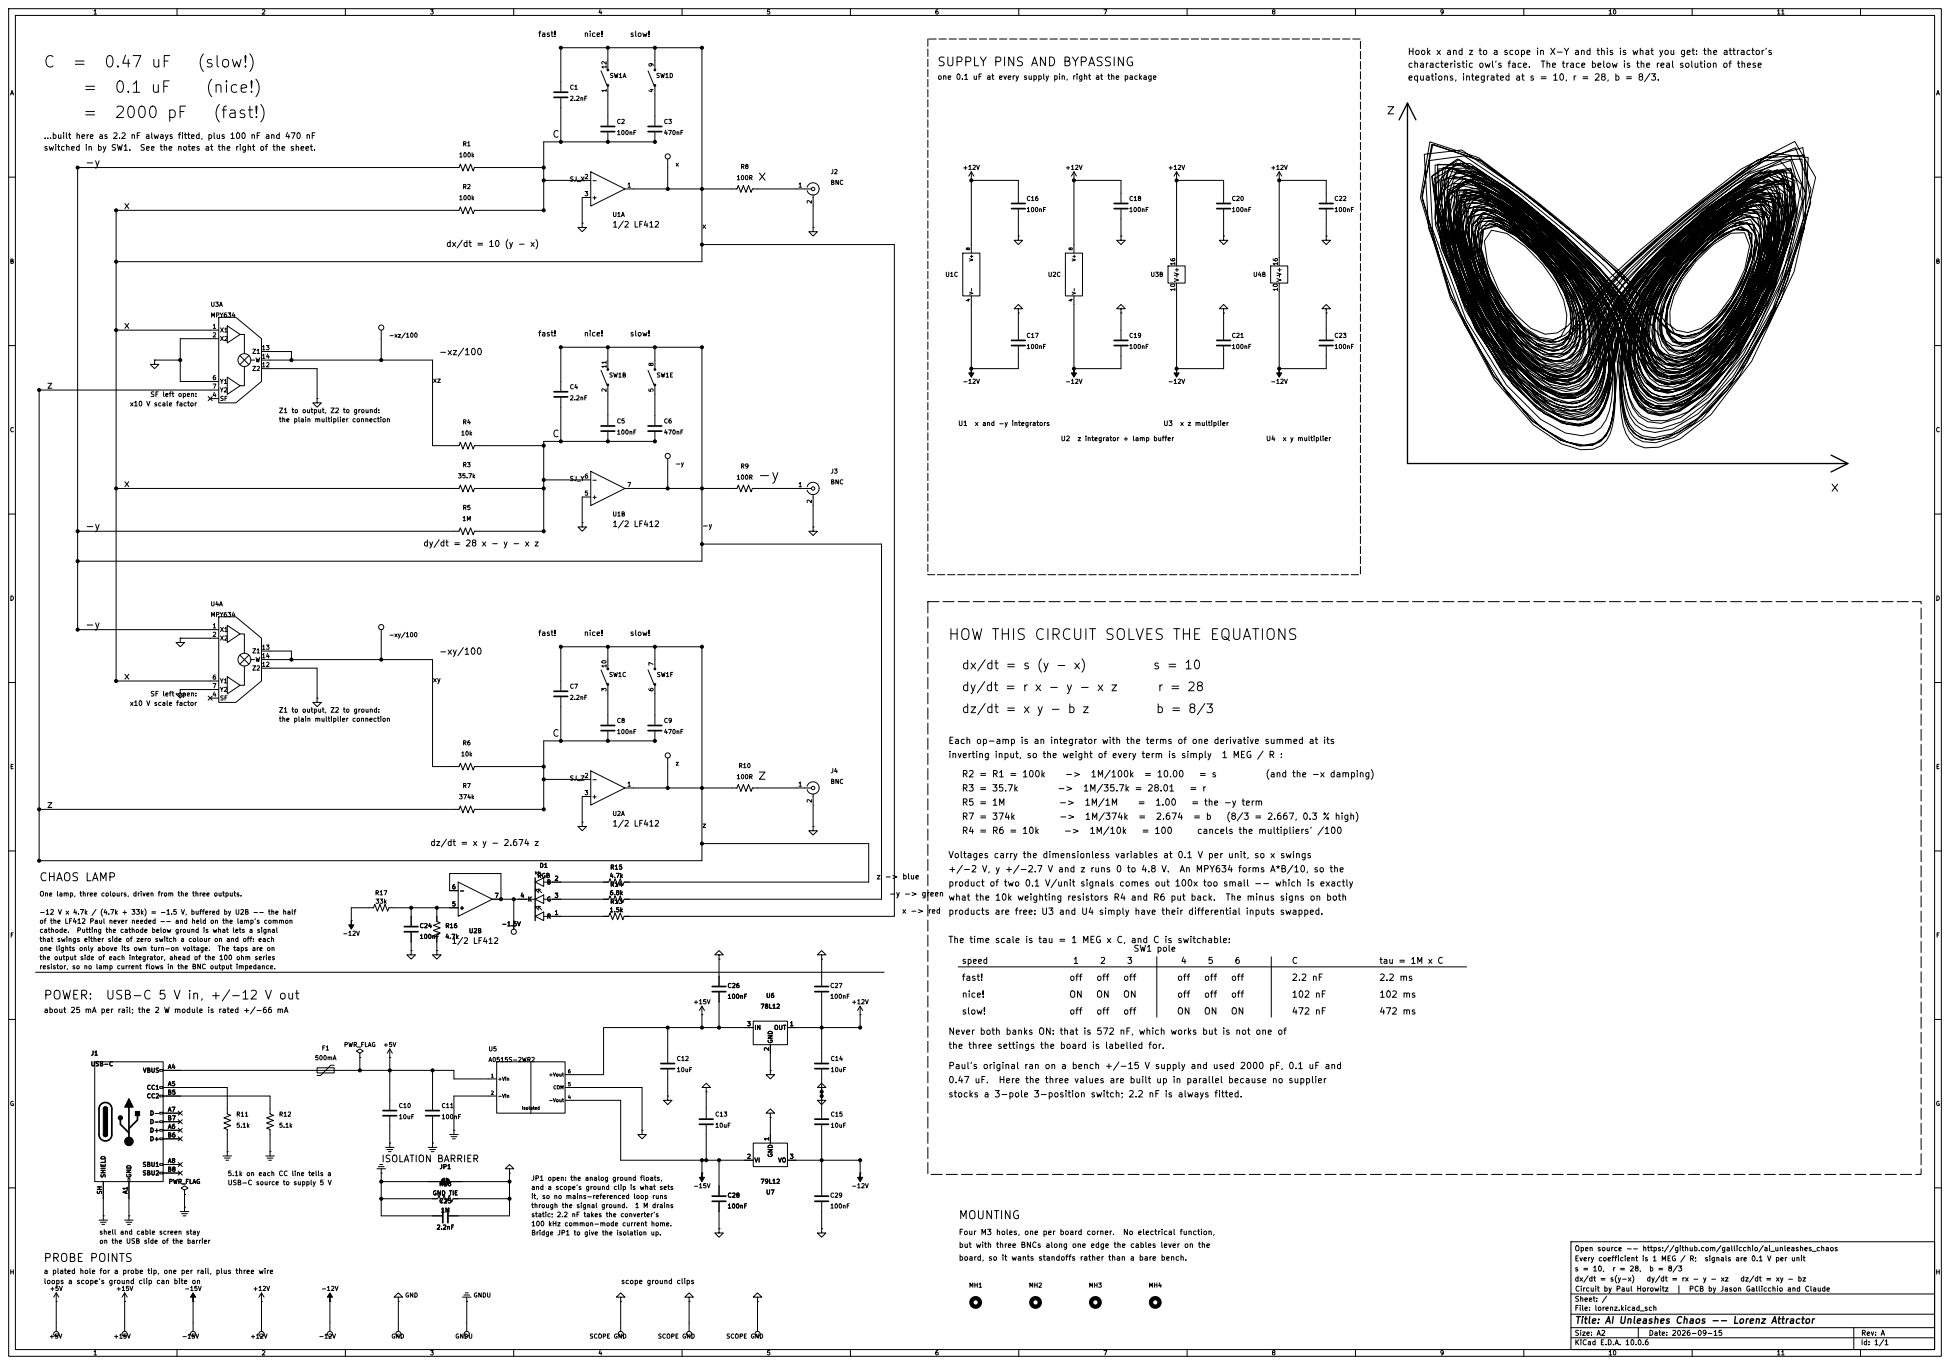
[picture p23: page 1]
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

one 0.1 uF at every supply pin, right at the package

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

the plain multiplier connection Z1 to output, Z2 to ground:

HOW THIS CIRCUIT SOLVES THE EQUATIONS

Z1 to output, Z2 to ground: SF left open: x

the plain multiplier connection

Each op-amp is an integrator with the terms of one derivative summed at its
inverting input, so the weight of every term is simply 1 MEG / R : 6

Voltages carry the dimensionless variables at 0.1 V per unit, so x swings
+/-2 V, y +/-2.7 V and z runs 0 to 4.8 V. An MPY634 forms A*B/10, so the
product of two 0.1 V/unit signals comes out 100x too small -- which is exactly
what the 10k weighting resistors R4 and R6 put back. The minus signs on both
products are free: U3 and U4 simply have their differential inputs swapped.

that swings either side of zero switch a colour on and off: each One lamp, three colours, driven from the three outputs. one lights only above its own turn-on voltage. The taps are on -12 V x 4.7k / (4.7k + 33k) = -1.5 V, buffered by U2B -- the half POWER: USB-C 5 V in, +/-12 V out

of the LF412 Paul never needed -- and held on the lamp's common
resistor, so no lamp current flows in the BNC output impedance. cathode. Putting the cathode below ground is what lets a signal

The time scale is tau = 1 MEG x C, and C is switchable:

the output side of each integrator, ahead of the 100 ohm series

about 25 mA per rail; the 2 W module is rated +/-66 mA

Never both banks ON: that is 572 nF, which works but is not one of
the three settings the board is labelled for.

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

GNDU 5.1k on each CC line tells a a plated hole for a probe tip, one per rail, plus three wire

JP1 open: the analog ground floats,
it, so no mains-referenced loop runs and a scope's ground clip is what sets

Bridge JP1 to give the isolation up. static; 2.2 nF takes the converter's 100 kHz common-mode current home.

Four M3 holes, one per board corner. No electrical function,
but with three BNCs along one edge the cables lever on the
board, so it wants standoffs rather than a bare bench.

on the USB side of the barrier

Open source -- https://github.com/gallicchio/ai_unleashes_chaos +12V

Every coefficient is 1 MEG / R; signals are 0.1 V per unit
Circuit by Paul Horowitz | PCB by Jason Gallicchio and Claude
Sheet: /
File: lorenz.kicad_sch
Title: AI Unleashes Chaos -- Lorenz Attractor

loops a scope's ground clip can bite on

Size: A2 | Rev: A
KiCad E.D.A. 10.0.6 | Id: 1/1

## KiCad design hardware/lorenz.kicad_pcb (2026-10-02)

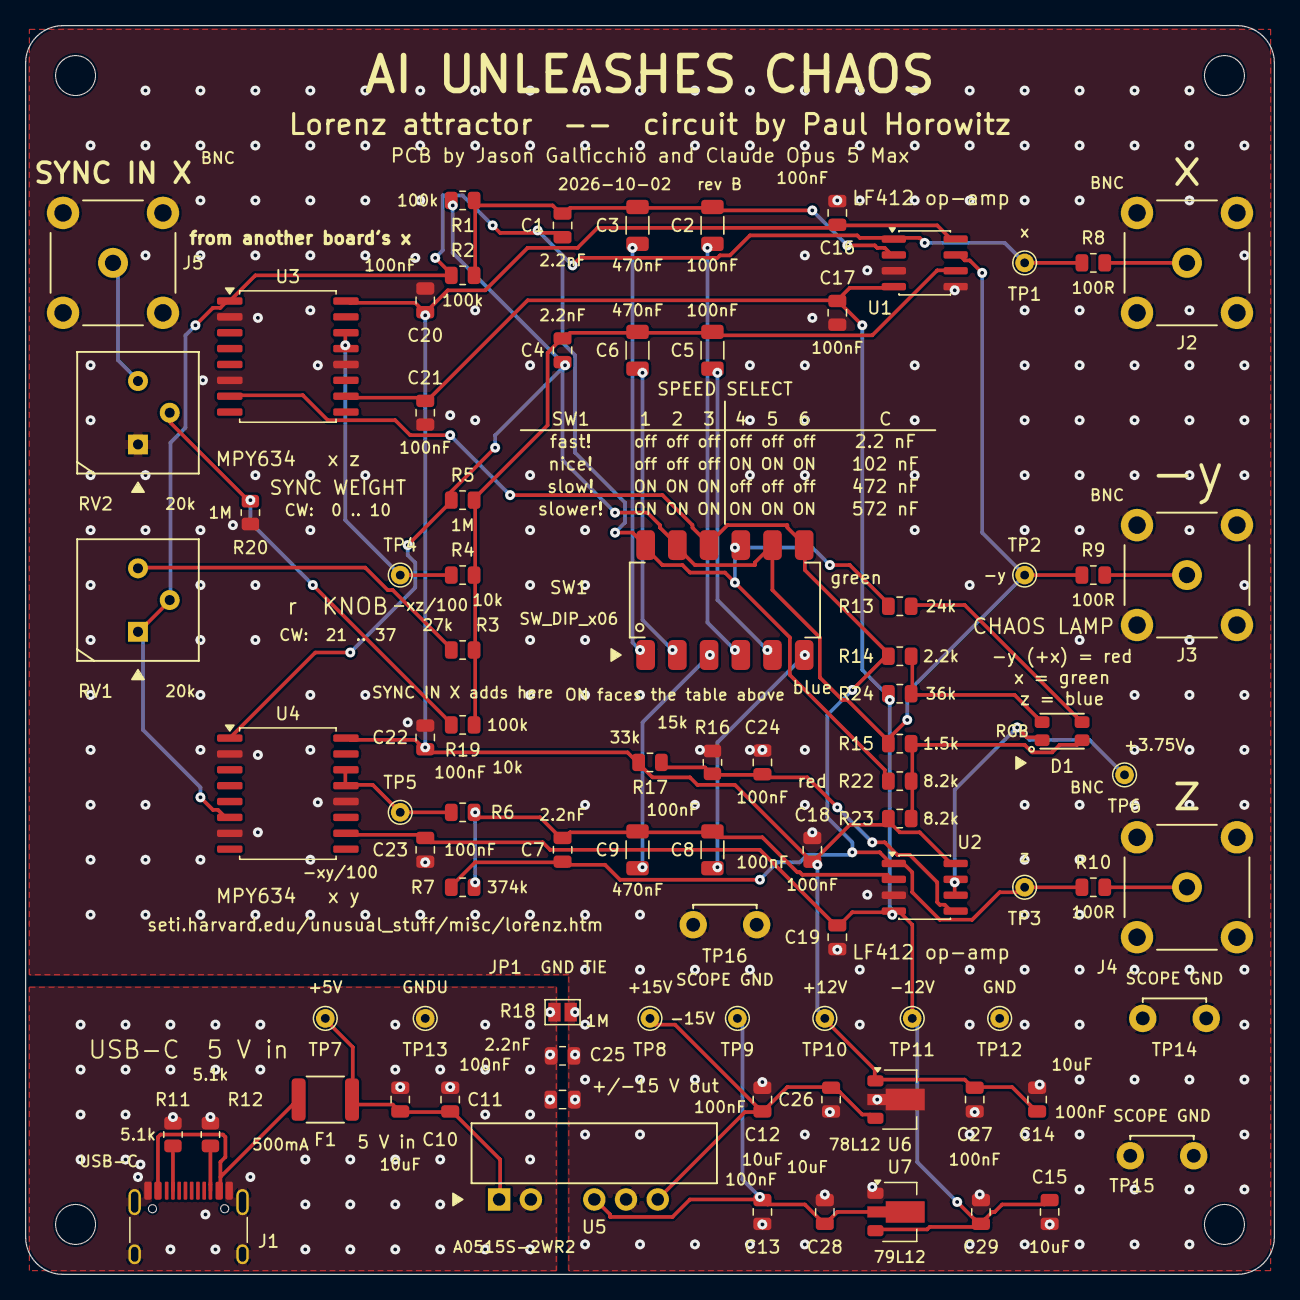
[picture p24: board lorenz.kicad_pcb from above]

Board: 2 copper layers, 100.0 x 100.0 mm, 90 parts (0 on the bottom side), 35 nets.

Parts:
C1, C4, C7, C25: 2.2nF; C_0805_2012Metric
C2, C5, C8: 100nF; C_1206_3216Metric
C3, C6, C9: 470nF; C_1206_3216Metric
C10, C12, C13, C14, C15: 10uF; C_0805_2012Metric
C11, C16, C17, C18, C19, C20, C21, C22, C23, C24, C26, C27, C28, C29: 100nF; C_0805_2012Metric
D1: RGB; LED_RGB_PLCC4_3.5x2.8mm
F1: 500mA; PTC_1812_4532Metric
J1: USB-C; USB_C_Receptacle_HRO_TYPE-C-31-M-12
J2, J3, J4, J5: BNC; BNC_KYWE_RightAngle
JP1: GND TIE; SolderJumper-2_P1.3mm_Open_Pad1.0x1.5mm
MH1, MH2, MH3, MH4: MountingHole; MountingHole_3.2mm_M3
R1, R2, R19: 100k; R_0805_2012Metric
R3: 27k; R_0805_2012Metric
R4, R6: 10k; R_0805_2012Metric
R5, R18, R20: 1M; R_0805_2012Metric
R7: 374k; R_0805_2012Metric
R8, R9, R10: 100R; R_0805_2012Metric
R11, R12: 5.1k; R_0805_2012Metric
R13: 24k; R_0805_2012Metric
R14: 2.2k; R_0805_2012Metric
R15: 1.5k; R_0805_2012Metric
R16: 15k; R_0805_2012Metric
R17: 33k; R_0805_2012Metric
R22, R23: 8.2k; R_0805_2012Metric
R24: 36k; R_0805_2012Metric
RV1, RV2: 20k; Potentiometer_Bourns_3386P_Vertical
SW1: SW_DIP_x06; SW_DIP_SPSTx06_KingTek_DSIC06_P2.54mm
TP1: x; TestPoint_THTPad_D1.5mm_Drill0.7mm
TP2: -y; TestPoint_THTPad_D1.5mm_Drill0.7mm
TP3: z; TestPoint_THTPad_D1.5mm_Drill0.7mm
TP4: -xz/100; TestPoint_THTPad_D1.5mm_Drill0.7mm
TP5: -xy/100; TestPoint_THTPad_D1.5mm_Drill0.7mm
TP6: +3.75V; TestPoint_THTPad_D1.5mm_Drill0.7mm
TP7: +5V; TestPoint_THTPad_D1.5mm_Drill0.7mm
TP8: +15V; TestPoint_THTPad_D1.5mm_Drill0.7mm
TP9: -15V; TestPoint_THTPad_D1.5mm_Drill0.7mm
TP10: +12V; TestPoint_THTPad_D1.5mm_Drill0.7mm
TP11: -12V; TestPoint_THTPad_D1.5mm_Drill0.7mm
TP12: GND; TestPoint_THTPad_D1.5mm_Drill0.7mm
TP13: GNDU; TestPoint_THTPad_D1.5mm_Drill0.7mm
TP14, TP15, TP16: SCOPE GND; TestPoint_ScopeGnd_Loop_2x1.1mm
U1, U2: LF412; SOIC-8_3.9x4.9mm_P1.27mm
U3, U4: MPY634; SOIC-16W_7.5x10.3mm_P1.27mm
U5: A0515S-2WR2; DCDC_SIP_A05xxS_1W_2W
U6: 78L12; SOT-89-3
U7: 79L12; SOT-89-3

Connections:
+5V: C10.1, C11.1, F1.2, TP7.1, U5.1
+12V: C14.1, C16.1, C18.1, C20.1, C22.1, C27.2, R17.1, R23.2, TP10.1, U1.8, U2.8, U3.16, U4.16, U6.1
+15V: C12.1, C26.2, TP8.1, U5.6, U6.3
-12V: C15.2, C17.2, C19.2, C21.2, C23.2, C29.1, R24.2, TP11.1, U1.4, U2.4, U3.10, U4.10, U7.3
-15V: C13.2, C28.1, TP9.1, U5.4, U7.2
/-y: C4.1, R1.1, R5.1, R9.1, R15.2, SW1.8, SW1.11, TP2.1, U1.7, U4.1
/SJ_X: C1.2, C2.2, C3.2, R1.2, R2.2, U1.2
/SJ_Y: C4.2, C5.2, C6.2, R3.2, R4.2, R5.2, R19.2, U1.6
/SJ_Z: C7.2, C8.2, C9.2, R6.2, R7.2, U2.2
/x: C1.1, R2.1, R8.1, R13.2, R22.2, RV1.1, RV1.2, SW1.9, SW1.12, TP1.1, U1.1, U3.1, U4.6
/xy: R6.1, TP5.1, U4.13, U4.14
/xz: R4.1, TP4.1, U3.13, U3.14
/z: C7.1, R7.1, R10.1, R14.2, SW1.7, SW1.10, TP3.1, U2.1, U3.7
GND: C12.2, C13.1, C14.2, C15.1, C16.2, C17.1, C18.2, C19.1, C20.2, C21.1, C22.2, C23.1, C24.2, C25.2, C26.1, C27.1, C28.2, C29.2, J2.2, J3.2, J4.2, J5.2, JP1.2, R16.2, R18.2, R20.1, RV2.1, TP12.1, TP14.1, TP15.1, TP16.1, U1.3, U1.5, U2.3, U3.2, U3.6, U3.12, U4.2, U4.7, U4.12, U5.5, U6.2, U7.1
GNDU: C10.2, C11.2, C25.1, J1.A1, J1.A12, J1.B1, J1.B12, J1.SH, JP1.1, R11.2, R12.2, R18.1, TP13.1, U5.2
unnamed: C2.1, SW1.4
unnamed: C3.1, SW1.1
unnamed: C5.1, SW1.5
unnamed: C6.1, SW1.2
unnamed: C8.1, SW1.6
unnamed: C9.1, SW1.3
unnamed: D1.1, TP6.1, U2.6, U2.7
unnamed: D1.2, R14.1, R24.1
unnamed: D1.3, R13.1
unnamed: D1.4, R15.1, R22.1, R23.1
unnamed: F1.1, J1.A4, J1.A9, J1.B4, J1.B9
unnamed: J1.A5, R11.1
unnamed: J1.B5, R12.1
unnamed: J2.1, R8.2
unnamed: J3.1, R9.2
unnamed: J4.1, R10.2
unnamed: J5.1, RV2.3
unnamed: R3.1, RV1.3
unnamed: R19.1, R20.2, RV2.2
unnamed: C24.1, R16.1, R17.2, U2.5

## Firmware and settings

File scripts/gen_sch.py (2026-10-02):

#!/usr/bin/env python3
"""Draw the Lorenz attractor schematic, laid out the way Paul draws it.

Three integrator rows stacked down the sheet, the two multipliers in the gaps
on the left feeding the middle of rows 2 and 3, and the three outputs returning
along lanes on the left to feed everything back.  Every signal is a drawn wire;
only the supply rails use labels.
"""
import os, sys
sys.path.insert(0, os.path.dirname(os.path.abspath(__file__)))
import kienv, parts
from schlib import Sheet
from lorenz_curve import owl_xz

HERE = os.path.dirname(os.path.abspath(__file__))
LIB = os.path.join(HERE, "..", "hardware", "lib", "lorenz.kicad_sym")
OUT = os.path.join(HERE, "..", "hardware", "lorenz.kicad_sch")

# ------------------------------------------------------------ geometry -----
BUS_Z, BUS_NY, BUS_X = 19.05, 30.48, 41.91
GNDCOL   = 60.96          # where the multipliers' grounded inputs turn down
MULT_CX  = 80.01          # multiplier body centre
ZJOG     = 101.6          # column for the multipliers' Z2-to-ground stub
JOG_X    = 135.89         # column the multiplier outputs drop down
RES_CX   = 146.05         # summing resistors  (pins 142.24 / 149.86)
SJ_X     = 168.91         # summing-junction rail
SJ_MERGE = 157.48         # where the x branch and the sync branch meet
OPA_X    = 187.96         # op-amp body        (-in 180.34, out 195.58)
OUT_X    = 215.9          # output node
RS_CX    = 228.6          # 100 ohm series resistor
BNC_X    = 248.92         # BNC jack           (signal pin at 243.84)
C_FAST, C_NICE, C_SLOW = 173.99, 187.96, 201.93  # capacitor-bank branches

ROW_Y = (63.5, 152.4, 241.3)
RET_DY = 21.59            # output return lane, below each row
BANK_LO, BANK_HI = 13.97, 41.91   # capacitor bank rails, above each row

MULT_Y = (114.3, 203.2)   # U3, U4 body centres -- in the gaps between rows

# the chaos lamp, in the band below the third row
RGB_R, RGB_G, RGB_B = 269.24, 274.32, 279.4
LED_CX, BUF_CX = 114.3, 160.02


def fp(key):
    return parts.PARTS[key]["footprint"]


def rfp():
    return parts.PARTS["R_0805"]["footprint"]


def passive_fields(value):
    p = parts.PASSIVES.get(value)
    return {"LCSC": p["lcsc"], "MPN": p["mpn"]} if p else {}


def part_fields(key):
    p = parts.PARTS[key]
    return {"LCSC": p["lcsc"], "MPN": p["mpn"]}


def build():
    s = Sheet(kienv.share_dir(), paper="A2",
              title="AI Unleashes Chaos -- Lorenz Attractor",
              date=parts.BOARD_DATE, rev=parts.REV,
              company="Circuit by Paul Horowitz  |  PCB by Jason Gallicchio and Claude",
              comments=["dx/dt = s(y-x)   dy/dt = rx - y - xz   dz/dt = xy - bz",
                        "s = 10,  b = 8/3,  r = 21.3 to 37.0 on the knob RV1 (28 at 56 %)",
                        "Every coefficient is 1 MEG / R;  signals are 0.1 V per unit",
                        "Open source -- https://github.com/gallicchio/ai_unleashes_chaos"])
    s.add_local_lib(LIB, "lorenz")

    pwr_n = [0]

    def pwr_ref():
        pwr_n[0] += 1
        return f"#PWR{pwr_n[0]:02d}"

    def gnd(x, y, key="", up=False, net="GND"):
        """Drop a ground symbol; `up` flips it for a wire arriving from below.

        Two grounds exist on this board.  GND is everything downstream of the
        isolated converter -- the analog circuit, the BNC shells, the scope's
        ground.  GNDU is the USB side.  They meet only at R18/C25/JP1.
        """
        lib = "power:GND" if net == "GND" else "lorenz:GNDU"
        s.place(lib, pwr_ref(), net, x, y, rot=180 if up else 0,
                in_bom=False, on_board=False, hide_ref=True, hide_value=True)

    tp_n = [0]

    def testpoint(x, y, name, rot=180, dx=2.54, dy=0.6, justify="left",
                  loop=False):
        """A probe pad on the board, carrying the name of what it probes.

        The name is the symbol's value, so it reaches the board as a legend
        beside the pad: a probe pad nobody can identify is not a probe pad.
        """
        tp_n[0] += 1
        ref = f"TP{tp_n[0]}"
        s.place("Connector:TestPoint", ref, name, x, y, rot=rot,
                footprint=parts.PARTS["SCOPE_GND" if loop else "TESTPOINT"]
                ["footprint"],
                in_bom=False, hide_ref=True,
                val_off=(dx, dy), val_justify=justify)
        return ref

    def rail(name, x, y, rot=0, to=None):
        s.place(f"power:{name}", pwr_ref(),
                name, x, y, rot=rot, in_bom=False, on_board=False,
                hide_ref=True, val_off=(0, -3.81) if rot == 0 else (0, 3.81))
        if to is not None:
            s.wire((x, y), (x, to))

    # =================================================== the three rows =====
    rows = [
        dict(  # dx/dt = 10(y - x)
            opa=("U1", 1), out="x", y=ROW_Y[0],
            res=[("R1", "100k", -6.35, "-y"), ("R2", "100k", +6.35, "x")],
            caps=("C1", "C2", "C3"), poles=(4, 1), outres="R8", bnc="J2",
            label="x", sj="SJ_X", colour="green", die="3", note="dx/dt = 10 (y - x)"),
        dict(  # dy/dt = 28x - y - xz
            opa=("U1", 2), out="-y", y=ROW_Y[1],
            res=[("R5", "1M", -19.05, "-y"), ("R4", "10k", -12.7, "xz"),
                 ("R3", "27k", 0.0, "x")],
            caps=("C4", "C5", "C6"), poles=(5, 2), outres="R9", bnc="J3",
            label="-y", sj="SJ_Y", colour="blue", die="2", note="dy/dt = r x - y - x z"),
        dict(  # dz/dt = xy - (8/3) z
            opa=("U2", 1), out="z", y=ROW_Y[2],
            res=[("R6", "10k", -6.35, "xy"), ("R7", "374k", +6.35, "z")],
            caps=("C7", "C8", "C9"), poles=(6, 3), outres="R10", bnc="J4",
            label="z", sj="SJ_Z", colour="red", die="4", note="dz/dt = x y - 2.674 z"),
    ]

    feeds = {"x": [], "-y": [], "z": []}      # (x_start, y) horizontal bus taps

    def knob(ry):
        """RV1, the r trimmer, in series with R3 ahead of the summing node.

        r = 1 MEG / (R3 + RV1), so 27k + 0..20k sweeps r from 37.0 down to
        21.3 -- through the pitchfork at r = 1 and the Hopf bifurcation at
        r = 24.74, which is what makes the knob worth turning.
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

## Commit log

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2026-09-15 Add KiCad tooling, S-expression parser, custom symbols and footprints
    Symbols are drawn the way Paul draws them: inverting input on top of the
    op-amp triangle, the multiplier as a right-pointing wedge with the (x) glyph.
    Footprints are dimensioned from the manufacturer drawings cited in each file;
    the DC/DC footprint deliberately takes both the 1 W and 2 W module.
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2026-09-15 Schematic: full Lorenz sheet, ERC clean, equations verified from the netlist
    check_circuit.py does not trust the drawing -- it reads the exported netlist,
    works out what each integrator computes from the resistors actually attached,
    and compares against the Lorenz equations. It recovers s = 10, r = 28.01,
    b = 2.6738 (8/3 + 0.27 %) and checks the multiplier hookup, the virtual
    earths, matched capacitors, outputs and supplies: 60 checks, all passing.
    ERC reports 0 violations. Two generator-level guards were added along the
    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
    [lorenz.kicad_sch]
2026-09-15 Schematic polish: project design rules, clean power section, owl plot
    Design rules in the .kicad_pro are tighter than the cheapest tier at JLCPCB,
    NextPCB and CircuitHub, so a board that passes DRC here passes at all three.
    The owl's face on the sheet is the real trajectory, integrated by
    lorenz_curve.py at s=10, r=28, b=8/3.
    [lorenz.kicad_sch]
2026-09-15 PCB: placement, maze router and ground planes; DRC down to silkscreen
    route.py is a grid A* over the copper layers with true distance-based
    clearance (box inflation wrongly blocks the diagonal escape from a 0.5 mm
    pitch USB-C pad). Ground is poured on both layers and stitched, so only the
    27 signal and supply nets are searched: 427 tracks, 174 vias, 8 seconds.
    Four real bugs were found and fixed by DRC along the way: vias were checked
    against track clearance rather than their own; a custom-shaped pad (the SOT-89
    tab) is not centred on its anchor, so tracks ran over it; a track halo has to
    include the *next* track's half width; and a net must be allowed onto its own
    copper, or a 0.3 mm pad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
    [lorenz.kicad_pcb]
2026-09-15 PCB routing complete: 0 unconnected, 0 parity issues
    Ground stitching now places a via beside every ground pad as well as on a
    lattice, which is what finally tied the last island of the front pour to the
    plane. Zones use THT_THERMAL: solid on SMD pads (too small for two spokes)
    and relieved on through-hole pads so they stay hand-solderable.
    [lorenz.kicad_pcb]
2026-09-15 Silkscreen: legends, port labels, speed table, equations and the owl
    Every legend is placed by trial against a map of the real pad rectangles and
    the footprints' own outlines, so nothing lands on copper; anything that cannot
    be fitted is reported rather than dropped. The front carries what you need
    with the board in hand, the back carries the equations, Paul's parameters and
    the attractor the outputs draw. DRC: 0 violations.
    [lorenz.kicad_pcb]
2026-09-15 Four-layer variant: signal / ground / +12V / signal, DRC clean
    The inner power plane is tied to the routed +12 V net by vias dropped onto its
    own tracks -- a stitching via merely near a pad works for ground only because
    ground is poured on the pad's own layer too.
    [lorenz-4layer.kicad_pcb, lorenz-4layer.kicad_sch]
2026-09-15 One-command build, fab package, cost document, and a .gitignore fix
    make.py rebuilds symbols, footprints, schematic and both PCBs from scratch and
    refuses to finish unless ERC, the circuit checker, DRC with schematic parity
    and the fab-package checks all come back clean -- 41 seconds end to end.
    The .gitignore inherited from the Python template had unanchored 'lib/' and
    'parts/' rules, which were quietly excluding hardware/lib/ -- the project's own
    symbol and footprint libraries were not in the repository at all.
    [lorenz-4layer-B_Cu.gbr, lorenz-4layer-B_Mask.gbr, lorenz-4layer-B_Paste.gbr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]
2026-09-15 M3 mounting holes, and a schematic layout checker that caught their caption
    check_schematic.py estimates every text item's extent from KiCad's stroke font
    and reports overlaps, strays outside the frame, and anything landing in the
    title block. It found the one note that had drifted off the left edge, and
    then immediately caught the mounting-hole caption when I dropped it on top of
    the title block.
    [lorenz-4layer-B_Cu.gbr, lorenz-4layer-B_Mask.gbr, lorenz-4layer-B_Paste.gbr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]
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2026-09-15 3D models, images and renders in the build; answer the follow-up questions
    Simple VRML bodies for the parts KiCad's bundled 3D set has no model for (the
    BNCs, the converter, the USB-C shell, the 1812 fuse), so the render shows the
    board as it will look. KiCad's VRML reader does not draw the Cylinder
    primitive -- the first attempt gave blocks instead of barrels -- so the BNC
    barrels are written out as explicit faces.
    Every build now writes docs/images/: schematic, both silkscreens, both copper
    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
    [lorenz-4layer-B_Cu.gbr, lorenz-4layer-B_Mask.gbr, lorenz-4layer-B_Paste.gbr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]
2026-09-15 Make the build reproducible: stable UUIDs, pinned timestamps, no duplicate tracks
    pcbnew hands out random UUIDs and writes some collections in UUID order, so two
    builds of an identical design produced files that differed everywhere and a
    diff on a board file was useless. Board items now take a UUID derived from
    what the item is, and placed symbols carry a uuid for every pin of the symbol
    rather than only the unit on the sheet -- KiCad was inventing random ones for
    the rest. Both design files are now byte-identical across builds.
    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
    [lorenz-4layer-B_Cu.gbr, lorenz-4layer-B_Mask.gbr, lorenz-4layer-B_Paste.gbr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]
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2026-09-15 Find KiCad's libraries by asking KiCad, and add ./make.py --clean
    The build failed on another machine with 'Cannot locate KiCad shared data':
    share_dir() assumed <AppDir>/usr/share/kicad, but an extracted AppImage may
    only have <AppDir>/share/kicad, which is in fact the path KiCad's own launcher
    exports as KICAD_STOCK_DATA_HOME. Discovery now asks KiCad for it, searches a
    list of layouts either side of that, honours $KICAD_SHARE_DIR, and on failure
    prints everything it tried instead of one unhelpful line. The build banner
    prints the resolved paths.
    --clean removes exactly what the build writes, which also documents what in
    the repository is generated and what is source. Datasheets are no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
    [lorenz-4layer-B_Cu.gbr, lorenz-4layer-B_Mask.gbr, lorenz-4layer-B_Paste.gbr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]
2026-09-15 Find KiCad's libraries by asking KiCad; add ./make.py --clean
    only have <AppDir>/share/kicad -- which is the path KiCad's own launcher
    exports as KICAD_STOCK_DATA_HOME. Discovery now asks KiCad for it, searches
    the layouts either side of it, honours $KICAD_SHARE_DIR, and on failure prints
    everything it tried. The build banner prints what it resolved.
    --clean removes exactly what the build writes, which also documents what is
    generated and what is source. It immediately earned its keep: the rotation
    self-test was loading a symbol library t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
    [lorenz-4layer-B_Cu.gbr, lorenz-4layer-B_Mask.gbr, lorenz-4layer-B_Paste.gbr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]
2026-09-15 Cross-probing, self-contained 3D models, cropped images, bare mounting holes
    Cross-probing needs two links that were both absent: each footprint carries a
    'path' naming the schematic symbol it came from, and the project lists its root
    sheet. Saving a board through pcbnew rewrites the .kicad_pro and drops that
    sheet entry, so the project files are now regenerated as the last build step.
    gen_models.py was never wired into make.py, so a clean tree had no 3D models
    at all -- which is why the converter and the BNCs were missing for you. It is
    in the build now, the DIP switch has a model of its own rather than borrowing
    an approximate one from KiCad's bundled set (which the AppImage ships only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
    [lorenz-4layer.kicad_pcb, lorenz.kicad_pcb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]
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2026-09-16 Use the isolation, add a chaos lamp and probe pads, drop the four-layer board
    Circuit
    * The converter's isolation is now used. GND (everything a scope touches)
    and GNDU (the USB input and its shell) are separate copper pours with a
    1 mm gap, bridged only by R21 = 1 M, C25 = 2.2 nF and JP1, an open solder
    jumper marked GND TIE. The point is the ground loop: scope earth -> BNC
    shell -> board ground -> USB cable -> laptop -> earth, landing on signals
    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
    [lorenz-4layer-B_Cu.gbr, lorenz-4layer-B_Mask.gbr, lorenz-4layer-B_Paste.gbr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]
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2026-09-16 Rebuild the board around the multipliers, and review the whole design
    Layout. The multipliers move to the far left, into the third of the board
    that was empty, and everything spreads out behind them. Each output row is
    now one straight line -- op-amp, probe pad, the 100 ohm lying horizontally,
    BNC -- so what the probe pad is for needs no explaining. The switch legend
    gets clear board around it, both multipliers and both op-amps say what they
    are, the chaos lamp has its own quarter with its resistors coming in from the
    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
    [lorenz-B_Cu.gbr, lorenz-B_Mask.gbr, lorenz-B_Silkscreen.gbr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]
2026-09-16 Give every probe pad its name directly above it
    JP1's value already said GND TIE; the second label saying the same thing sat
    on top of TP8's, which pushed +15V sideways and made the row ambiguous again.
    [lorenz-B_Cu.gbr, lorenz-B_Mask.gbr, lorenz-B_Silkscreen.gbr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]
2026-09-16 Add an r knob and a sync input, and build the lamp as option 038
    The lamp is now the common-anode MHPA3528CRGBCT held at +3.20 V by U2B,
    with z -> red through 470R, x -> green through 3.9k and -y -> blue
    through 1.5k: option 038 of the hundred renderings. All three peaks land
    within 8 % of each other, so the colour mixes instead of blinking.
    R3 splits into 27k plus RV1, a Bourns 3386P 20k trimmer, sweeping
    r = 21.3 to 37.0 across both bifurcations and Lorenz's 28. Terminal 1 is
    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
    [lorenz-B_Cu.gbr, lorenz-B_Mask.gbr, lorenz-B_Silkscreen.gbr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]
2026-09-16 Say what the sync input needs, and give the notes room to say it
    Two boards both float on purpose, so a bare wire from one board's x to
    the other's SYNC IN does nothing without a ground in common. The
    schematic, DESIGN_NOTES and the response all say so now, and say that a
    coax screen from a BNC splitter does both jobs at once.
    Also corrects the reason z cannot be a sync channel. It is not a
    conditional-Lyapunov obstruction -- sign-correct diffusive coupling on z
    does lock in simulation -- it is that the summing junction inverts, so an
    injected z arrives with a minus sign and drives the two boards apart.
    Getting the plus sign would need a -z output this circuit does not make.
    The lamp not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
    [lorenz.kicad_pcb, lorenz.kicad_sch]
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2026-09-16 Make README a front page and move the conversation to its own file
    README.md is now a short introduction for someone arriving from a link:
    what the board is, the five things about it worth reading a forum post
    for, the three renders, how to build it, and where to go next. The
    prompt-by-prompt conversation that produced the board moves to
    CLAUDE_CODE_CHAT.md, unchanged apart from its title.
    DESIGN_NOTES gains the story the lamp deserved: why choosing it is a
    four-way decision that cannot be made by inspection, what is in the LED
    model (data-sheet I-V, the nonlinear intensity curve, a spectrum, the CIE
    1931 observer, D65 sRGB, and an adaptation curve), the thirteen
    assertions that keep the m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
2026-09-16 README: say what the lamp gallery is, and do not overclaim Pecora-Carroll
    The coupling on this board is diffusive, not the drive-response
    replacement of the 1990 paper; the distinction is drawn properly in
    DESIGN_NOTES, so the front page just says what you will see.
2026-09-16 Find KiCad inside a plain AppImage, and stop believing empty directories
    The build accepted any directory with symbols/ and footprints/ in it as
    KiCad's library tree. ~/.local/share/kicad/10.0 has both and is empty on
    a fresh install -- it is where your *own* libraries go -- so pointing
    KICAD_SHARE_DIR at it passed the check and then failed deep inside a
    symbol lookup. A candidate now has to contain Device.kicad_symdir and
    Resistor_SMD.pretty, and a directory that fails says so by name and is
    skipped rather than adopted.
    A plain, unextracted .AppImage now works with nothing configured. Its
    libraries only exist while it is mounted, so kienv mounts it with
    --appimage-mount, keeps that proc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
2026-09-16 Put the pick-and-place point on the part, and turn six of them for JLC
    RV1, RV2 and U5 were drawn off their own pads in JLCPCB's preview, and no
    rotation fixed it because it was not a rotation. A CPL says where the
    *middle* of a part goes; those three footprints are mine, and I had put
    the anchor on pin 1 -- 2.54 mm out for the trimmers, 7.6 mm across and
    2.6 mm down for the DC/DC module. Both footprints now anchor on the
    centre of the body, and their placements moved by the same amount the
    other way, so every copper, mask, paste, drill and outline file is
    byte-identical; only the CPL and two silkscreen designators change.
    JLCPCB places from its own model of a part, and for six of ours th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
    [lorenz.kicad_pcb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]
2026-09-16 Key the through-hole parts by their holes, and point the pin-1 mark at pin 1
    U5's silkscreen pin-1 dot was 2.2 mm above pin 1, inside the body
    outline, so lining a fab's pin-1 indicator up against it could never
    work. It is gone; U5 now carries the same filled triangle as the lamp,
    the switch and the trimmers, outside the outline and pointing at the pad.
    The offset JLCPCB's preview draws for U5 and the trimmers is their model
    origin, not our coordinate: a CPL cannot say "use your origin, not mine",
    and moving the number to flatter a preview would be wrong for the machine
    and for every other fab. What settles it instead is that those parts'
    hole patterns do not map onto themselves under a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
    [lorenz.kicad_pcb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]
2026-09-17 Put the USB-C where its drawing says, not where DRC preferred
    The HRO recommended layout puts the board edge 5.79 mm in front of the
    upper shell-tab centre, so the connector's mating face overhangs the edge
    by 0.99 mm. Two other numbers in the same chain -- 1.64 from the signal
    pad row to the upper tab, 4.18 between the tabs -- match KiCad's land
    pattern exactly, so the datum is certain.
    The board had the edge at +4.15 instead of +2.66: the face sat half a
    millimetre inside the laminate, which is the thing a moulded plug body
    hits. The reason is the mistake worth recording. In prompt 4 the
    footprint's silkscreen ran past where the edge had to be, DRC objected,
    and the connector was moved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
    [lorenz-B_Cu.gbr, lorenz-B_Mask.gbr, lorenz-B_Silkscreen.gbr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]
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2026-09-30 Correct the lamp model against the rev A boards, and search again
    The rev A lamp came back mostly blue and green, with red almost never
    seen. The board is option 038 exactly -- netlist, part and orientation
    all check -- so the fault was the model it was chosen with:
    * every die conducted 0.3-0.45 V too early (ideality 3.2 and 5);
    * light went as (I/20 mA)^gamma with gamma > 1 for all three, which the
    design notes wrongly said came from the datasheet. InGaN (green,
    blue) is more efficient at a milliamp than at 20 mA; AlGaInP (red)
    is less. At the lamp's currents green and blue are two to three
    times brighter relative to red than modelled.
    lamp_model.py keeps rev A's m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
2026-10-02 Rev B: build the top-scoring chaos lamp, and clear J1's silk from the edge
    The lamp becomes candidate 1 of docs/lamp2: common anode at +3.75 V
    (R16 15k), red fed from -y through 1.5k with x blended in through 8.2k
    and +12 V through 8.2k, green from x through 24k, blue from z through
    2.2k with -12 V through 36k. Three resistors more than rev A, all
    JLCPCB Basic parts; D1's footprint, place and angle are rev A's, which
    its boards proved. The symbol draws the dies blue, red, green so the
    schematic's feeds still never cross.
    check_circuit.py now reads the lamp back out of the netlist, checks it
    is that wiring, and simulates it with the corrected LED model: 0.82 at
    slow!, against rev A's 0.33.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
    [lorenz-B_Cu.gbr, lorenz-B_Mask.gbr, lorenz-B_Paste.gbr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]
2026-10-02 Answer prompt 13, and correct two stale lines in the manufacturing notes
    MANUFACTURING.md's upload table now names the JLCPCB-corrected CPL, and
    the barrier's bleed resistor is R18, not R21. Response 13 records rev B
    and the checks against rev A.
    Claude-Session: https://claude.ai/code/session_01FyYQ1p4JtCVvJKRozbkYm7
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
